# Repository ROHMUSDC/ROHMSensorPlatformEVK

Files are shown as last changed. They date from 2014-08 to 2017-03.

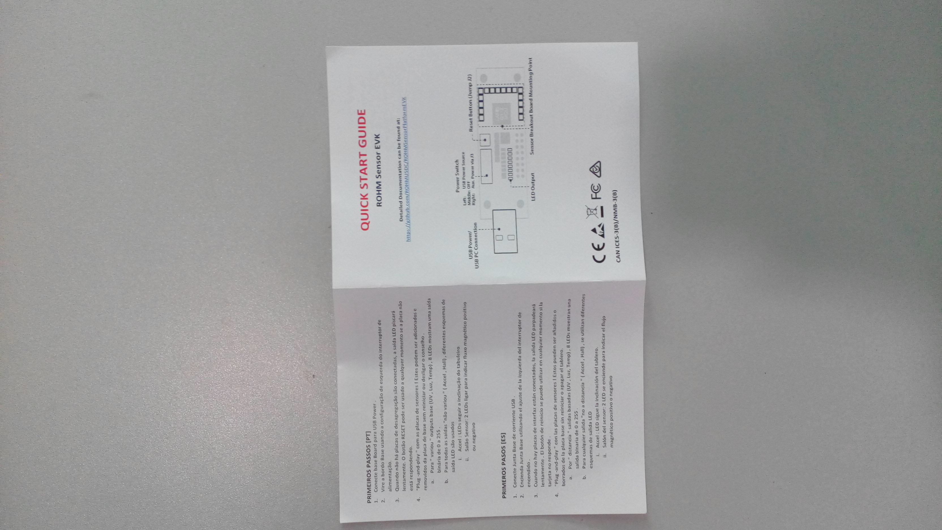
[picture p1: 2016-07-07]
Documentation/CE Declaration of Conformity/technical_documentation/[14]_Photos/IMG_20150430_091640[1].jpg

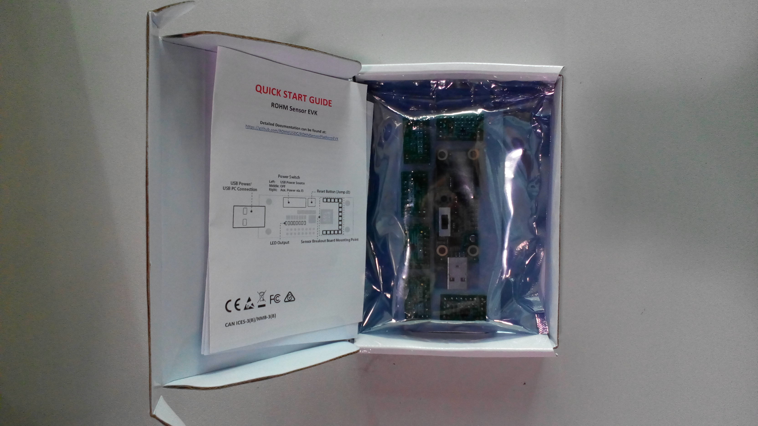
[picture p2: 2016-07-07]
Documentation/CE Declaration of Conformity/technical_documentation/[14]_Photos/IMG_20150430_091804.jpg

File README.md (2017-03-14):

# ROHM Sensor Platform Kit Public Repository
* Part Number: SENSEKIT2-EVK-101
* Description: An Open platform that can be used to quickly evaluate sensor products!
* Developer: USDC Applications Engineering Team, ROHM Semiconductor
* Date Started: November 2014
* ROHM Webpage: http://www.rohm.com/web/global/sensor-platform-kit
* Sensor Kit Promotional Video on EEWEB: http://www.eeweb.com/company-blog/rohm/sensor-platform-kit

----
### Repository Contents
* Documentation Folder: Contains Application Note, MCU Datasheet, and Platform Guide for connecting this board to other device platforms
* Firmware Folder: Contains the Source Code for the ML610Q112 firmware for the Sensor Platform Base Board
* Hardware Design Files: Contains BOM, Schematic, and Layout files for this project
* PC Evaluation Tools: Contains FTDI VCP drivers and a copy of Putty

----
### Updates
* NOTE: The ML8511 and the ML8511A are OBSOLETE parts with no recommended replacement. Even though we still support this part on shield and you can find information for this sensor here; please beware that this sensor is being obsoleted and should not be used for new design.
----
### Where to Purchase
* Digikey: http://www.digikey.com/product-detail/en/SENSEKIT2-EVK-101/SENSEKIT2-EVK-101-ND/5300443
* Mouser: http://www.mouser.com/search/ProductDetail.aspx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
* Farnell, Element 14: http://uk.farnell.com/rohm/sensekit2-evk-101/multi-sense-eval-kit/dp/2475523

----
### FAQ
* Question: 
  * "I would like to try a different initialization setting for one of the sensors.  How would I go about uploading new firmware to the sensor platform's base board?"
* Answer:  
  * It is possible to modify the existing firmware of the base board.
  * Please see the draft document entitled, “ROHM_HowToFlash-TestingGuide_SensorPlatformKit_2015-10-05” for detailed instructions on how to flash the existing base board.
    * Programming Guide Repository Location: …/ROHMSensorPlatformEVK/Documentation/Sensor Platform/ROHM_HowToFlash-TestingGuide_SensorPlatformKit_2015-10-05.pdf
  * Please note that the board’s default firmware source files can also be found in the Sensor Platform Repository:
    * Default Firmware Repository Folder Location: …/ROHMSensorPlatformEVK/Firmware - Base Board ML610Q112 Code
  * Finally, you will need LAPIS Semiconductor’s nanoEase programmer tool to debug and flash the base board.  This additional tool can be purchased on Digikey at the following link:
    * http://www.digikey.com/product-detail/en/NANO-EASE/NANO-EASE-ND/4576425
  * However, if you do not want to purchase the Lapis nanoEase programmer tool, another alternative would be to write some sample code for the platform you may be using.
    * For example, in the sensor kit repository (…/ROHMSensorPlatformEVK/Documentation/Other Platform Guides/ROHM_ConnectingSensorPlatform_Arduino.pdf) you will find a platform guide and Arduino code for using these sensors with the Arduino platform.  By running this, you can easily change your Arduino code and run with the initialization routines you would like to try with this sensor.

* Question:
  * "How to I save logs from this sensor kit?"
* Answer:
  * "Please see the closed Issue #2 in the issues tab of this repository.

----
### Software License
The following are categorized under the GNU General Public License, Version 3:
* Firmware Design. Includes LAPIS ML610Q112 MCU main.c C code

Copyright (C) 2015 USDC Applications Engineering Team, ROHM Semiconductor

This program is free software: you can redistribute it and/or 
modify it under the terms of the GNU General Public License as published 
by the Free Software Foundation, either version 3 of the License, or any 
later version.

This program is distributed in the hope that it will be useful,
but WITHOUT ANY WARRANTY; without even the implied warranty of
MERCHANTABILITY or FITNESS FOR A PARTICULAR PURPOSE.  See the
GNU General Public License for more details.

You should have received a copy of the GNU General Public License
along with this program.  If not, see <http://www.gnu.org/licenses/>.

----
### Hardware License
The following are categorized under the CERN Open Hardware Licence, Version 1.2:
* Hardware Design. Includes Schematic, BOM, Layout

Copyright (C) 2015 USDC Applications Engineering Team, ROHM Semiconductor

This repository contains free hardware design concepts: you can redistribute it and/or 
modify it under the terms of the CERN Open Hardware Licence as published 
by the CERN, either version 1.2 of the License, or any 
later version.

This hardware design is distributed in the hope that it will be useful,
but WITHOUT ANY WARRANTY; without even the implied warranty of
MERCHANTABILITY or FITNESS FOR A PARTICULAR PURPOSE.  See the
CERN Open Hardware Licence for more details.

You should have received a copy of the CERN Open Hardware Licence
along with this program.  If not, see <http://www.ohwr.org/licenses/cern-ohl/v1.2>.

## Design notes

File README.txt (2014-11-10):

ROHM Sensor Platform Kit Public Repository

Description: 
An Open platform that can be used to quickly evaluate sensor products!

Developer: 
USDC Applications Engineering Team, ROHM Semiconductor

Date Opened: 
November 2014

Application Note Information:
Name: ROHM_Sensor_Evaluation_Kit_User_Manual_REV00_2014-10-13.pdf
Location: "Documentation\Sensor Platform"

Schematic/BOM and Layout Files can be found under...
Location: Hardware Design Files Folder
Hardware Design Tools: Orcad Capture and Allegro

----------------------------------------------------------------------
The following are categorized under the GNU General Public License, Version 3
-Hardware Design. Includes Schematic, BOM, Layout
-Firmware Design. Includes LAPIS ML610Q112 MCU C code

Copyright (C) 2014 USDC Applications Engineering Team, ROHM Semiconductor

This program is free software and hardware: you can redistribute it and/or 
modify it under the terms of the GNU General Public License as published 
by the Free Software Foundation, either version 3 of the License, or any 
later version.

This program is distributed in the hope that it will be useful,
but WITHOUT ANY WARRANTY; without even the implied warranty of
MERCHANTABILITY or FITNESS FOR A PARTICULAR PURPOSE.  See the
GNU General Public License for more details.

You should have received a copy of the GNU General Public License
along with this program.  If not, see <http://www.gnu.org/licenses/>.
----------------------------------------------------------------------

                    GNU GENERAL PUBLIC LICENSE
                       Version 3, 29 June 2007

 Copyright (C) 2007 Free Software Foundation, Inc. <http://fsf.org/>
 Everyone is permitted to copy and distribute verbatim copies
 of this license document, but changing it is not allowed.

                            Preamble

  The GNU General Public License is a free, copyleft license for
software and other kinds of works.

  The licenses for most software and other practical works are designed
to take away your freedom to share and change the works.  By contrast,
the GNU General Public License is intended to guarantee your freedom to
share and change all versions of a program--to make sure it remains free
software for all its users.  We, the Free Software Foundation, use the
GNU General Public License for most of our software; it applies also to
any other work released this way by its authors.  You can apply it to
your programs, too.

  When we speak of free software, we are referring to freedom, not
price.  Our General Public Licenses are designed to make sure that you
have the freedom to distribute copies of free software (and charge for
them if you wish), that you receive source code or can get it if you
want it, that you can change the software or use pieces of it in new
free programs, and that you know you can do these things.

  To protect your rights, we need to prevent others from denying you
these rights or asking you to surrender the rights.  Therefore, you have
certain responsibilities if you distribute copies of the software, or if
you modify it: responsibilities to respect the freedom of others.

  For example, if you distribute copies of such a program, whether
gratis or for a fee, you must pass on to the recipients the same
freedoms that you received.  You must make sure that they, too, receive
or can get the source code.  And you must show them these terms so they
know their rights.

  Developers that use the GNU GPL protect your rights with two steps:
(1) assert copyright on the software, and (2) offer you this License
giving you legal permission to copy, distribute and/or modify it.

  For the developers' and authors' protection, the GPL clearly explains
that there is no warranty for this free software.  For both users' and
authors' sake, the GPL requires that modified versions be marked as
changed, so that their problems will not be attributed erroneously to
authors of previous versions.

  Some devices are designed to deny users access to install or run
modified versions of the software inside them, although the manufacturer
can do so.  This is fundamentally incompatible with the aim of
protecting users' freedom to change the software.  The systematic
pattern of such abuse occurs in the area of products for individuals to
use, which is precisely where it is most unacceptable.  Therefore, we
have designed this version of the GPL to prohibit the practice for those
products.  If such problems arise substantially in other domains, we
stand ready to extend this provision to those domains in future versions
of the GPL, as needed to protect the freedom of users.

  Finally, every program is threatened constantly by software patents.
States should not allow patents to restrict development and use of
software on general-purpose computers, but in those that do, we wish to
avoid the special danger that patents applied to a free program could
make it effectively proprietary.  To prevent this, the GPL assures that
patents cannot be used to render the program non-free.

  The precise terms and conditions for copying, distribution and
modification follow.

                       TERMS AND CONDITIONS

  0. Definitions.

  "This License" refers to version 3 of the GNU General Public License.

  "Copyright" also means copyright-like laws that apply to other kinds of
works, such as semiconductor masks.

  "The Program" refers to any copyrightable work licensed under this
License.  Each licensee is addressed as "you".  "Licensees" and
"recipients" may be individuals or organizations.

  To "modify" a work means to copy from or adapt all or part of the work
in a fashion requiring copyright permission, other than the making of an
exact copy.  The resulting work is called a "modified version" of the
earlier work or a work "based on" the earlier work.

  A "covered work" means either the unmodified Program or a work based
on the Program.

  To "propagate" a work means to do anything with it that, without
permission, would make you directly or secondarily liable for
infringement under applicable copyright law, except executing it on a
computer or modifying a private copy.  Propagation includes copying,
distribution (with or without modification), making available to the
public, and in some countries other activities as well.

  To "convey" a work means any kind of propagation that enables other
parties to make or receive copies.  Mere interaction with a user through
a computer network, with no transfer of a copy, is not conveying.

  An interactive user interface displays "Appropriate Legal Notices"
to the extent that it includes a convenient and prominently visible
feature that (1) displays an appropriate copyright notice, and (2)
tells the user that there is no warranty for the work (except to the
extent that warranties are provided), that licensees may convey the
work under this License, and how to view a copy of this License.  If
the interface presents a list of user commands or options, such as a
menu, a prominent item in the list meets this criterion.

  1. Source Code.

  The "source code" for a work means the preferred form of the work
for making modifications to it.  "Object code" means any non-source
form of a work.

  A "Standard Interface" means an interface that either is an official
standard defined by a recognized standards body, or, in the case of
interfaces specified for a particular programming language, one that
is widely used among developers working in that language.

  The "System Libraries" of an executable work include anything, other
than the work as a whole, that (a) is included in the normal form of
packaging a Major Component, but which is not part of that Major
Component, and (b) serves only to enable use of the work with that
Major Component, or to implement a Standard Interface for which an
implementation is available to the public in source code form.  A
"Major Component", in this context, means a major essential component
(kernel, window system, and so on) of the specific operating system
(if any) on which the executable work runs, or a compiler used to
produce the work, or an object code interpreter used to run it.

  The "Corresponding Source" for a work in object code form means all
the source code needed to generate, install, and (for an executable
work) run the object code and to modify the work, including scripts to
control those activities.  However, it does not include the work's
System Libraries, or general-purpose tools or generally available free
programs which are used unmodified in performing those activities but
which are not part of the work.  For example, Corresponding Source
includes interface definition files associated with source files for
the work, and the source code for shared libraries and dynamically
linked subprograms that the work is specifically designed to require,
such as by intimate data communication or control flow between those
subprograms and other parts of the work.

  The Corresponding Source need not include anything that users
can regenerate automatically from other parts of the Corresponding
Source.

  The Corresponding Source for a work in source code form is that
same work.

  2. Basic Permissions.

  All rights granted under this License are granted for the term of
copyright on the Program, and are irrevocable provided the stated
conditions are met.  This License explicitly affirms your unlimited
permission to run the unmodified Program.  The output from running a
covered work is covered by this License only if the output, given its
content, constitutes a covered work.  This License acknowledges your
rights of fair use or other equivalent, as provided by copyright law.

  You may make, run and propagate covered works that you do not
convey, without conditions so long as your license otherwise remains
in force.  You may convey covered works to others for the sole purpose
of having them make modifications exclusively for you, or provide you
with facilities for running those works, provided that you comply with
the terms of this License in conveying all material for which you do
not control copyright.  Those thus making or running the covered works
for you must do so exclusively on your behalf, under your direction
and control, on terms that prohibit them from making any copies of
your copyrighted material outside their relationship with you.

  Conveying under any other circumstances is permitted solely under
the conditions stated below.  Sublicensing is not allowed; section 10
makes it unnecessary.

  3. Protecting Users' Legal Rights From Anti-Circumvention Law.

  No covered work shall be deemed part of an effective technological
measure under any applicable law fulfilling obligations under article
11 of the WIPO copyright treaty adopted on 20 December 1996, or
similar laws prohibiting or restricting circumvention of such
measures.

  When you convey a covered work, you waive any legal power to forbid
circumvention of technological measures to the extent such circumvention
is effected by exercising rights under this License with respect to
the covered work, and you disclaim any intention to limit operation or
modification of the work as a means of enforcing, against the work's
users, your or third parties' legal rights to forbid circumvention of
technological measures.

  4. Conveying Verbatim Copies.

  You may convey verbatim copies of the Program's source code as you
receive it, in any medium, provided that you conspicuously and
appropriately publish on each copy an appropriate copyright notice;
keep intact all notices stating that this License and any
non-permissive terms added in accord with section 7 apply to the code;
keep intact all notices of the absence of any warranty; and give all
recipients a copy of this License along with the Program.

  You may charge any price or no price for each copy that you convey,
and you may offer support or warranty protection for a fee.

  5. Conveying Modified Source Versions.

  You may convey a work based on the Program, or the modifications to
produce it from the Program, in the form of source code under the
terms of section 4, provided that you also meet all of these conditions:

    a) The work must carry prominent notices stating that you modified
    it, and giving a relevant date.

    b) The work must carry prominent notices stating that it is
    released under this License and any conditions added under section
    7.  This requirement modifies the requirement in section 4 to
    "keep intact all notices".

    c) You must license the entire work, as a whole, under this
    License to anyone who comes into possession of a copy.  This
    License will therefore apply, along with any applicable section 7
    additional terms, to the whole of the work, and all its parts,
    regardless of how they are packaged.  This License gives no
    permission to license the work in any other way, but it does not
    invalidate such permission if you have separately received it.

    d) If the work has interactive user interfaces, each must display
    Appropriate Legal Notices; however, if the Program has interactive
    interfaces that do not display Appropriate Legal Notices, your
    work need not make them do so.

  A compilation of a covered work with other separate and independent
works, which are not by their nature extensions of the covered work,
and which are not combined with it such as to form a larger program,
in or on a volume of a storage or distribution medium, is called an
"aggregate" if the compilation and its resulting copyright are not
used to limit the access or legal rights of the compilation's users
beyond what the individual works permit.  Inclusion of a covered work
in an aggregate does not cause this License to apply to the other
parts of the aggregate.

  6. Conveying Non-Source Forms.

  You may convey a covered work in object code form under the terms
of sections 4 and 5, provided that you also convey the
machine-readable Corresponding Source under the terms of this License,
in one of these ways:

    a) Convey the object code in, or embodied in, a physical product
    (including a physical distribution medium), accompanied by the
    Corresponding Source fixed on a durable physical medium
    customarily used for software interchange.

    b) Convey the object code in, or embodied in, a physical product
    (including a physical distribution medium), accompanied by a
    written offer, valid for at least three years and valid for as
    long as you offer spare parts or customer support for that product
    model, to give anyone who possesses the object code either (1) a
    copy of the Corresponding Source for all the software in the
    product that is covered by this License, on a durable physical
    medium customarily used for software interchange, for a price no
    more than your reasonable cost of physically performing this
    conveying of source, or (2) access to copy the
    Corresponding Source from a network server at no charge.

    c) Convey individual copies of the object code with a copy of the
    written offer to provide the Corresponding Source.  This
    alternative is allowed only occasionally and noncommercially, and
    only if you received the object code with such an offer, in accord
    with subsection 6b.

    d) Convey the object code by offering access from a designated
    place (gratis or for a charge), and offer equivalent access to the
    Corresponding Source in the same way through the same place at no
    further charge.  You need not require recipients to copy the
    Corresponding Source along with the object code.  If the place to
    copy the object code is a network server, the Corresponding Source
    may be on a different server (operated by you or a third party)
    that supports equivalent copying facilities, provided you maintain
    clear directions next to the object code saying where to find the
    Corresponding Source.  Regardless of what server hosts the
    Corresponding Source, you remain obligated to ensure that it is
    available for as long as needed to satisfy these requirements.

    e) Convey the object code using peer-to-peer transmission, provided
    you inform other peers where the object code and Corresponding
    Source of the work are being offered to the general public at no
    charge under subsection 6d.

  A separable portion of the object code, whose source code is excluded
from the Corresponding Source as a System Library, need not be
included in conveying the object code work.

  A "User Product" is either (1) a "consumer product", which means any
tangible personal property which is normally used for personal, family,
or household purposes, or (2) anything designed or sold for incorporation
into a dwelling.  In determining whether a product is a consumer product,
doubtful cases shall be resolved in favor of coverage.  For a particular
product received by a particular user, "normally used" refers to a
typical or common use of that class of product, regardless of the status
of the particular user or of the way in which the particular user
actually uses, or expects or is expected to use, the product.  A product
is a consumer product regardless of whether the product has substantial
commercial, industrial or non-consumer uses, unless such uses represent
the only significant mode of use of the product.

  "Installation Information" for a User Product means any methods,
procedures, authorization keys, or other information required to install
and execute modified versions of a covered work in that User Product from
a modified version of its Corresponding Source.  The information must
suffice to ensure that the continued functioning of the modified object
code is in no case prevented or interfered with solely because
modification has been made.

  If you convey an object code work under this section in, or with, or
specifically for use in, a User Product, and the conveying occurs as
part of a transaction in which the right of possession and use of the
User Product is transferred to the recipient in perpetuity or for a
fixed term (regardless of how the transaction is characterized), the
Corresponding Source conveyed under this section must be accompanied
by the Installation Information.  But this requirement does not apply
if neither you nor any third party retains the ability to install
modified object code on the User Product (for example, the work has
been installed in ROM).

  The requirement to provide Installation Information does not include a
requirement to continue to provide support service, warranty, or updates
for a work that has been modified or installed by the recipient, or for
the User Product in which it has been modified or installed.  Access to a
network may be denied when the modification itself materially and
adversely affects the operation of the network or violates the rules and
protocols for communication across the network.

  Corresponding Source conveyed, and Installation Information provided,
in accord with this section must be in a format that is publicly
documented (and with an implementation available to the public in
source code form), and must require no special password or key for
unpacking, reading or copying.

  7. Additional Terms.

  "Additional permissions" are terms that supplement the terms of this
License by making exceptions from one or more of its conditions.
Additional permissions that are applicable to the entire Program shall
be treated as though they were included in this License, to the extent
that they are valid under applicable law.  If additional permissions
apply only to part of the Program, that part may be used separately
under those permissions, but the entire Program remains governed by
this License without regard to the additional permissions.

  When you convey a copy of a covered work, you may at your option
remove any additional permissions from that copy, or from any part of
it.  (Additional permissions may be written to require their own
removal in certain cases when you modify the work.)  You may place
additional permissions on material, added by you to a covered work,
for which you have or can give appropriate copyright permission.

  Notwithstanding any other provision of this License, for material you
add to a covered work, you may (if authorized by the copyright holders of
that material) supplement the terms of this License with terms:

    a) Disclaiming warranty or limiting liability differently from the
    terms of sections 15 and 16 of this License; or

    b) Requiring preservation of specified reasonable legal notices or
    author attributions in that material or in the Appropriate Legal
    Notices displayed by works containing it; or

    c) Prohibiting misrepresentation of the origin of that material, or
    requiring that modified versions of such material be marked in
    reasonable ways as different from the original version; or

    d) Limiting the use for publicity purposes of names of licensors or
    authors of the material; or

    e) Declining to grant rights under trademark law for use of some
    trade names, trademarks, or service marks; or

    f) Requiring indemnification of licensors and authors of that
    material by anyone who conveys the material (or modified versions of
    it) with contractual assumptions of liability to the recipient, for
    any liability that these contractual assumptions directly impose on
    those licensors and authors.

  All other non-permissive additional terms are considered "further
restrictions" within the meaning of section 10.  If the Program as you
received it, or any part of it, contains a notice stating that it is
governed by this License along with a term that is a further
restriction, you may remove that term.  If a license document contains
a further restriction but permits relicensing or conveying under this
License, you may add to a covered work material governed by the terms
of that license document, provided that the further restriction does
not survive such relicensing or conveying.

  If you add terms to a covered work in accord with this section, you
must place, in the relevant source files, a statement of the
additional terms that apply to those files, or a notice indicating
where to find the applicable terms.

  Additional terms, permissive or non-permissive, may be stated in the
form of a separately written license, or stated as exceptions;
the above requirements apply either way.

  8. Termination.

  You may not propagate or modify a covered work except as expressly
provided under this License.  Any attempt otherwise to propagate or
modify it is void, and will automatically terminate your rights under
this License (including any patent licenses granted under the third
paragraph of section 11).

  However, if you cease all violation of this License, then your
license from a particular copyright holder is reinstated (a)
provisionally, unless and until the copyright holder explicitly and
finally terminates your license, and (b) permanently, if the copyright
holder fails to notify you of the violation by some reasonable means
prior to 60 days after the cessation.

  Moreover, your license from a particular copyright holder is
reinstated permanently if the copyright holder notifies you of the
violation by some reasonable means, this is the first time you have
received notice of violation of this License (for any work) from that
copyright holder, and you cure the violation prior to 30 days after
your receipt of the notice.

  Termination of your rights under this section does not terminate the
licenses of parties who have received copies or rights from you under
this License.  If your rights have been terminated and not permanently
reinstated, you do not qualify to receive new licenses for the same
material under section 10.

  9. Acceptance Not Required for Having Copies.

  You are not required to accept this License in order to receive or
run a copy of the Program.  Ancillary propagation of a covered work
occurring solely as a consequence of using peer-to-peer transmission
to receive a copy likewise does not require acceptance.  However,
nothing other than this License grants you permission to propagate or
modify any covered work.  These actions infringe copyright if you do
not accept this License.  Therefore, by modifying or propagating a
covered work, you indicate your acceptance of this License to do so.

  10. Automatic Licensing of Downstream Recipients.

  Each time you convey a covered work, the recipient automatically
receives a license from the original licensors, to run, modify and
propagate that work, subject to this License.  You are not responsible
for enforcing compliance by third parties with this License.

  An "entity transaction" is a transaction transferring control of an
organization, or substantially all assets of one, or subdividing an
organization, or merging organizations.  If propagation of a covered
work results from an entity transaction, each party to that
transaction who receives a copy of the work also receives whatever
licenses to the work the party's predecessor in interest had or could
give under the previous paragraph, plus a right to possession of the
Corresponding Source of the work from the predecessor in interest, if
the predecessor has it or can get it with reasonable efforts.

  You may not impose any further restrictions on the exercise of the
rights granted or affirmed under this License.  For example, you may
not impose a license fee, royalty, or other charge for exercise of
rights granted under this License, and you may not initiate litigation
(including a cross-claim or counterclaim in a lawsuit) alleging that
any patent claim is infringed by making, using, selling, offering for
sale, or importing the Program or any portion of it.

  11. Patents.

  A "contributor" is a copyright holder who authorizes use under this
License of the Program or a work on which the Program is based.  The
work thus licensed is called the contributor's "contributor version".

  A contributor's "essential patent claims" are all patent claims
owned or controlled by the contributor, whether already acquired or
hereafter acquired, that would be infringed by some manner, permitted
by this License, of making, using, or selling its contributor version,
but do not include claims that would be infringed only as a
consequence of further modification of the contributor version.  For
purposes of this definition, "control" includes the right to grant
patent sublicenses in a manner consistent with the requirements of
this License.

  Each contributor grants you a non-exclusive, worldwide, royalty-free
patent license under the contributor's essential patent claims, to
make, use, sell, offer for sale, import and otherwise run, modify and
propagate the contents of its contributor version.

  In the following three paragraphs, a "patent license" is any express
agreement or commitment, however denominated, not to enforce a patent
(such as an express permission to practice a patent or covenant not to
sue for patent infringement).  To "grant" such a patent license to a
party means to make such an agreement or commitment not to enforce a
patent against the party.

  If you convey a covered work, knowingly relying on a patent license,
and the Corresponding Source of the work is not available for anyone
to copy, free of charge and under the terms of this License, through a
publicly available network server or other readily accessible means,
then you must either (1) cause the Corresponding Source to be so
available, or (2) arrange to deprive yourself of the benefit of the
patent license for this particular work, or (3) arrange, in a manner
consistent with the requirements of this License, to extend the patent
license to downstream recipients.  "Knowingly relying" means you have
actual knowledge that, but for the patent license, your conveying the
covered work in a country, or your recipient's use of the covered work
in a country, would infringe one or more identifiable patents in that
country that you have reason to believe are valid.

  If, pursuant to or in connection with a single transaction or
arrangement, you convey, or propagate by procuring conveyance of, a
covered work, and grant a patent license to some of the parties
receiving the covered work authorizing them to use, propagate, modify
or convey a specific copy of the covered work, then the patent license
you grant is automatically extended to all recipients of the covered
work and works based on it.

  A patent license is "discriminatory" if it does not include within
the scope of its coverage, prohibits the exercise of, or is
conditioned on the non-exercise of one or more of the rights that are
specifically granted under this License.  You may not convey a covered
work if you are a party to an arrangement with a third party that is
in the business of distributing software, under which you make payment
to the third party based on the extent of your activity of conveying
the work, and under which the third party grants, to any of the
parties who would receive the covered work from you, a discriminatory
patent license (a) in connection with copies of the covered work
conveyed by you (or copies made from those copies), or (b) primarily
for and in connection with specific products or compilations that
contain the covered work, unless you entered into that arrangement,
or that patent license was granted, prior to 28 March 2007.

  Nothing in this License shall be construed as excluding or limiting
any implied license or other defenses to infringement that may
otherwise be available to you under applicable patent law.

  12. No Surrender of Others' Freedom.

  If conditions are imposed on you (whether by court order, agreement or
otherwise) that contradict the conditions of this License, they do not
excuse you from the conditions of this License.  If you cannot convey a
covered work so as to satisfy simultaneously your obligations under this
License and any other pertinent obligations, then as a consequence you may
not convey it at all.  For example, if you agree to terms that obligate you
to collect a royalty for further conveying from those to whom you convey
the Program, the only way you could satisfy both those terms and this
License would be to refrain entirely from conveying the Program.

  13. Use with the GNU Affero General Public License.

  Notwithstanding any other provision of this License, you have
permission to link or combine any covered work with a work licensed
under version 3 of the GNU Affero General Public License into a single
combined work, and to convey the resulting work.  The terms of this
License will continue to apply to the part which is the covered work,
but the special requirements of the GNU Affero General Public License,
section 13, concerning interaction through a network will apply to the
combination as such.

  14. Revised Versions of this License.

  The Free Software Foundation may publish revised and/or new versions of
the GNU General Public License from time to time.  Such new versions will
be similar in spirit to the present version, but may differ in detail to
address new problems or concerns.

  Each version is given a distinguishing version number.  If the
Program specifies that a certain numbered version of the GNU General
Public License "or any later version" applies to it, you have the
option of following the terms and conditions either of that numbered
version or of any later version published by the Free Software
Foundation.  If the Program does not specify a version number of the
GNU General Public License, you may choose any version ever published
by the Free Software Foundation.

  If the Program specifies that a proxy can decide which future
versions of the GNU General Public License can be used, that proxy's
public statement of acceptance of a version permanently authorizes you
to choose that version for the Program.

  Later license versions may give you additional or different
permissions.  However, no additional obligations are imposed on any
author or copyright holder as a result of your choosing to follow a
later version.

  15. Disclaimer of Warranty.

  THERE IS NO WARRANTY FOR THE PROGRAM, TO THE EXTENT PERMITTED BY
APPLICABLE LAW.  EXCEPT WHEN OTHERWISE STATED IN WRITING THE COPYRIGHT
HOLDERS AND/OR OTHER PARTIES PROVIDE THE PROGRAM "AS IS" WITHOUT WARRANTY
OF ANY KIND, EITHER EXPRESSED OR IMPLIED, INCLUDING, BUT NOT LIMITED TO,
THE IMPLIED WARRANTIES OF MERCHANTABILITY AND FITNESS FOR A PARTICULAR
PURPOSE.  THE ENTIRE RISK AS TO THE QUALITY AND PERFORMANCE OF THE PROGRAM
IS WITH YOU.  SHOULD THE PROGRAM PROVE DEFECTIVE, YOU ASSUME THE COST OF
ALL NECESSARY SERVICING, REPAIR OR CORRECTION.

  16. Limitation of Liability.

  IN NO EVENT UNLESS REQUIRED BY APPLICABLE LAW OR AGREED TO IN WRITING
WILL ANY COPYRIGHT HOLDER, OR ANY OTHER PARTY WHO MODIFIES AND/OR CONVEYS
THE PROGRAM AS PERMITTED ABOVE, BE LIABLE TO YOU FOR DAMAGES, INCLUDING ANY
GENERAL, SPECIAL, INCIDENTAL OR CONSEQUENTIAL DAMAGES ARISING OUT OF THE
USE OR INABILITY TO USE THE PROGRAM (INCLUDING BUT NOT LIMITED TO LOSS OF
DATA OR DATA BEING RENDERED INACCURATE OR LOSSES SUSTAINED BY YOU OR THIRD
PARTIES OR A FAILURE OF THE PROGRAM TO OPERATE WITH ANY OTHER PROGRAMS),
EVEN IF SUCH HOLDER OR OTHER PARTY HAS BEEN ADVISED OF THE POSSIBILITY OF
SUCH DAMAGES.

  17. Interpretation of Sections 15 and 16.

  If the disclaimer of warranty and limitation of liability provided
above cannot be given local legal effect according to their terms,
reviewing courts shall apply local law that most closely approximates
an absolute waiver of all civil liability in connection with the
Program, unless a warranty or assumption of liability accompanies a
copy of the Program in return for a fee.

                     END OF TERMS AND CONDITIONS

            How to Apply These Terms to Your New Programs

  If you develop a new program, and you want it to be of the greatest
possible use to the public, the best way to achieve this is to make it
free software which everyone can redistribute and change under these terms.

  To do so, attach the following notices to the program.  It is safest
to attach them to the start of each source file to most effectively
state the exclusion of warranty; and each file should have at least
the "copyright" line and a pointer to where the full notice is found.

    <one line to give the program's name and a brief idea of what it does.>
    Copyright (C) <year>  <name of author>

    This program is free software: you can redistribute it and/or modify
    it under the terms of the GNU General Public License as published by
    the Free Software Foundation, either version 3 of the License, or
    (at your option) any later version.

    This program is distributed in the hope that it will be useful,
    but WITHOUT ANY WARRANTY; without even the implied warranty of
    MERCHANTABILITY or FITNESS FOR A PARTICULAR PURPOSE.  See the
    GNU General Public License for more details.

    You should have received a copy of the GNU General Public License
    along with this program.  If not, see <http://www.gnu.org/licenses/>.

Also add information on how to contact you by electronic and paper mail.

  If the program does terminal interaction, make it output a short
notice like this when it starts in an interactive mode:

    <program>  Copyright (C) <year>  <name of author>
    This program comes with ABSOLUTELY NO WARRANTY; for details type `show w'.
    This is free software, and you are welcome to redistribute it
    under certain conditions; type `show c' for details.

The hypothetical commands `show w' and `show c' should show the appropriate
parts of the General Public License.  Of course, your program's commands
might be different; for a GUI interface, you would use an "about box".

  You should also get your employer (if you work as a programmer) or school,
if any, to sign a "copyright disclaimer" for the program, if necessary.
For more information on this, and how to apply and follow the GNU GPL, see
<http://www.gnu.org/licenses/>.

  The GNU General Public License does not permit incorporating your program
into proprietary programs.  If your program is a subroutine library, you
may consider it more useful to permit linking proprietary applications with
the library.  If this is what you want to do, use the GNU Lesser General
Public License instead of this License.  But first, please read
<http://www.gnu.org/philosophy/why-not-lgpl.html>.

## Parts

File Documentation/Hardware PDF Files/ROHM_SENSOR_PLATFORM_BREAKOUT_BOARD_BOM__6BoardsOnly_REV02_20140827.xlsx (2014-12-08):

Sensor Platform - Breakout Board Schematics
Revision 01
Bill Of Materials
Item | Quantity | Reference | Part | PCB Footprint | DESCRIPTION | MFG1 | MFG1_PART# | DISTR1 | DISTR1_PART# | DNP
1 | 7 | C6,C7,C20,C22,C23,C35,C50 | 0.1uF | C0402 | CAP CER 0.1UF 10V 10% X5R 0402 | Murata | GRM155R61A104KA01D | DIGIKEY | 490-1318-1-ND
2 | 4 | C9,C24 | 1uF | C0402 | CAP CER 1UF 6.3V 10% X5R 0402 | Murata | GRM155R60J105KE19D | DIGIKEY | 490-1320-1-ND
3 | 1 | C21 | 1nF | C0402 | CAP CER 1000PF 50V 10% X7R 0402 | Murata | GRM155R71H102KA01D | DIGIKEY | 490-1303-1-ND
4 | 1 | C78 | 22uF | C0805 | CAP CER 22UF 6.3V 20% X5R 0805 | Samsung Electro-Mechanics America, Inc | CL21A226MQQNNNE | DIGIKEY | 1276-1100-1-ND
5 | 2 | J6,J7 | 3-PIN Jumper | HDR_THVT_1X3_100 | BERGSTIK II .100" SR STRAIGHT | FCI | 68000-103HLF | DIGIKEY | 609-3461-ND
6 | 3 | R22 | 1K | R0402 | RES 1K OHM 1/16W 1% 0402 SMD | Rohm | MCR01MRTF1001 | DIGIKEY | RHM1.00KCDCT-ND
7 | 11 | R130,R162,R167,R169,R188,R198,R200,R213,R234,R235,R237 | 0 | R0603 | RES 0.0 OHM 1/10W JUMP 0603 SMD | Rohm | MCR03ERTJ000 | DIGIKEY | RHM0.0CGTR-ND
8 | 3 | R32 | 10K | R0402 | RES 10K OHM 1/16W 1% 0402 SMD | Rohm | MCR01MRTF1002 | DIGIKEY | RHM10.0KCDCT-ND
9 | 1 | R129 | 4.7K | R0603 | RES 4.7K OHM 1/10W 1% 0603 SMD | Rohm | MCR03ERTF4701 | DIGIKEY | RHM4.70KCFCT-ND
10 | 1 | R132 | 5.6K | R0402 | RES 5.6K OHM 1/16W 1% 0402 SMD | Rohm | TRR01MZPF5601 | DIGIKEY | RHM5.6KBHCT-ND
11 | 12 | U9,U12,U50,U58,U65,U111,U11,U14,U46,U60,U67,U113 | SensorInterfaceHeader_1 | HDR_THVT_1X5_100 | CONN HEADER VERT SGL 5POS GOLD | 3M | 961105-6404-AR | DIGIKEY | 3M9450-ND
13 | 6 | U16,U17,U32,U52,U61,U112 | SensorInterfaceHeader_3 | HDR_THVT_1X6_100 | CONN HEADER VERT SGL 6POS GOLD | 3M | 961106-6404-AR | DIGIKEY | 3M9451-ND
14 | 1 | U13 | BH1721FVC | WSOF5 | IC AMBIENT LIGHT SENSOR WSOF5 | Rohm | BH1721FVC-TR | DIGIKEY | BH1721FVCCT-ND
15 | 1 | U10 | BH1620FVC | WSOF5 | IC AMBIENT LIGHT SENSOR WSOF5 | Rohm | BH1620FVC-TR | DIGIKEY | BH1620FVCCT-ND
20 | 1 | U51 | BDE0600G | SSOP5 | IC TEMP SENSOR THERM 60°C SSOP5 | Rohm | BDE0600G-TR | DIGIKEY | BDE0600GCT-ND
22 | 1 | U59 | ML8511 | TQFN12 | UV SENSOR W/AMP TQFN12 | Rohm | ML8511-00FCZ05B | DIGIKEY | ML8511-00FCZ05BCT-ND
24 | 1 | U66 | KMX61 | LGA_3x3x0P9 | MAGNETOMETER AND ACCELEROMETER TRI-AXIS LGA16 | Kionix/Rohm | KMX61 | TBD | TBD
26 | 1 | U110 | BU52011HFV | HVSOF5 | IC HALL EFFECT SW BIPO HVSOF5 | Rohm | BU52011HFV-TR | DIGIKEY | BU52011HFVCT-ND
28 | 2 |  |  |  | Shunt jumper for header J6, J7 (item #5), CONN SHUNT 2POS GOLD W/HANDLE | TE Connectivity | 881545-1 | DIGIKEY | 881545-1-ND
29 | 27 | R128,R161,R163,R164,R165,R166,R168,R170,R171,R172,R185,R186,R187,R189,R190,R197,R199,R201,R202,R209,R210,R211,R212,R214,R233,R236,R238 | 0 | R0603 | RES 0.0 OHM 1/10W JUMP 0603 SMD | Rohm | MCR03ERTJ000 | DIGIKEY | RHM0.0CGTR-ND | Do Not Place
30 | 1 | R131 | 4.7K | R0603 | RES 4.7K OHM 1/10W 1% 0603 SMD | Rohm | MCR03ERTF4701 | DIGIKEY | RHM4.70KCFCT-ND | Do Not Place

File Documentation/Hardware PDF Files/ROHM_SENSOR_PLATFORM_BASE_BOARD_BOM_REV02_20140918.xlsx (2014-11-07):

Sensor Platform - Base Board BOM
Revision: 02.0
Bill Of Materials
Item | Quantity | Reference | Part | PCB Footprint | DESCRIPTION | MFG1 | MFG1_PART# | DISTR1 | DISTR1_PART# | DNP | Provided by ROHM | ROHM Comment
1 | 2 | C1,C3 | 0.47uF | C0402 | CAP CER 0.47UF 6.3V 10% X5R 0402 | Samsung Electro-Mechanics America, Inc | CL05A474KQ5NNNC | DIGIKEY | 1276-1479-1-ND |  | No
2 | 3 | C4,C30,C33 | 0.01uF | C0402 | CAP CER 10000PF 25V 10% X7R 0402 | Taiyo Yuden | TMK105B7103KV-F | DIGIKEY | 587-1223-1-ND |  | No
3 | 1 | C5 | 4.7uF | C0402 | CAP CER 4.7UF 6.3V 20% X5R 0402 | Murata | GRM155R60J475ME47D | DIGIKEY | 490-5915-1-ND |  | No
4 | 1 | C27 | 4.7uF | SM_4P3x4P3 | CAP ALUM 4.7UF 25V 20% SMD | Nichicon | UUT1E4R7MCL1GS | DIGIKEY | 493-6252-1-ND |  | No
5 | 3 | C28,C29,C34 | 0.1uF | C0402 | CAP CER 0.1UF 10V 10% X5R 0402 | Murata | GRM155R61A104KA01D | DIGIKEY | 490-1318-1-ND |  | No
6 | 2 | C31,C32 | 47pF | C0402 | CAP CER 47PF 50V 1% NP0 0402 | Murata | GRM1555C1H470FA01D | DIGIKEY | 490-6241-1-ND |  | No
7 | 1 | D1 | 20V 3A | SOD-123F | DIODE SCHOTTKY 20V 3A PMDU | Rohm | RB051M-2YTR | DIGIKEY | RB051M-2YCT-ND |  | Yes
8 | 8 | D8,D9,D10,D11,D12,D13,D14,D15 | SML-P11VTT86 | LED0402 | LED 0402 RED 50MW 20MA SMD | Rohm | SML-P11VTT86 | DIGIKEY | 511-1654-1-ND |  | Yes
9 | 1 | D16 | Dual LED | LED0404-DUAL | LED PICOLED DUAL YWGN/RED 1010 | Rohm | SML-P24MUWT86 | Digi-Key | 846-1040-1-ND |  | Yes
10 | 1 | FB1 | 600R/1A | FB0603 | FERRITE CHIP POWER 600 OHM SMD | Laird-Signal Integrity Products | MI0603J601R-10 | DIGIKEY | 240-2371-1-ND |  | No
11 | 1 | J1 | 3 Position Switch | SW_16X6P8_MM | SWITCH MINIATURE SLIDE 30V | Apem | MHS123 | DIGIKEY | 679-1840-ND |  | No
12 | 1 | J2 | 3-PIN Jumper | HDR_THVT_1X3_100 | BERGSTIK II .100" SR STRAIGHT | FCI | 68000-103HLF | DIGIKEY | 609-3461-ND |  | No
13 | 1 | J3 | 2 Position Male Header: External Power | HDR_THVT_1X2_100 | BERGSTIK II .100" SR STRAIGHT | FCI | 68000-102HLF | DIGIKEY | 609-3500-ND |  | No
14 | 1 | J4 | DEBUG | HDR_THVT_2X2_100 | CONN HEADER 4POS .100 STR 30AU | FCI | 67996-104HLF | DIGIKEY | 609-3201-ND |  | No
15 | 1 | J8 | USB Type A Plug | CONN_USB_A_SMD_RA | CONN PLUG USB A 4POS SMD R/A | Molex | 480372200 | DIGIKEY | WM3983TR-ND |  | No
16 | 1 | LED1 | SML-210MTT86 | LED0805 | LED 570NM GREEN WTR CLR 0805 SMD | Rohm | SML-210MTT86 | DIGIKEY | 511-1287-2-ND |  | Yes
17 | 1 | LED2 | SML-210YTT86 | LED0805 | LED 585NM YLW WTR CLR 0805 SMD | Rohm | SML-210YTT86 | DIGIKEY | 511-1290-2-ND |  | Yes
18 | 11 | R1,R3,R6,R7,R36,R149,R150,R151,R152,R153,R154 | 10K | R0402 | RES 10K OHM 1/16W 1% 0402 SMD | Rohm | MCR01MRTF1002 | DIGIKEY | RHM10.0KCDCT-ND |  | Yes
19 | 2 | R2,R5 | 0 | R0603 | RES 0.0 OHM 1/10W JUMP 0603 SMD | Rohm | MCR03ERTJ000 | DIGIKEY | RHM0.0CGTR-ND |  | Yes
20 | 1 | R4 | 20K | R0402 | RES 20K OHM 1/16W 1% 0402 SMD | Rohm | MCR01MRTF2002 | DIGIKEY | RHM20.0KCDCT-ND |  | Yes
21 | 8 | R14,R15,R16,R17,R18,R19,R20,R21 | 1.5K | R0402 | RES 1.5K OHM 1/16W 1% 0402 SMD | Rohm | MCR01MRTF1501 | DIGIKEY | RHM1.50KCDCT-ND |  | Yes
22 | 2 | R37,R38 | 270R | R0402 | RES 270 OHM 1/16W 5% 0402 SMD | Rohm | MCR01MRTJ271 | DIGIKEY | RHM270CECT-ND |  | Yes
23 | 2 | R39,R40 | 27R | R0402 | RES 27 OHM 1/16W 5% 0402 SMD | Rohm | MCR01MRTJ270 | DIGIKEY | RHM27CECT-ND |  | Yes
24 | 1 | R41 | 15K | R0402 | RES 15K OHM 1/16W 1% 0402 SMD | Rohm | MCR01MRTF1502 | DIGIKEY | RHM15.0KCDCT-ND |  | Yes
25 | 2 | R155,R156 | 240 | R0402 | RES 240 OHM 1/16W 1% 0402 SMD | Rohm | TRR01MZPF2400 | Digi-Key | RHM24BHCT-ND |  | Yes
26 | 1 | S1 | Momentary Push-Button (N/O) | SW_6X6_MM | SWITCH TACTILE SPST-NO 0.05A 12V | TE Connectivity | 1825910-6 | DIGIKEY | 450-1650-ND |  | No
27 | 1 | U1 | BU33TD3WG-TR | SSOP5 | IC REG LDO 3.3V 0.2A SSOP5 | Rohm | BU33TD3WG-TR | DIGIKEY | BU33TD3WGCT-ND |  | Yes
28 | 1 | U2 | SensorInterfaceHeader_2 | CONN_THVT_1X5_100 | CONN SOCKET SGL VERT 5POS GOLD | 3M | 960105-6202-AR | DIGIKEY | 3M9516-ND |  | No
29 | 1 | U3 | SensorInterfaceHeader_1 | CONN_THVT_1X5_100 | CONN SOCKET SGL VERT 5POS GOLD | 3M | 960105-6202-AR | DIGIKEY | 3M9516-ND |  | No
30 | 1 | U4 | ML610Q112 | LQFP32 | IC MCU 8BIT 24KB FLASH 32LQFP | Rohm | ML610Q112-NNNTCZ07FL | DIGIKEY | ML610Q112-NNNTCZ0-ND |  | Yes
31 | 1 | U5 | SensorInterfaceHeader_3 | CONN_THVT_1X6_100 | CONN SOCKET SGL VERT 6POS GOLD | 3M | 960106-6202-AR | DIGIKEY | 3M9517-ND |  | No
32 | 1 | U70 | FT230XS-R | SSOP16 | IC USB SERIAL BASIC UART 16SSOP | FTDI | FT230XS-R | DIGIKEY | 768-1135-1-ND |  | No
33 | 1 |  |  |  | Shunt jumper for header J2 (item #12), CONN SHUNT 2POS GOLD W/HANDLE | TE Connectivity | 881545-1 | DIGIKEY | 881545-1-ND |  | No
34 | 1 | J5 | 16 I/O Pins Q112 | HDR_THVT_2X8_100 | CONN PCB 8x2_.100" |  |  |  |  | Do Not Place

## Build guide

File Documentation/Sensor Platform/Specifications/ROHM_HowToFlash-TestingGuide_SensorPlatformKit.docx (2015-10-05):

# Firmware Flashing and Initial Hardware Check Guide for

# ROHM’s Sensor Platform Kit

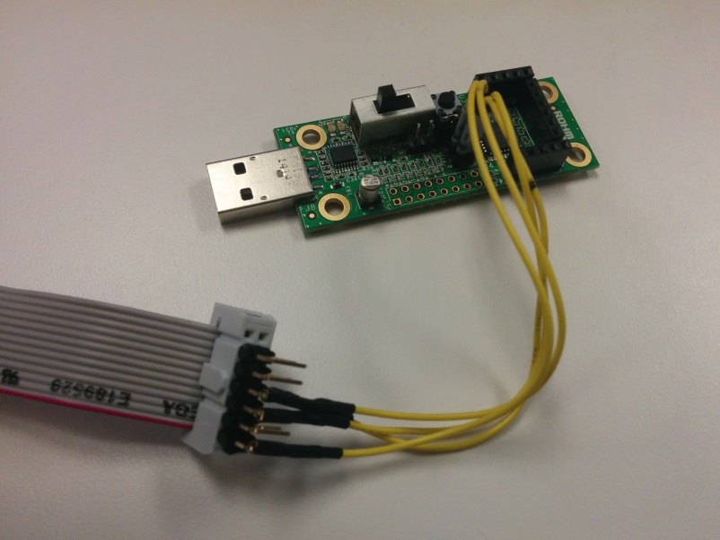
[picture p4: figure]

Above: ROHM Sensor Platform base board connected ROHM nanoEase Cable for Firmware Flash

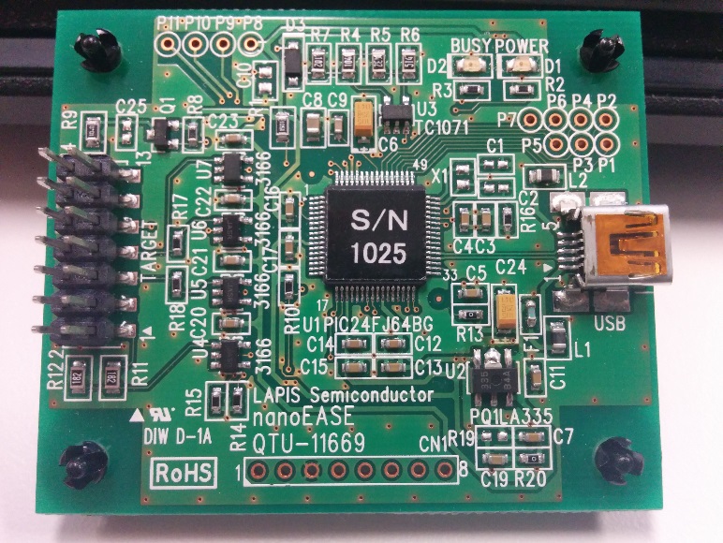
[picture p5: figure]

Above: nanoEase Programmer Board required for flashing the LAPIS Microcontroller Boards

05 October 2015, Revision A

# Revision History

Date | Description | Revision ID
27 January 2015 | First Draft | A

# Introduction

The following document was written to provide an explanation to how to flash the firmware for these sensor platform boards with the most recent firmware. Also, this guide will go into the details of how to check the hardware assemblies of these boards.

For other guides, such as operation manuals and other platform connection tutorials, please visit our public repository at the following link…

ROHM’s Sensor Platform Kit: https://github.com/ROHMUSDC/ROHMSensorPlatformEVK

- ROHM BH1721 – Digital Ambient Light Sensor
- ROHM BH1620 – Analog Ambient Light Sensor
- ROHM BU52011HFV – Hall Switch Sensor
- ROHM BDE0600G – Analog Temperature Sensor
- LAPIS ML8511 – Analog UV Sensor
- Kionix KMX061 – Digital Accelerometer and Magnetometer

# Tools Required for Getting Started

The Base board for the Sensor Platform Kit uses a LAPIS ML610Q112 Microcontroller as the main application processor for this kit. Please note, that this board does not come with any on-board programming chip; therefore, in order to successfully flash this MCU, you will need a “uEase” or “nanoEase” programmer/debugger board. These can be found at the following link:

uEase MCU programmer and Debugger Hardware:

http://www.digikey.com/product-search/en?x=0&y=0&lang=en&site=us&keywords=uEase

Please note that you will also need to register and login to the Lapis Support Site in order to download the software tools required for flashing this device.

LAPIS Support Site Login/Registration Page:

https://www.lapis-semi.com/cgi-bin/MyLAPIS/regi/login.cgi

Once you’ve logged into the support suite, click the “Development Support System” link on the left side of the screen.

After this page has loaded, please download the latest version of the “U8 Development Tools”. This Software package includes the application named “FWuEASE Flash Writer” and “IDEU8 GUI Environment”. Either application can be used to flash the sensor platform base boards. IDEU8 would be used to develop code and program/debug. The FWuEASE flash writer can be used to program HEX files direct to the MCU Base board. See the picture below for the software package that should be downloaded after registering for the LAPIS Development Support Site:

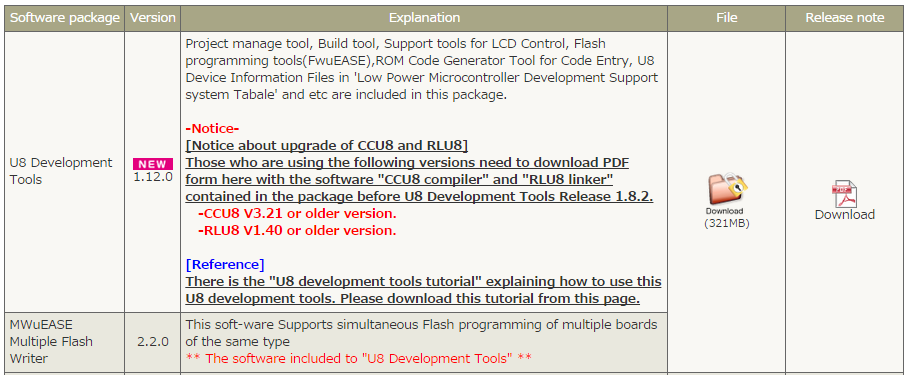
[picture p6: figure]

# Loading the HEX firmware files to Sensor Platform Base Kit

This section should be referred to if the user only wants to load an already generated HEX file into the existing base board. If the user wants to adjust source code and test/debug their code, please skip forward to the section entitled, “Programming and Debugging the Sensor Platform Base Kit”.

1. Acquire a “uEase” or “nanoEase” programmer/debugger board and install the FWuEASE Flash Writer as explained in the previous section.
2. Connect the “uEase” or “nanoEase” programmer/debugger board to the sensor platform base board
  a. On the Sensor Platform Base board, we will want to connect to pin header J4 (2x2 header pin row)

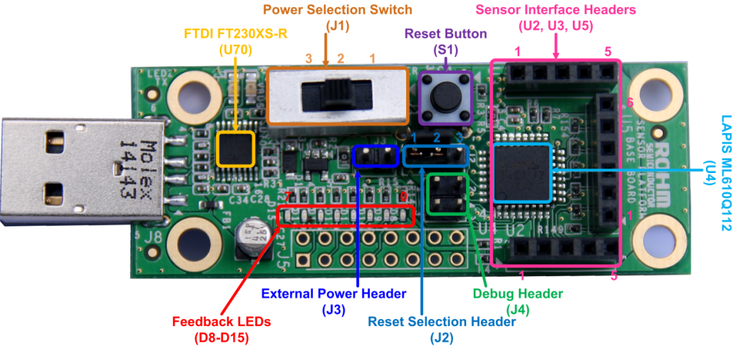
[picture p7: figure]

  b. On the uEase of nanoEase programmer boards, we will want to isolate 4 pins (VDD, GND, TST, and RST). Then, we recommend building a jumper cable to make the connection easier to re-connect. See below for schematics for this debug port and an example debug port connector we used to flash these boards

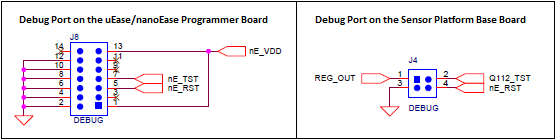
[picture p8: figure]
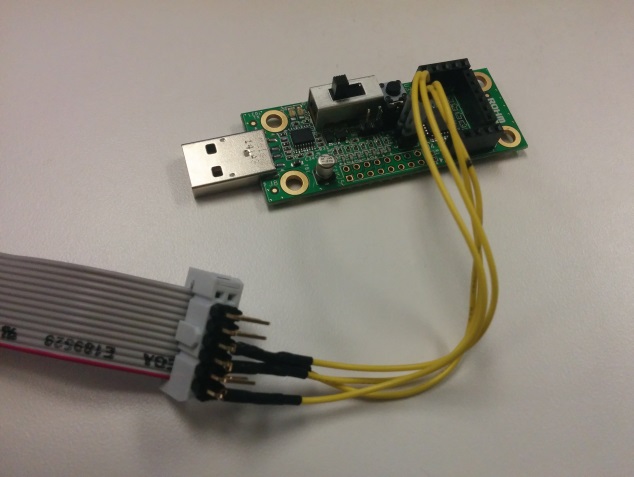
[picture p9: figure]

3. Move the Jumper on the J2 connector to connect the top two pins (looking at the base board with the sensor interface connector on top).
  a. This will change the connection of the reset pin on the board from the PB (S1) to the programmer.
4. Connect the uEase/nanoEase board to the PC using a mini USB cable.
5. Download the latest HEX programming file for the latest revision firmware
  a. This can be found at the GitHub repository page at the following link
    i. https://github.com/ROHMUSDC/ROHMSensorPlatformEVK
  b. Please note that this can be found in the following folder hierarchy
    i. …ROHMSensorPlatformEVK/Firmware - Base Board ML610Q112 Code/_output/_hex
  c. Name of the file should be as follows
    i. “Q112-SENSORPLATFORMEVK.HEX”
  d. Be sure to save this file somewhere where you can find it later as it will be the main file used to program these boards.
6. Next, open the newly installed “FWuEASE” software. When opening this application for the first time, an error message may occur that asks you to choose a target device. Choose “ML610112” then click OK

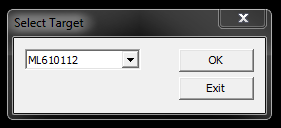
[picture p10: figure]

7. After clicking OK above, the main application window will open. It should look like the following…

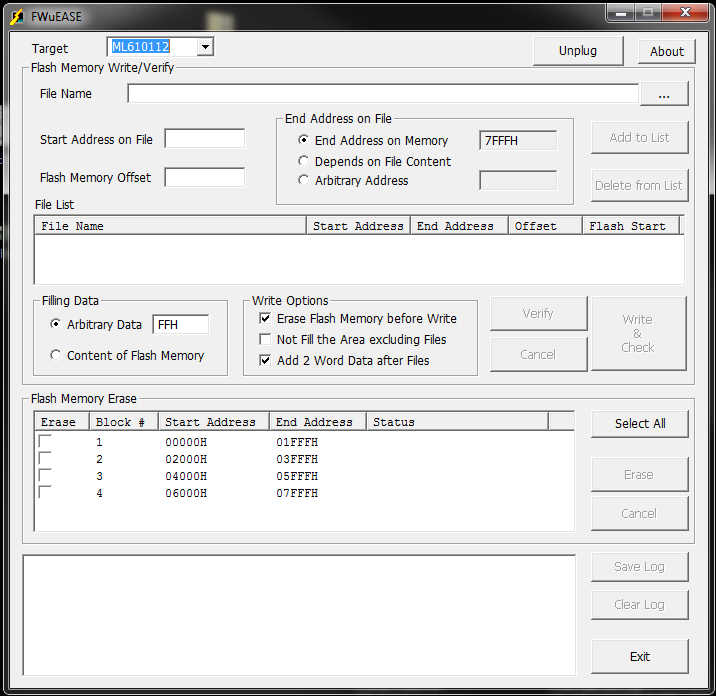
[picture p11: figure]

8. Next, click the “…” button to the right of the “File Name” field. Browse and load the HEX file saved from step 5. Click OK and the window should look like the following

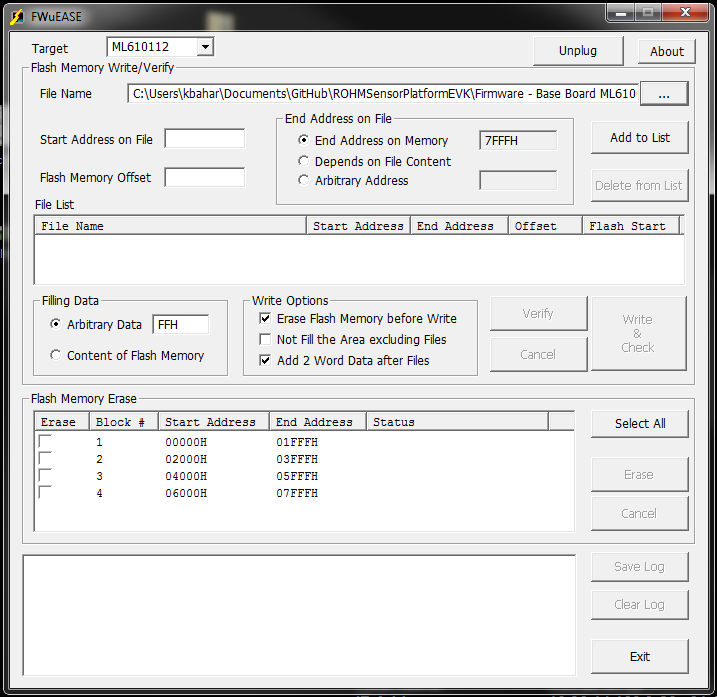
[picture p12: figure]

9. Next, click the “Add to List” button. Also, confirm that the other setting options match the window below.

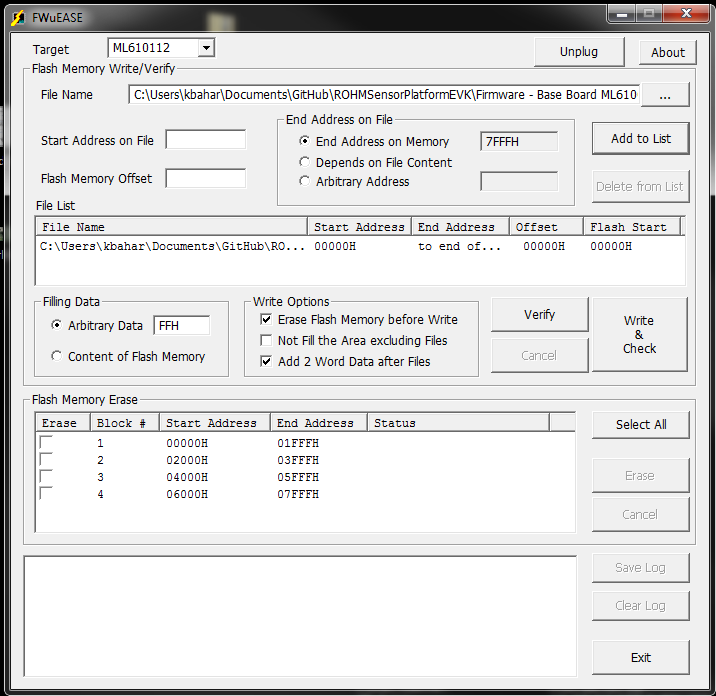
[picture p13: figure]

10. Finally, when ready to program the device, click the “Write & Check Button. Writing will take a couple seconds to complete. Upon completion, the status output will look like the following…

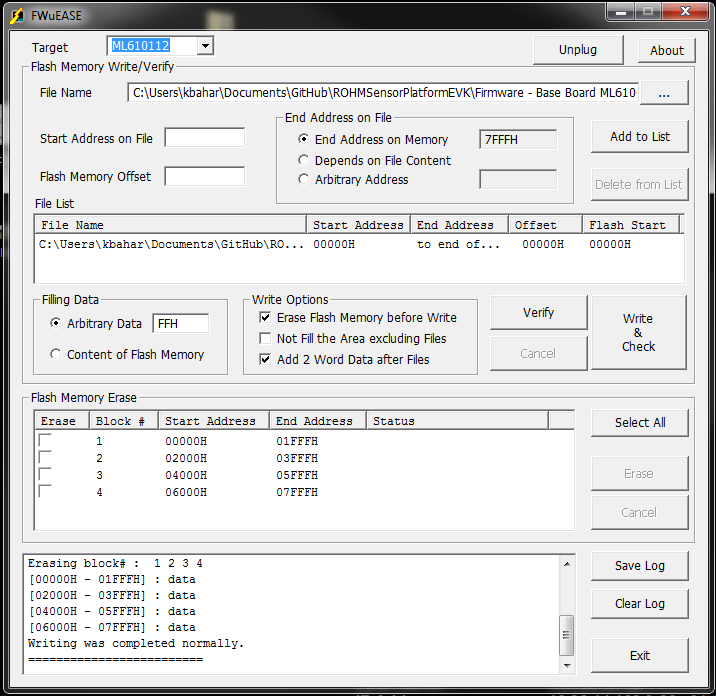
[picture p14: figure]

11. If you see the above message, then you have successfully flashed the hardware of this device!

# Programming and Debugging the Sensor Platform Base Kit

1. Acquire a “uEase” or “nanoEase” programmer/debugger board and install the IDEU8 GUI Development Environment as explained in the “Tools Required for Getting Started” section above.
2. Connect the “uEase” or “nanoEase” programmer/debugger board to the sensor platform base board
  a. On the Sensor Platform Base board, we will want to connect to pin header J4 (2x2 header pin row)
  b. On the uEase of nanoEase programmer boards, we will want to isolate 4 pins (VDD, GND, TST, and RST). Then, we recommend building a jumper cable to make the connection easier to re-connect. See below for schematics for this debug port and an example debug port connector we used to flash these boards
3. Move the Jumper on the J2 connector to connect the top two pins (looking at the base board with the sensor interface connector on top).
  a. This will change the connection of the reset pin on the board from the PB (S1) to the programmer.
4. Connect the uEase/nanoEase board to the PC using a mini USB cable.
5. Next, open the newly installed IDEU8 GUI Development Environment and open up your target MCU’s source code
  a. If you’re just getting started you can view and download the base revision of the code by downloading the firmware example from the following repository page:
    i. https://github.com/ROHMUSDC/ROHMSensorPlatformEVK
    ii. …/ROHMSensorPlatformEVK/Firmware - Base Board ML610Q112 Code
6. Next, adjust the code as required for your application and then confirm that the application complies properly by using the “Rebuild” button

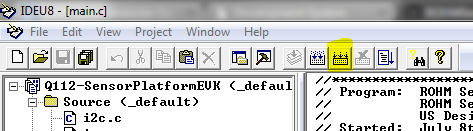
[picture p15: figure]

  b. OR… Project -> Rebuild
7. Finally, you can program the base board by pressing the “debug” button

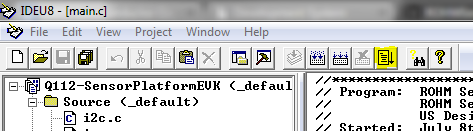
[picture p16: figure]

  b. OR… Project -> Debug
  c. OR… CTRL+F5
8. After the IDEU8 completes building sucessfully, you will see the following message in the console and a new target settings window will appear. Adjust these to the following:
  a. Successful Build Message:
  b. Target Settings to use for the base board:

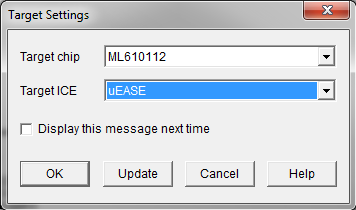
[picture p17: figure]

    ii. Note: uEASE can be chosen if a uEASE programmer is being used. However, nanoEase should be chosen if a nanoEASE programmer is being used.
9. After setting the target settings, the DTU8 debugger will be open with the code used to program the base board with.
  a. Run the code using the “F5” key
  b. Additional run commands can be found in the “Run” menu (Pause, stop, step in, step out, etc…)
  c. Breakpoints can also be added to code by checking the “BP” box in the actual code itself

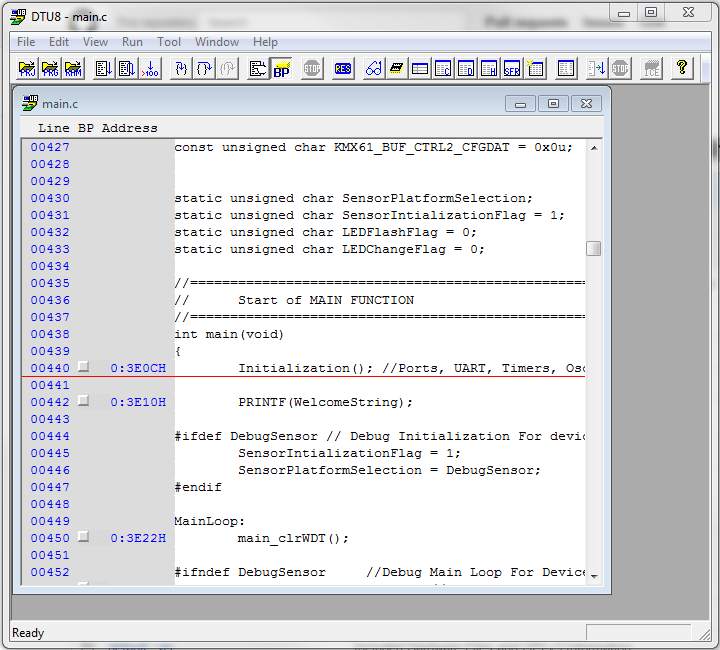
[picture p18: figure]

10. When you unplug from the debugger board, the last code that was debugged will run on the base board platform. So, feel free to disconnect and connect again to test and build the application up to your liking!

# Performing a Functional Check for After Assembly

When performing a functional check of the sensor platform kit boards, we will want to check each of the following aspects of the board

- Base Board Power Connection via USB
- Base Board Standalone LED Output
- Reset Button
- Base Board Data Communication over USB
- Each individual Sensor Output

## Checking the Base Board Power Connection via USB and the Standalone LED Output

1. This can be completed by simply powering the base board though any standard USB connector
  a. The included ROHM battery will work for this, but we recommend connecting this to a PC’s USB port in order to save some time since we will want to check data communication to the board as well
2. Pass Condition
  a. When no sensor breakout boards are connected to this board, the board will flash the onboard LEDs repeatedly.

## Checking the Checking the Reset Button

1. Move the Jumper on the J2 connector to connect the bottom two pins (looking at the base board with the sensor interface connector on top). Please note, that connector J2 is a three pin connector (not to be confused with the additional 2 pin connector, J3, below connector J2).
2. Pass Condition (perform either step a or b below)
  a. If looking at the output LEDs, if the PB (S1) is pressed, the LEDs will stop flashing for the duration of the press. When this switch is let go, the LEDs should begin to flash again
  b. If looking at the debug console, if the PB (S1) is pressed, all previous information provided will be cleared and the firmware information should be displayed like the picture below

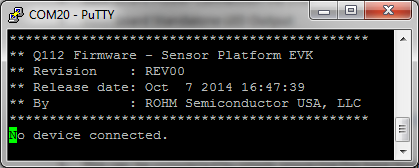
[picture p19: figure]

## Checking Base Board Communication over USB

1. NOTE: if the reset button was checked using the PC debug console, then this section is not necessary
2. Connect the Sensor Platform Base board to the PC
3. Check the PC’s device manager to figure out which COM port this device is connected to

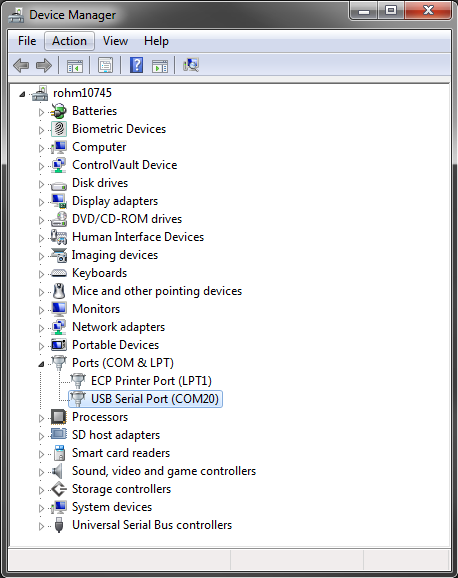
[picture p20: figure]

4. Open Putty (or your preferred COM terminal application). If you choose to use putty, simply check the “Serial” radio button and adjust the “serial line” to COM20 (or whatever COM port the device manager says this device is connected to) and adjust the “speed” field to 9600

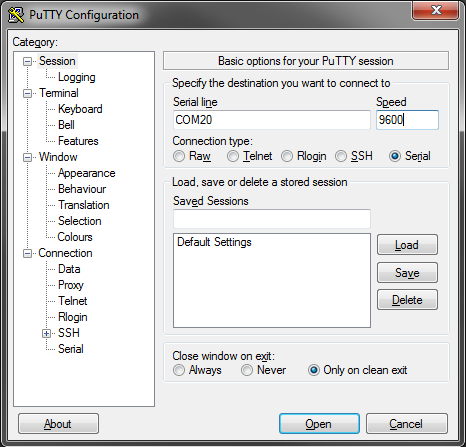
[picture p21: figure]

5. Upon clicking the “Open” Button, the putty configuration screen will disappear and the terminal output will be shown. Click the Reset button to show the firmware details.
6. Pass condition
  a. This stage passes our checks if we successfully see the firmware details when pressing the reset button

## Checking Each Individual Sensor Output

Since this kit includes 6 sensor breakout boards, we will want to test each of the 6 included sensors. For this, we will also want to test both the standalone output (via output LEDs) and the PC output (via COM terminal). Please note, the below will assume the board is connected to a base board.

- Recommended Tools for Testing
  - Flashlight
  - Magnet
  - “Quik-Freeze” canned air
  - UV Flashlight
- ROHM BH1721 – Digital Ambient Light Sensor
  - Passing conditions
    1. Low Light condition – Cover the Sensor
      - Standalone LED’s binary output should be close to 0-1. Essentially, will be lower than ambient and high lighting conditions
    2. Ambient Light condition – use the current level of lighting
      - Standalone LED’s binary output should be higher than the Low light condition, but lower than the high light condition
    3. High Light condition – Shine a Flashlight onto the sensor
      - Standalone LED’s binary output should be higher than ambient light and low light conditions
  - If checking on the PC, the output should follow in the same fashion as the standalone LED’s binary output.
- ROHM BH1620 – Analog Ambient Light Sensor
  - Follow the same check as the BH1721 digital ALS above
- ROHM BU52011HFV – Hall Switch Sensor
  - Passing Conditions
    4. No Mag Field Condition
      - Standalone LED’s binary output should be off (no LEDs ON)
      - The PC Terminal output should also state “Hall – No Mag Fields Detected”
    5. N and S polarity Mag Field condition
      - Standalone LED’s binary output should show binary “1”. (AKA, right most LED will be on)
      - The PC Terminal Output should also state “Hall – Mag Field Detected”
        - Note: This is an Omnipolar Hall Switch IC, thus it will trigger one output when a magnetic field is present. However, this is not a dual output hall sensor, thus it cannot determine the polarity of the magnetic field with this sensor device.
- ROHM BDE0600G – Analog Temperature Sensor
  - Passing Conditions
    6. Room Temperature Condition
      - Standalone LED’s binary output should show a constant value. Also, this value should be higher than the low temp condition and lower than the high temp condition
      - The PC terminal will output the temperature. This should be around the temperature of the room (~25C)
    7. Warm Temperature Condition
      - A warm temperature condition can be seen by placing a finger on the sensor; however this should only increase the sensor output by 1-2 degrees
      - The Standalone LED’s binary output and PC output should show a value higher than the room temperature value. However, since the change is not drastic, this may not be seen; thus, it is best to confirm this on the PC terminal.
    8. Cold Temperature Condition
      - A cold temperature condition can be seen by spraying the sensor with canned air. In our test, we used “Quik-Freeze”, which dramatically changed the sensor output.
      - The Standalone LED’s binary output and PC output should show a value lower than the room temperature value.
- LAPIS ML8511 – Analog UV Sensor
  - Passing Conditions
    9. Nominal Lighting Condition
      - The nominal lighting condition can be used in the normal environment without any changes to lighting
      - This should show a constant value and passes if alternative lighting sources do not change this value
    10. UV lighting condition
      - The UV lighting condition can be induced using a UV LED or UV flashlight
      - The Standalone LED’s binary output and the PC output should show values higher than the nominal condition when the UV light is shined upon the sensor
- Kionix KMX061 – Digital Accelerometer and Magnetometer
  - Passing Conditions - Accel
    11. Using the Standalone LEDs, we can quickly check the operation of the accelerometer portion of the IC. This can be done by tilting the board in the either longward side. The LED output should follow the direction of the tilt.
    12. Also, this can be checked using the PC terminal. When the board is flat, the “AccelZ_scaled” value should be close to 1 while the X and Y components are close to 0.
  - Passing Conditions – Mag
    13. The Mag portion cannot be tested using the standalone LEDs
    14. When looking at the PC terminal output, we can quickly test by placing the magnet over the top of the sensor. This will affect the Z output and should dramatically increase the magnitude of this value. Flipping the magnet will flip the sign.

Firmware Flashing and Initial Hardware Check Guide ROHM-SENSEKIT1-EVK-101-ND 05 October, 2015 – Revision A

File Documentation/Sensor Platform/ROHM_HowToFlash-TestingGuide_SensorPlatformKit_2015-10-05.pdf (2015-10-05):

## Firmware Flashing and Initial Hardware Check Guide for ROHM’s Sensor Platform Kit

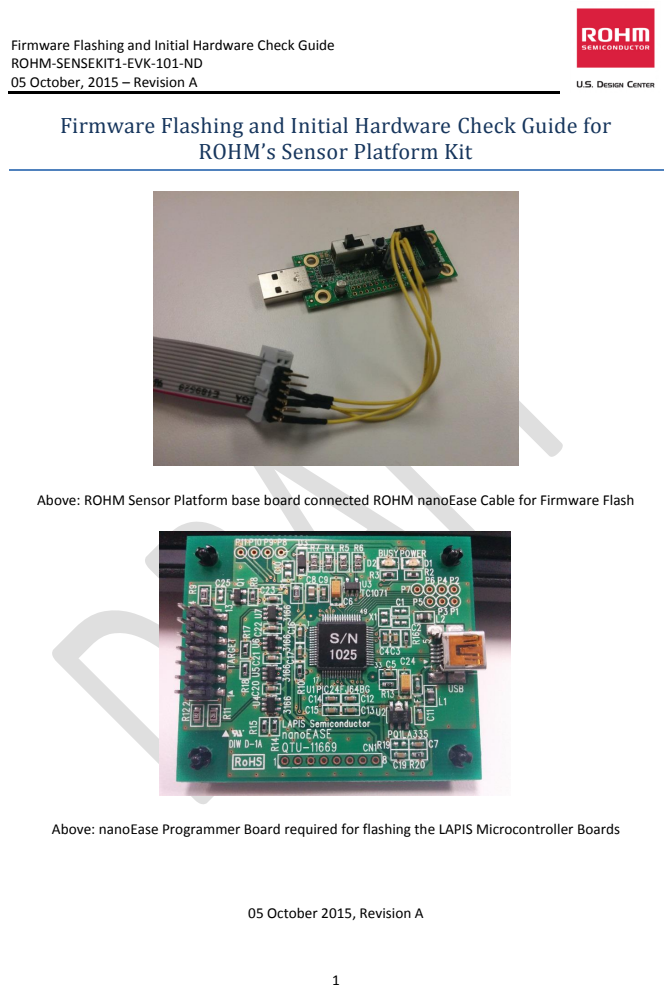
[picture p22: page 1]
05 October 2015, Revision A

Firmware Flashing and Initial Hardware Check Guide
ROHM-SENSEKIT1-EVK-101-ND
05 October, 2015 – Revision A

Above: ROHM Sensor Platform base board connected ROHM nanoEase Cable for Firmware Flash

Above: nanoEase Programmer Board required for flashing the LAPIS Microcontroller Boards

### Table of Contents

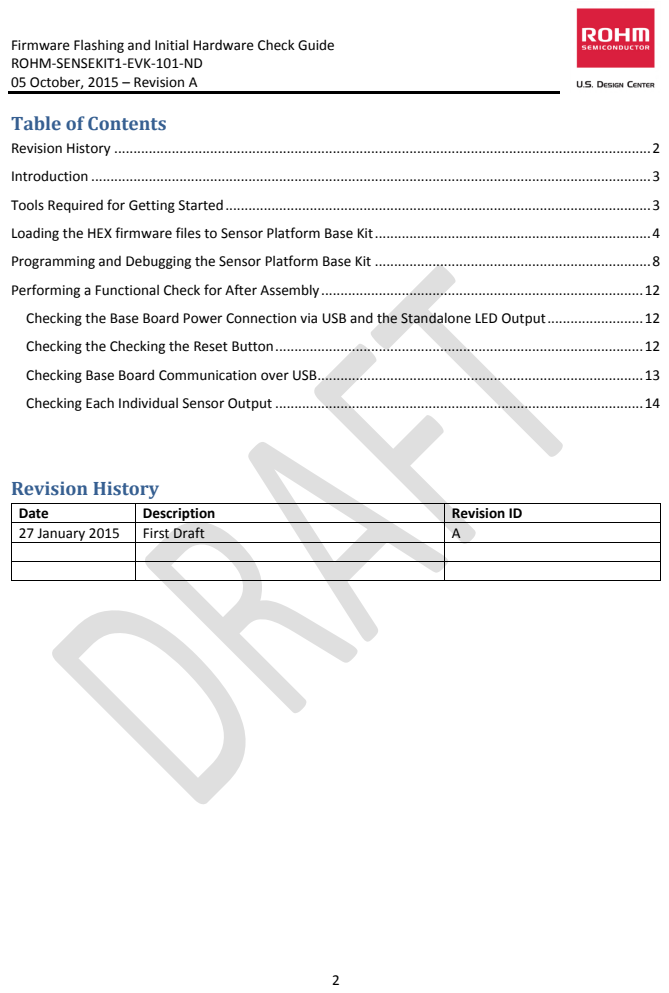
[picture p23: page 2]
Revision History

ROHM-SENSEKIT1-EVK-101-ND
05 October, 2015 – Revision A

Date | Description | Revision ID
27 January 2015 | First Draft | A

ROHM-SENSEKIT1-EVK-101-ND
05 October, 2015 – Revision A

### Introduction

The following document was written to provide an explanation to how to flash the firmware for these sensor platform boards with the most recent firmware. Also, this guide will go into the details of how to check the hardware assemblies of these boards.

For other guides, such as operation manuals and other platform connection tutorials, please visit our public repository at the following link…

ROHM’s Sensor Platform Kit: https://github.com/ROHMUSDC/ROHMSensorPlatformEVK

- ROHM BH1721 – Digital Ambient Light Sensor
- ROHM BH1620 – Analog Ambient Light Sensor
- ROHM BU52011HFV – Hall Switch Sensor
- ROHM BDE0600G – Analog Temperature Sensor
- LAPIS ML8511 – Analog UV Sensor
- Kionix KMX061 – Digital Accelerometer and Magnetometer

### Tools Required for Getting Started

The Base board for the Sensor Platform Kit uses a LAPIS ML610Q112 Microcontroller as the main application processor for this kit. Please note, that this board does not come with any on-board programming chip; therefore, in order to successfully flash this MCU, you will need a “uEase” or “nanoEase” programmer/debugger board. These can be found at the following link:

uEase MCU programmer and Debugger Hardware:

http://www.digikey.com/product-search/en?x=0&y=0&lang=en&site=us&keywords=uEase

Please note that you will also need to register and login to the Lapis Support Site in order to download the software tools required for flashing this device.

LAPIS Support Site Login/Registration Page:

https://www.lapis-semi.com/cgi-bin/MyLAPIS/regi/login.cgi

Once you’ve logged into the support suite, click the “Development Support System” link on the left side of the screen.

After this page has loaded, please download the latest version of the “U8 Development Tools”. This Software package includes the application named “FWuEASE Flash Writer” and “IDEU8 GUI Environment”. Either application can be used to flash the sensor platform base boards. IDEU8 would be used to develop code and program/debug. The FWuEASE flash writer can be used to program HEX files

ROHM-SENSEKIT1-EVK-101-ND
05 October, 2015 – Revision A

direct to the MCU Base board. See the picture below for the software package that should be downloaded after registering for the LAPIS Development Support Site:

### Loading the HEX firmware files to Sensor Platform Base Kit

This section should be referred to if the user only wants to load an already generated HEX file into the existing base board. If the user wants to adjust source code and test/debug their code, please skip forward to the section entitled, “Programming and Debugging the Sensor Platform Base Kit”.

1. Acquire a “uEase” or “nanoEase” programmer/debugger board and install the FWuEASE Flash Writer as explained in the previous section.
2. Connect the “uEase” or “nanoEase” programmer/debugger board to the sensor platform base board
a. On the Sensor Platform Base board, we will want to connect to pin header J4 (2x2 header pin row)

i.

ROHM-SENSEKIT1-EVK-101-ND
05 October, 2015 – Revision A
b. On the uEase of nanoEase programmer boards, we will want to isolate 4 pins (VDD, GND, TST, and RST). Then, we recommend building a jumper cable to make the connection easier to re-connect. See below for schematics for this debug port and an example debug port connector we used to flash these boards

i.

ii.
3. Move the Jumper on the J2 connector to connect the top two pins (looking at the base board with the sensor interface connector on top).
a. This will change the connection of the reset pin on the board from the PB (S1) to the programmer.
4. Connect the uEase/nanoEase board to the PC using a mini USB cable.
5. Download the latest HEX programming file for the latest revision firmware
a. This can be found at the GitHub repository page at the following link
i. https://github.com/ROHMUSDC/ROHMSensorPlatformEVK
b. Please note that this can be found in the following folder hierarchy
i. …ROHMSensorPlatformEVK/Firmware - Base Board ML610Q112 Code/_output/_hex
c. Name of the file should be as follows
i. “Q112-SENSORPLATFORMEVK.HEX”
d. Be sure to save this file somewhere where you can find it later as it will be the main file used to program these boards.
6. Next, open the newly installed “FWuEASE” software. When opening this application for the first time, an error message may occur that asks you to choose a target device. Choose “ML610112” then click OK

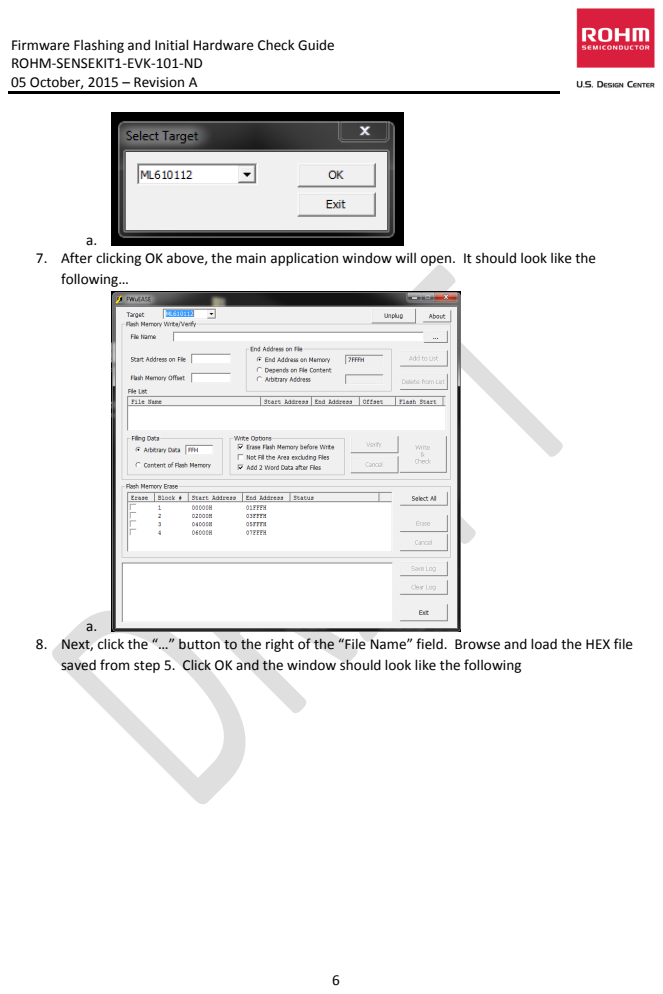
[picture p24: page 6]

ROHM-SENSEKIT1-EVK-101-ND
05 October, 2015 – Revision A

7. After clicking OK above, the main application window will open. It should look like the
following…

8. Next, click the “…” button to the right of the “File Name” field. Browse and load the HEX file
saved from step 5. Click OK and the window should look like the following

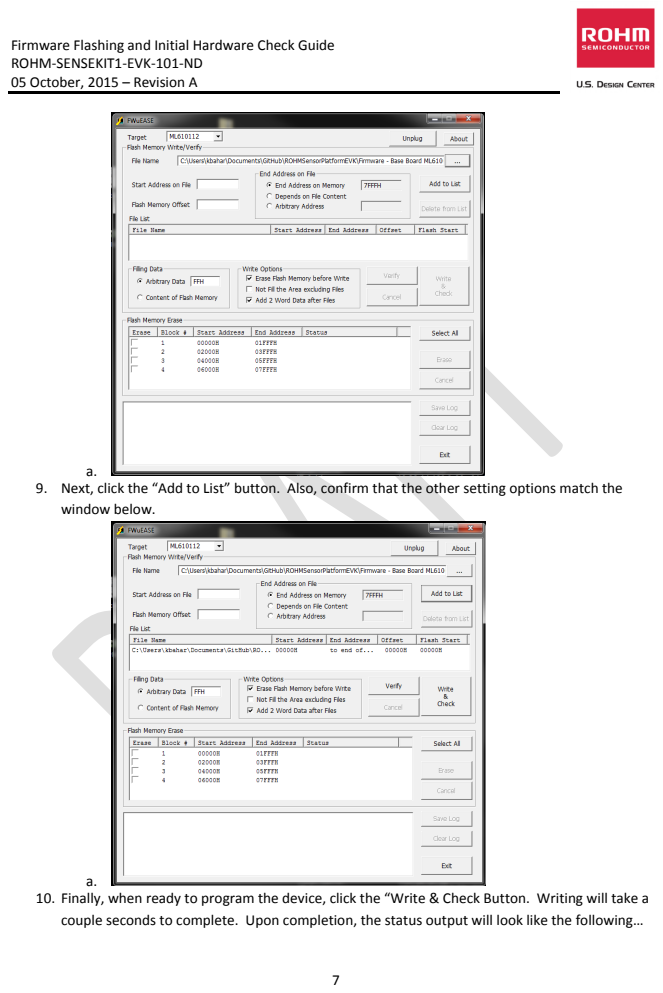
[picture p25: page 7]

ROHM-SENSEKIT1-EVK-101-ND
05 October, 2015 – Revision A

9. Next, click the “Add to List” button. Also, confirm that the other setting options match the
window below.

10. Finally, when ready to program the device, click the “Write & Check Button. Writing will take a
couple seconds to complete. Upon completion, the status output will look like the following…

ROHM-SENSEKIT1-EVK-101-ND
05 October, 2015 – Revision A

a.
11. If you see the above message, then you have successfully flashed the hardware of this device!

### Programming and Debugging the Sensor Platform Base Kit

1. Acquire a “uEase” or “nanoEase” programmer/debugger board and install the IDEU8 GUI Development Environment as explained in the “Tools Required for Getting Started” section above.
2. Connect the “uEase” or “nanoEase” programmer/debugger board to the sensor platform base board
a. On the Sensor Platform Base board, we will want to connect to pin header J4 (2x2 header pin row)

i.

ROHM-SENSEKIT1-EVK-101-ND
05 October, 2015 – Revision A
b. On the uEase of nanoEase programmer boards, we will want to isolate 4 pins (VDD, GND, TST, and RST). Then, we recommend building a jumper cable to make the connection easier to re-connect. See below for schematics for this debug port and an example debug port connector we used to flash these boards

i.

ii.
3. Move the Jumper on the J2 connector to connect the top two pins (looking at the base board with the sensor interface connector on top).
a. This will change the connection of the reset pin on the board from the PB (S1) to the programmer.
4. Connect the uEase/nanoEase board to the PC using a mini USB cable.
5. Next, open the newly installed IDEU8 GUI Development Environment and open up your target MCU’s source code
a. If you’re just getting started you can view and download the base revision of the code by downloading the firmware example from the following repository page:
i. https://github.com/ROHMUSDC/ROHMSensorPlatformEVK
ii. …/ROHMSensorPlatformEVK/Firmware - Base Board ML610Q112 Code
6. Next, adjust the code as required for your application and then confirm that the application complies properly by using the “Rebuild” button

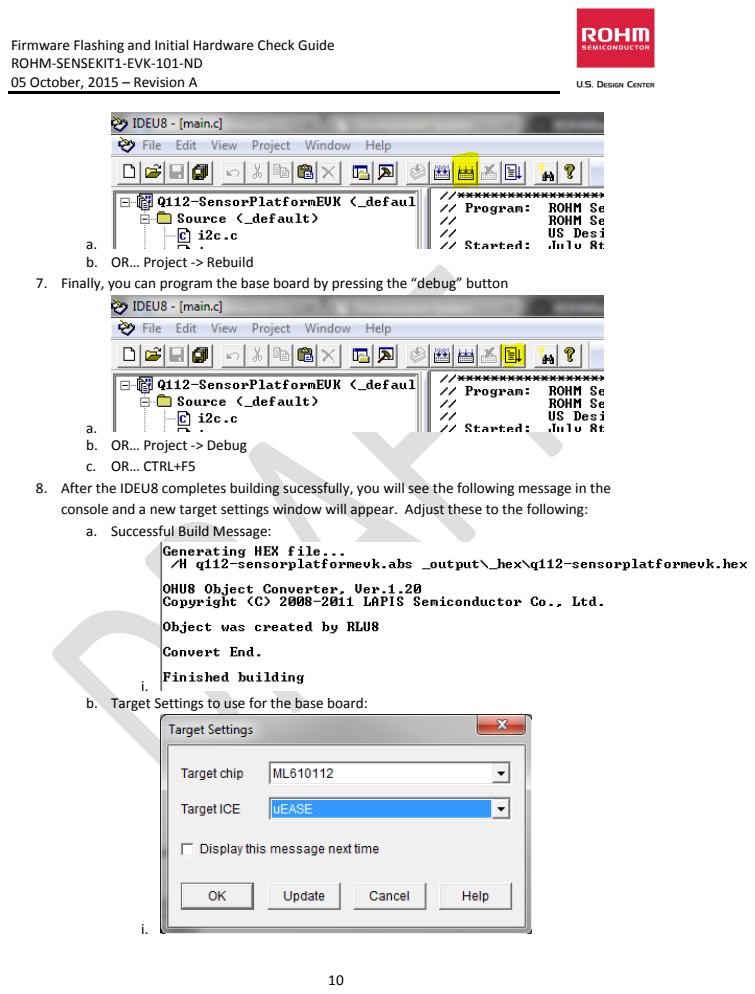
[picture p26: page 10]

ROHM-SENSEKIT1-EVK-101-ND
05 October, 2015 – Revision A

b. OR… Project -> Rebuild

7. Finally, you can program the base board by pressing the “debug” button

b. OR… Project -> Debug
c. OR… CTRL+F5

8. After the IDEU8 completes building sucessfully, you will see the following message in the
console and a new target settings window will appear. Adjust these to the following:
a. Successful Build Message:

b. Target Settings to use for the base board:

ROHM-SENSEKIT1-EVK-101-ND
05 October, 2015 – Revision A

ii. Note: uEASE can be chosen if a uEASE programmer is being used. However, nanoEase should be chosen if a nanoEASE programmer is being used.
9. After setting the target settings, the DTU8 debugger will be open with the code used to program the base board with.
a. Run the code using the “F5” key
b. Additional run commands can be found in the “Run” menu (Pause, stop, step in, step

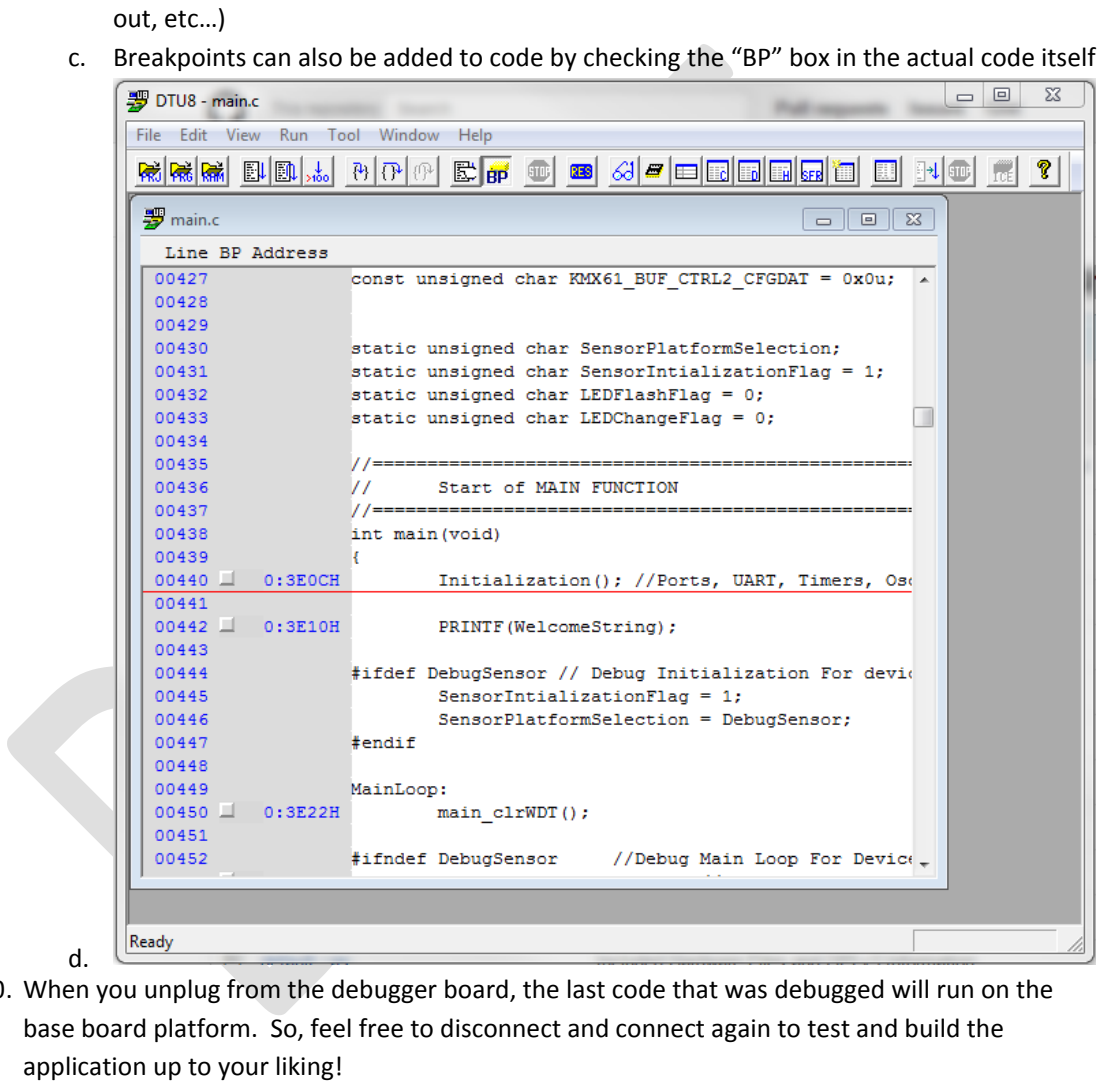
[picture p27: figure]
out, etc…); application up to your liking!

c. Breakpoints can also be added to code by checking the “BP” box in the actual code itself
10. When you unplug from the debugger board, the last code that was debugged will run on the base board platform. So, feel free to disconnect and connect again to test and build the

ROHM-SENSEKIT1-EVK-101-ND
05 October, 2015 – Revision A

### Performing a Functional Check for After Assembly

When performing a functional check of the sensor platform kit boards, we will want to check each of the following aspects of the board

- Base Board Power Connection via USB
- Base Board Standalone LED Output
- Reset Button
- Base Board Data Communication over USB
- Each individual Sensor Output

### Checking the Base Board Power Connection via USB and the Standalone LED Output

1. This can be completed by simply powering the base board though any standard USB connector
a. The included ROHM battery will work for this, but we recommend connecting this to a PC’s USB port in order to save some time since we will want to check data communication to the board as well
2. Pass Condition
a. When no sensor breakout boards are connected to this board, the board will flash the onboard LEDs repeatedly.

### Checking the Checking the Reset Button

1. Move the Jumper on the J2 connector to connect the bottom two pins (looking at the base board with the sensor interface connector on top). Please note, that connector J2 is a three pin connector (not to be confused with the additional 2 pin connector, J3, below connector J2).
2. Pass Condition (perform either step a or b below)
a. If looking at the output LEDs, if the PB (S1) is pressed, the LEDs will stop flashing for the duration of the press. When this switch is let go, the LEDs should begin to flash again
b. If looking at the debug console, if the PB (S1) is pressed, all previous information provided will be cleared and the firmware information should be displayed like the picture below

i.

ROHM-SENSEKIT1-EVK-101-ND
05 October, 2015 – Revision A

### Checking Base Board Communication over USB

1. NOTE: if the reset button was checked using the PC debug console, then this section is not necessary
2. Connect the Sensor Platform Base board to the PC
3. Check the PC’s device manager to figure out which COM port this device is connected to

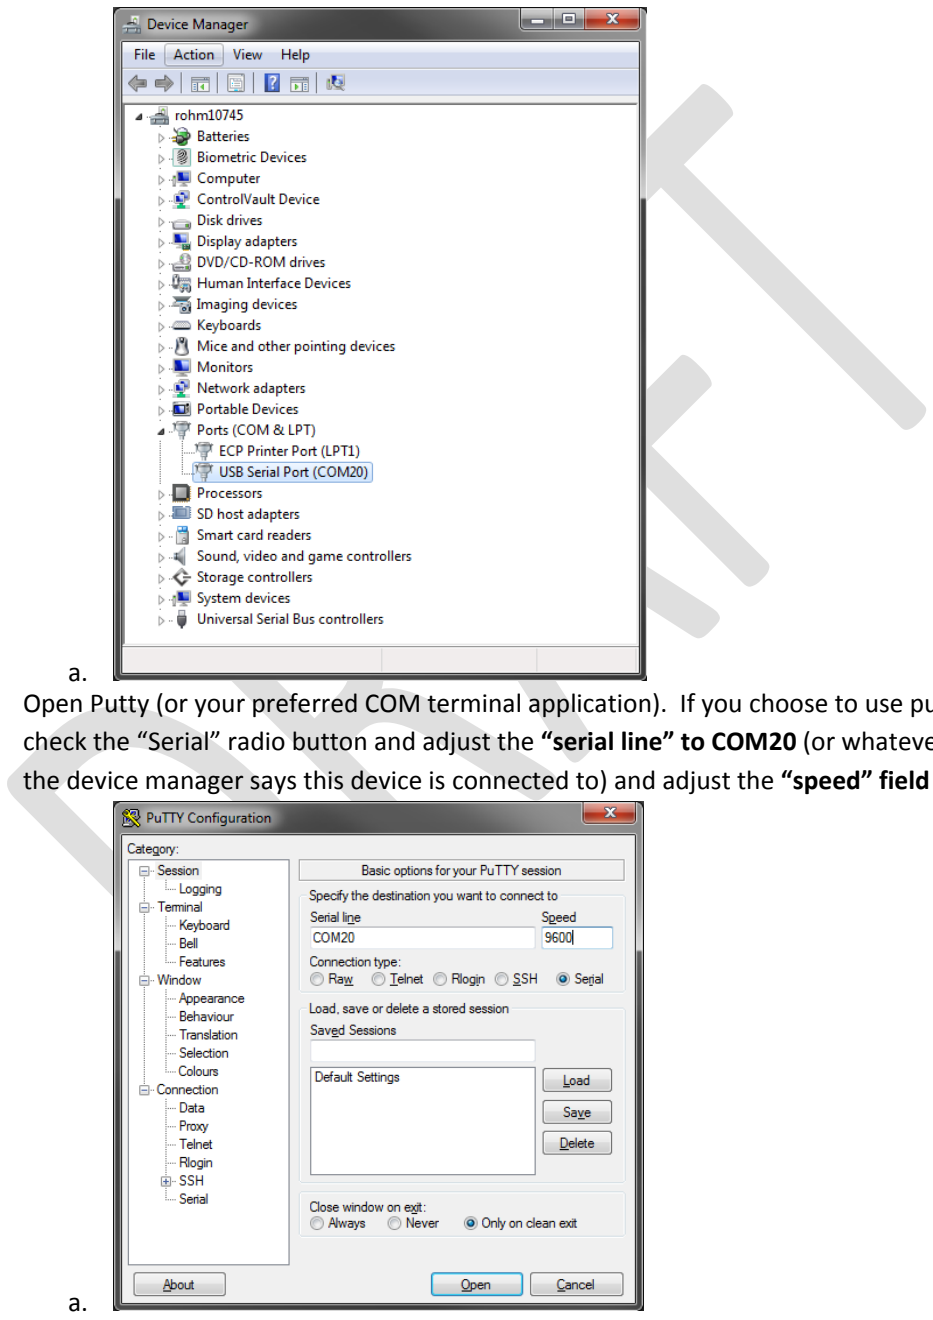
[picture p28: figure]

4. Open Putty (or your preferred COM terminal application). If you choose to use putty, simply check the “Serial” radio button and adjust the “serial line” to COM20 (or whatever COM port the device manager says this device is connected to) and adjust the “speed” field to 9600

ROHM-SENSEKIT1-EVK-101-ND
05 October, 2015 – Revision A
5. Upon clicking the “Open” Button, the putty configuration screen will disappear and the terminal output will be shown. Click the Reset button to show the firmware details.
6. Pass condition
a. This stage passes our checks if we successfully see the firmware details when pressing the reset button

i.

### Checking Each Individual Sensor Output

Since this kit includes 6 sensor breakout boards, we will want to test each of the 6 included sensors. For this, we will also want to test both the standalone output (via output LEDs) and the PC output (via COM terminal). Please note, the below will assume the board is connected to a base board.

- Recommended Tools for Testing
- Flashlight
- Magnet
- “Quik-Freeze” canned air
- UV Flashlight
- ROHM BH1721 – Digital Ambient Light Sensor
- Passing conditions
1. Low Light condition – Cover the Sensor
- Standalone LED’s binary output should be close to 0-1. Essentially, will be lower than ambient and high lighting conditions
2. Ambient Light condition – use the current level of lighting
- Standalone LED’s binary output should be higher than the Low light condition, but lower than the high light condition
3. High Light condition – Shine a Flashlight onto the sensor
- Standalone LED’s binary output should be higher than ambient light and low light conditions
- If checking on the PC, the output should follow in the same fashion as the standalone LED’s binary output.
- ROHM BH1620 – Analog Ambient Light Sensor
- Follow the same check as the BH1721 digital ALS above

ROHM-SENSEKIT1-EVK-101-ND
05 October, 2015 – Revision A
- ROHM BU52011HFV – Hall Switch Sensor
- Passing Conditions
1. No Mag Field Condition
- Standalone LED’s binary output should be off (no LEDs ON)
- The PC Terminal output should also state “Hall – No Mag Fields Detected”
2. N and S polarity Mag Field condition
- Standalone LED’s binary output should show binary “1”. (AKA, right most LED will be on)
- The PC Terminal Output should also state “Hall – Mag Field Detected”
- Note: This is an Omnipolar Hall Switch IC, thus it will trigger one output when a magnetic field is present. However, this is not a dual output hall sensor, thus it cannot determine the polarity of the magnetic field with this sensor device.
- ROHM BDE0600G – Analog Temperature Sensor
- Passing Conditions
1. Room Temperature Condition
- Standalone LED’s binary output should show a constant value. Also, this value should be higher than the low temp condition and lower than the high temp condition
- The PC terminal will output the temperature. This should be around the temperature of the room (~25C)
2. Warm Temperature Condition
- A warm temperature condition can be seen by placing a finger on the sensor; however this should only increase the sensor output by 1-2 degrees
- The Standalone LED’s binary output and PC output should show a value higher than the room temperature value. However, since the change is not drastic, this may not be seen; thus, it is best to confirm this on the PC terminal.
3. Cold Temperature Condition
- A cold temperature condition can be seen by spraying the sensor with canned air. In our test, we used “Quik-Freeze”, which dramatically changed the sensor output.
- The Standalone LED’s binary output and PC output should show a value lower than the room temperature value.
- LAPIS ML8511 – Analog UV Sensor
- Passing Conditions
1. Nominal Lighting Condition

ROHM-SENSEKIT1-EVK-101-ND
05 October, 2015 – Revision A
- The nominal lighting condition can be used in the normal environment without any changes to lighting
- This should show a constant value and passes if alternative lighting sources do not change this value
2. UV lighting condition
- The UV lighting condition can be induced using a UV LED or UV flashlight
- The Standalone LED’s binary output and the PC output should show values higher than the nominal condition when the UV light is shined upon the sensor
- Kionix KMX061 – Digital Accelerometer and Magnetometer
- Passing Conditions - Accel
1. Using the Standalone LEDs, we can quickly check the operation of the accelerometer portion of the IC. This can be done by tilting the board in the either longward side. The LED output should follow the direction of the tilt.
2. Also, this can be checked using the PC terminal. When the board is flat, the “AccelZ_scaled” value should be close to 1 while the X and Y components are close to 0.
- Passing Conditions – Mag
1. The Mag portion cannot be tested using the standalone LEDs
2. When looking at the PC terminal output, we can quickly test by placing the magnet over the top of the sensor. This will affect the Z output and should dramatically increase the magnitude of this value. Flipping the magnet will flip the sign.

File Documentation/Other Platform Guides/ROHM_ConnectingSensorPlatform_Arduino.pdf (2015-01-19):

Connecting ROHM’s Sensor Platform Kit to the Arduino Uno ROHM-SENSEKIT1-EVK-101-ND
15 January, 2015 – Revision A

## Connecting the Sensor Platform Kit to the Arduino UNO Platform

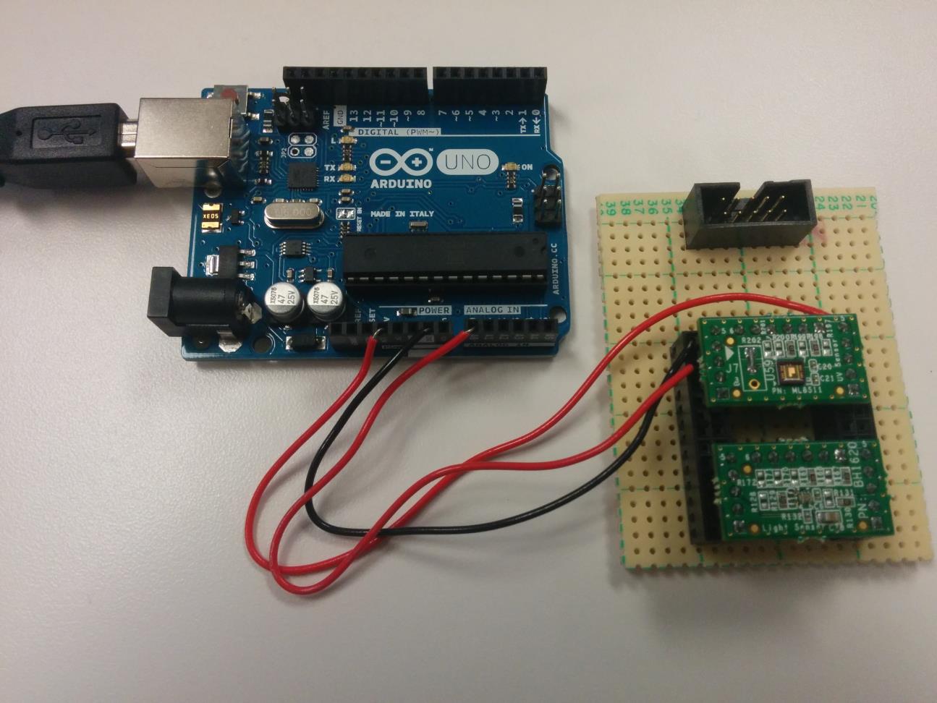
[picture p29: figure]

Above: ROHM Sensor Platform breakout boards connected to the Arduino Uno

15 January 2015, Revision A

ROHM-SENSEKIT1-EVK-101-ND
15 January, 2015 – Revision A

### Table of Contents

ROHM-SENSEKIT1-EVK-101-ND
15 January, 2015 – Revision A

### Copyright and License

The following except is copied directly from the Arduino FAQ (http://arduino.cc/en/Main/FAQ)

“What do you mean by open-source hardware?” - Open-source hardware shares much of the principles and approach of free and open-source software. In particular, we believe that people should be able to study our hardware to understand how it works, make changes to it, and share those changes. To facilitate this, we release all of the original design files (Eagle CAD) for the Arduino hardware. These files are licensed under a Creative Commons Attribution Share-Alike license, which allows for both personal and commercial derivative works, as long as they credit Arduino and release their designs under the same license.

The Arduino software is also open-source. The source code for the Java environment is released under the GPL and the C/C++ microcontroller libraries are under the LGPL.

Please note that all references to ROHM’s Sensor Platform Kit are also shared under open source guidelines under the GNU General Public License, Version 3. Details can be found at the following link: https://github.com/ROHMUSDC/ROHMSensorPlatformEVK.

### Revision History

Date | Description | Revision ID
12 January 2015 | First Draft | A

ROHM-SENSEKIT1-EVK-101-ND
15 January, 2015 – Revision A

### Introduction

The following document was written to provide a brief connection guide and starting point for using ROHM’s Sensor Platform Kit with the Arduino Uno. This guide assumes that the user has basic functional knowledge of both the Sensor Platform Kit and the Arduino itself. If this is not correct, please see the following links for other guides and information on these products.

ROHM’s Sensor Platform Kit: https://github.com/ROHMUSDC/ROHMSensorPlatformEVK

Arduino: http://arduino.cc/

Please note that the Arduino platform is a microcontroller platform; thus, this document will explain and show examples of how to connect to and convert values for the ROHM Sensor Kit Sensors. This includes the following:

- ROHM BH1721 – Digital Ambient Light Sensor
- ROHM BH1620 – Analog Ambient Light Sensor
- ROHM BU52011HFV – Hall Switch Sensor
- ROHM BDE0600G – Analog Temperature Sensor
- LAPIS ML8511 – Analog UV Sensor
- Kionix KMX061 – Digital Accelerometer and Magnetometer

### Getting Started

1. Initial Setup
a. ROHM Sensor Platform Kit
i. For this guide, we will be referring to the breakout boards included with the ROHM Sensor Platform Kit. Thus, the base board will not be used in this setup
b. The following are recommended for using the Arduino Uno for this guide
i. PC with Arduino IDE
ii. USB Cable to power and monitor serial communication
iii. Download the example file “ROHM_SensorKitBreakoutBoardConnect_1-13-2015.ino” from https://github.com/ROHMUSDC/ROHMSensorPlatformEVK. This document will refer to this code to help explain how to connect and properly calculate sensor data.

ROHM-SENSEKIT1-EVK-101-ND
15 January, 2015 – Revision A

### Connecting ROHM Breakout Boards to the Arduino UNO

### General Information

- ROHM’s Sensor Platform Breakout Boards have the same pinout across all the different sensors. If you are looking at the board from the top, the breakout board pinout will be as follows:

o

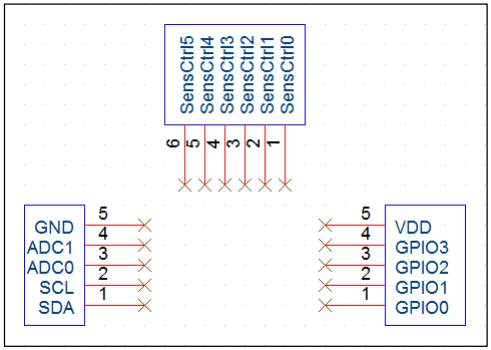
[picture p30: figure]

- The top row of pins is in place to “key” the sensor onto the base boards; however, they do not have any use when connecting to different platforms. We recommend mounting the breakout board on standoffs to avoid connections to these pins

o

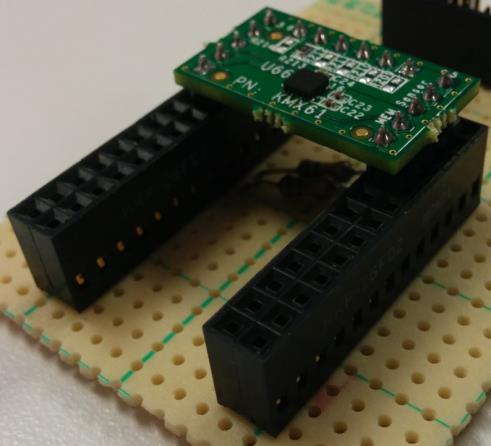
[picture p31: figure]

- Please note that breakout board schematics can also be found at the following site:
- https://github.com/ROHMUSDC/ROHMSensorPlatformEVK

ROHM-SENSEKIT1-EVK-101-ND
15 January, 2015 – Revision A

### Hardware Connection for ROHM BH1721 Digital ALS to the Arduino Uno

- ROHM BH1721 – Digital Ambient Light Sensor Breakout Board Schematic

o

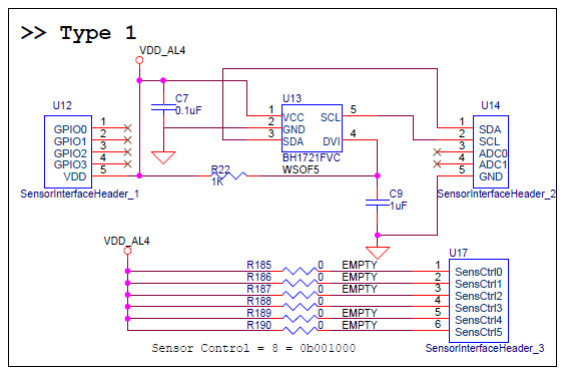
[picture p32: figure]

- As seen in the schematic above, this device connects 4 pins.
- VDD – Connect directly to Arduino 3.3V output pin on power connector
- GND – Connect directly to Arduino GND pin on the power connector
- I2C Connection
- Note: User can specify the I2C pins, but in the example application, I2C is connected as follows…
- SDA – Pin A4
- SCL – Pin A5
- Note: There are no pull-up resistors on the breakout board or the Arduino Uno. Thus, please be sure to add pull-up resistance to both SDA and SCL pins. 10kohm resistors were used when writing this example code

### Software Explanation for ROHM BH1721 Digital ALS to the Arduino Uno

- Code Segments pertaining to this sensor can be found by defining and seeing code within the “DigitalALS” #ifDef statements
- Pseudo-Code Explanation
1. Define Relevant Variables
2. Begin setup()
1. Initialize the I2C output
- Note: this sensor uses the “wire” library built into Arduino to read and write send the I2C commands (http://arduino.cc/en/reference/wire)
2. Configure the Digital ALS once
- Send the Power ON Byte (0x01) to ALS device address (0x23)

ROHM-SENSEKIT1-EVK-101-ND
15 January, 2015 – Revision A
- Send Continuous Auto-Resolution Mode Setting (0x10) to ALS device address (0x23)
3. Begin loop()
1. Read 2 Bytes from Sensor, [0][1]
2. Format the two bytes into an INT
- Sensor Out = [0]<<8 | [1]
3. Convert to Lux = Sensor Out / 1.2
4. Format Serial Output and Return information

### Hardware Connection for ROHM BH1620 Analog ALS to the Arduino Uno

- ROHM BH1620 – Analog Ambient Light Sensor Breakout Board Schematic

o

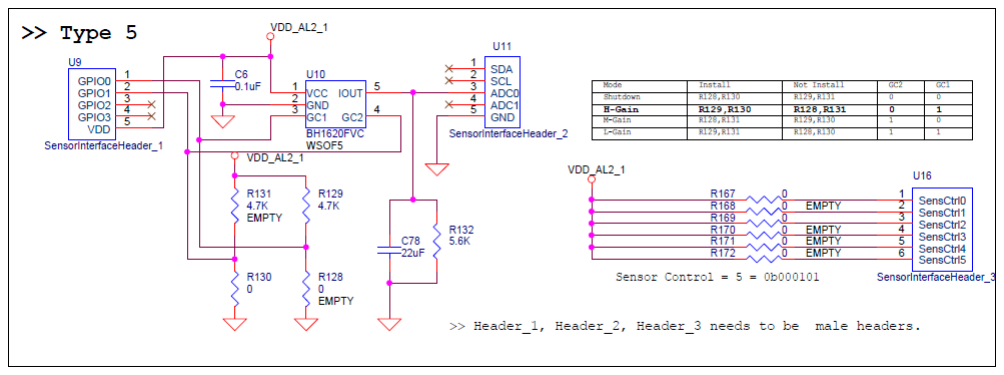
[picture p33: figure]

- As seen in the schematic above, this device connects 5 pins.
- VDD – Connect directly to Arduino 3.3V output pin on power connector
- GND – Connect directly to Arduino GND pin on the power connector
- ADC0 – ADC Output for Temperature Readings
- Note: User can specify which ADC pin, but in the example application, this part is connected as follows…
- ADC0 – Pin A0
- GPIO0, GPIO1
- These pins are used to program the different mode gain options. These pins are not used in the example application.

### Software Explanation for ROHM BH1620 Analog ALS to the Arduino Uno

- Code Segments pertaining to this sensor can be found by defining and seeing code within the “AnalogALS” #ifDef statements
- Pseudo-Code Explanation
1. Define Relevant Variables
2. Begin loop()
1. Read back the Analog Sensor Output from Pin A0

ROHM-SENSEKIT1-EVK-101-ND
15 January, 2015 – Revision A
- Note: Default Arduino Reference voltage is 5V; however we are supplying 3.3V to the sensor. Take these values into account when performing your conversions!
2. Convert Analog Sensor Output to V, then to Lx
- Convert to V
- ADC_Voltage = (sensorValue / 670) * 3.3V
- ADC_Voltage = sensorValue * (3.3V/670)
- ADC_Voltage = sensorValue * 0.004925
- Convert to Ev
- Ev = ADC_Voltage/((0.57x10^-6)*R1), R1 = 5600
- Ev = ADC_Voltage*(1/(0.57x10^-6*5600))
- Ev = ADC_Voltage * 313.28
- Ev = sensorValue * 0.004925 * 313.28
- Ev = sensorValue * 1.543
3. Format Serial Output and Return information

### Hardware Connection for ROHM BU52011 Hall Sensor to the Arduino Uno

- ROHM BU52011HFV – Hall Switch Sensor

o

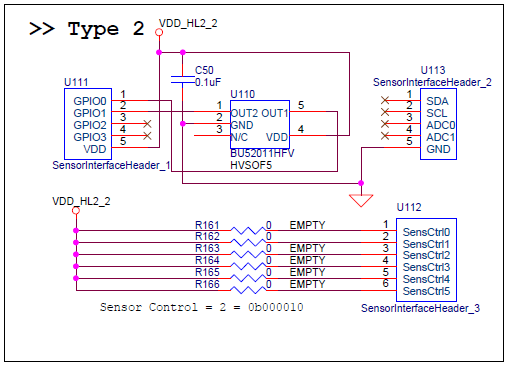
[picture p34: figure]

- As seen in the schematic above, this device connects 4 pins.
- VDD – Connect directly to Arduino 3.3V output pin on power connector
- GND – Connect directly to Arduino GND pin on the power connector

ROHM-SENSEKIT1-EVK-101-ND
15 January, 2015 – Revision A
- GPIO0, GPIO1 – Indicate Hall Switch Output
- Note: User can specify which digital input pins are used, but in the example application, this part is connected as follows…
- GPIO0 – pin 7 (on the Arduino digital header)
- GPIO1 – pin 8 (on the Arduino digital header)

### Software Explanation for ROHM BU52011 Hall Sensor to the Arduino Uno

- Code Segments pertaining to this sensor can be found by defining and seeing code within the “HallSen” #ifDef statements
- Pseudo-Code Explanation
1. Define Relevant Variables
2. Begin setup()
1. Setup Arduino Pins 7 and 8 and Input pins
3. Begin loop()
1. Perform digital reads on pins 7 and 8
- Output will be either 1 or 0 and will indicate presence of north or south magnetic fields
2. Format Serial Output and Return Information

### Hardware Connection for ROHM BDE0600G Temp Sensor to the Arduino Uno

- ROHM BDE0600G – Analog Temperature Sensor

o

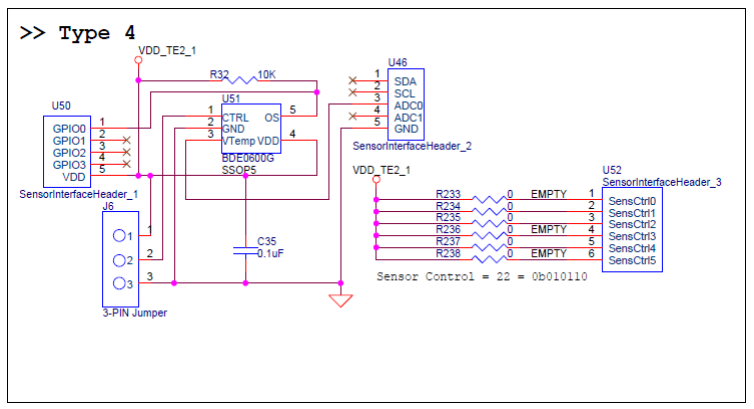
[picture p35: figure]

- As seen in the schematic above, this device connects 4 pins.
- VDD – Connect directly to Arduino 3.3V output pin on power connector
- GND – Connect directly to Arduino GND pin on the power connector
- ADC0 – ADC Output for Temperature Readings

ROHM-SENSEKIT1-EVK-101-ND
15 January, 2015 – Revision A
- Note: User can specify which ADC pin, but in the example application, this part is connected as follows…
- ADC0 – Pin A1
- GPIO0
- This pin is used to trigger the thermostat output function. This pin is not used in the example application.

### Software Explanation for ROHM BDE0600G Temp Sensor to the Arduino Uno

- Code Segments pertaining to this sensor can be found by defining and seeing code within the “AnalogTemp” #ifDef statements
- Pseudo-Code Explanation
1. Define Relevant Variables
2. Begin Loop()
1. Read back the Analog Sensor Output from Pin A1
- Note: Default Arduino Reference voltage is 5V; however we are supplying 3.3V to the sensor. Take these values into account when performing your conversions!
2. Convert value to V, then to Temperature reading
- Known Values
- Temperature Sensitivity = -10.68mV/degC
- Temperature Sensitivity = -0.01068V/degC
- Temp Known Point = 1.753V @ 30 degC
- Calculation
- ADC_Voltage = (sensorValue / 670) * 3.3V
- ADC_Voltage = sensorValue * (3.3V/670)
- ADC_Voltage = sensorValue * 0.004925
- Temperature (in deg C) = (ADC_Voltage - 1.753)/(-0.01068) + 30
3. Format Serial Output and Return Information

ROHM-SENSEKIT1-EVK-101-ND
15 January, 2015 – Revision A

### Hardware Connection for LAPIS ML8511 UV Sensor to the Arduino Uno

- LAPIS ML8511 – Analog UV Sensor

o

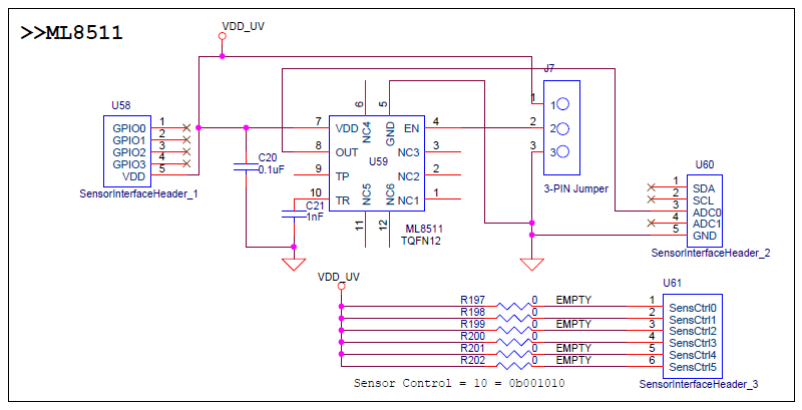
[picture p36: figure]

- As seen in the schematic above, this device connects 3 pins.
- VDD – Connect directly to Arduino 3.3V output pin on power connector
- GND – Connect directly to Arduino GND pin on the power connector
- ADC0 – ADC Output for UV Sensor Output
- Note: User can specify which ADC pin, but in the example application, this part is connected as follows…
- ADC0 – Pin A2
- GPIO0
- This pin is used to trigger standby mode for the UV sensor. This pin is not used in the example application.

### Software Explanation for LAPIS ML8511 UV Sensor to the Arduino Uno

- Code Segments pertaining to this sensor can be found by defining and seeing code within the “AnalogUV” #ifDef statements
- Pseudo-Code Explanation
1. Define Relevant Variables
2. Begin Loop()
1. Read back the Analog Sensor Output from Pin A2
- Note: Default Arduino Reference voltage is 5V; however we are supplying 3.3V to the sensor. Take these values into account when performing your conversions!
2. Convert value to V, then to UV Intensity
- Known Values

ROHM-SENSEKIT1-EVK-101-ND
15 January, 2015 – Revision A
- UV Sensitivity = 0.129 V/(mW/cm²
)
- Temp Known Point = 2.2V @ 10mW/cm²
- Calculation
- ADC_Voltage = (sensorValue / 670) * 3.3V
- ADC_Voltage = sensorValue * (3.3V/670)
- ADC_Voltage = sensorValue * 0.004925
- UV Intensity (in mW/cm²
)= (ADC_Voltage - 2.2)/(0.129) + 10
3. Format Serial Output and Return Information

### Hardware Connection for Kionix KMX061 Accel+Mag Sensor to the Arduino Uno

- Kionix KMX061 – Digital Accelerometer and Magnetometer

o

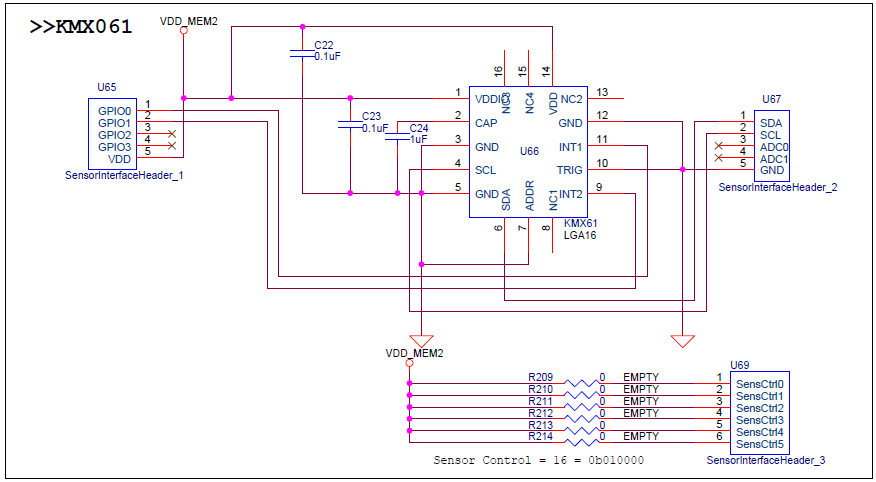
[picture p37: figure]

- As seen in the schematic above, this device connects 6 pins.
- VDD – Connect directly to Arduino 3.3V output pin on power connector
- GND – Connect directly to Arduino GND pin on the power connector
- I2C Connection
- Note: User can specify the I2C pins, but in the example application, I2C is connected as follows…
- SDA – Pin 4 (on Arduino Digital Header)
- SCL – Pin 5 (on Arduino Digital Header)
- Note: There are no pull-up resistors on the breakout board or the Arduino Uno. Thus, please be sure to add pull-up resistance to both SDA and SCL pins. 10kohm resistors were used when writing this example code
- GPIO0/GPIO1

ROHM-SENSEKIT1-EVK-101-ND
15 January, 2015 – Revision A
- This pin is used monitor the interrupt pins on the KMX61. These pins are not used in the example application.

### Software Explanation for Kionix KMX061 Accel+Mag Sensor to the Arduino Uno

- Code Segments pertaining to this sensor can be found by defining and seeing code within the “DigitalMEMs” #ifDef statements
- Pseudo-Code Explanation
1. Define Relevant Variables
2. Begin setup()
1. Initialize the I2C output
- Note: this sensor uses the “SoftI2CMaster” library to read and write send the I2C commands (http://arduino.cc/en/reference/wire). This was required because the “wire” library does not support the “repeated start” condition which is required for I2C reads from the KMX061
- This Library is not built into the Arduino IDE. Resources for this can be found at the following address:
- http://playground.arduino.cc/Main/SoftwareI2CLibrary
- https://github.com/felias-fogg/SoftI2CMaster
2. Configure the Accel/Mag Sensor once by performing the following reads
- 1. Standby Register (0x29), write 0x03 (Turn Off)
- 2. Self Test Register (0x60), write 0x00
- 3. Control Register 1 (0x2A), write 0x13
- 4. Control Register 2 (0x2B), write 0x00
- 5. ODCNTL Register (0x2C), write 0x00
- 6. Temp EN Register (0x4C), write 0x01
- 7. Buffer CTRL Register 1 (0x78), write 0x00
- 8. Buffer CTRL Register 2 (0x79), write 0x00
- 9. Standby Register (0x29), write 0x0u
- Note: Please see the KMX061 Datasheet for additional information on these registers
3. Begin loop()
1. Read back the Accelerometer output by reading 6 Bytes starting from address 0x0A. [0][1]...[5]
2. Format Each of the X, Y, and Z axis acceleration
- Xout = ([1]<<6) | ([0]>>2)
- Yout = ([3]<<6) | ([2]>>2)
- Zout = ([5]<<6) | ([4]>>2)

ROHM-SENSEKIT1-EVK-101-ND
15 January, 2015 – Revision A
- Note: to save some time with conversions, please note that these outputs are meant to be unsigned 14bit values. Thus, to make it easier to convert we recommend the following…
- Xout = (float)(([1]<<8) | ([0]))/4
- Yout = (float)(([3]<<8) | ([2]))/4
- Zout = (float)(([5]<<8) | ([4]]))/4
3. Convert Returned Value to G
- Axis_ValueInG = MEMS_Accel_axis / 1024
4. Read back the Mag Sensor output by reading 6 Bytes starting from address 0x12. [0][1]...[5]
5. Format Each of the X, Y, and Z axis mag data
- Xout = ([1]<<6) | ([0]>>2)
- Yout = ([3]<<6) | ([2]>>2)
- Zout = ([5]<<6) | ([4]>>2)
- Note: to save some time with conversions, please note that these outputs are meant to be unsigned 14bit values. Thus, to make it easier to convert we recommend the following…
- Xout = (float)(([1]<<8) | ([0]))/4
- Yout = (float)(([3]<<8) | ([2]))/4
- Zout = (float)(([5]<<8) | ([4]]))/4
6. Convert Returned Value to uT
- Axis_ValueInuT = MEMS_Mag_axis / 0.146
7. Format Serial Output and Return Information

### //Appendix A: Arduino Code

/*---------------------------------------------------------------

### ROHM Sensor Platform Breakout Board Sensor Return Application

### This program reads the value of the connected ROHM Sensors and returns the sensor output using the serial port

### Created 13 January 2015 by ROHM USDC Applications Engineering Team

### // ----- Debugging Definitions -----#define AnalogALS #define AnalogTemp #define AnalogUV #define HallSen #define DigitalALS #define DigitalMEMs

### // ----- Included Files -----

#include <Wire.h> | //Default I2C Library

#define | SCL_PIN | 4 //Note that if you are using the Accel/Ma

#define | SCL_PORT | PORTD //install the "SoftI2CMaster" as "Wire" d

#define | SDA_PIN | 5 //References:

#define | SDA_PORT | PORTD //http://playground.arduino.cc/Main/So

### include <SoftI2CMaster.h> // https://github.com/felias-fogg/Sof #define I2C_TIMEOUT 1000 // Sets Clock Stretching up to 1sec

#define | I2C_FASTMODE | 1 //Sets 400kHz operating speed

### // ----- Globals -----

### //ADC Globals - Analog ALS, Temp, UV

int ADCpin_AnalogALS = A0;
int ADCpin_AnalogTemp = A1;
int ADCpin_AnalogUV = A2;
int sensorValue = 0;

float sensorConvert = 0;

### //Digital Input Globals - Hall Sensor

int Hall_Out0 = 0;
int Hall_Out1 = 0;

### //I2C globals (using wire library) - Digital ALS

int DigitalALS_DeviceAddress = 0x23;
unsigned char ALS_highByte = 0;
unsigned char ALS_lowByte = 0;
unsigned int ALSReturn = 0;

### //I2C globals (using SoftI2CMaster libary) - MEMs Kionix Sensor

int I2C_check = 0;
int DigitalMEMS_DeviceAddress = 0x1C; //this is the 8bit address,

### //Accel Portion

int MEMS_Accel_Xout_highByte = 0;
int MEMS_Accel_Xout_lowByte = 0; int MEMS_Accel_Yout_highByte = 0; int MEMS_Accel_Yout_lowByte = 0; int MEMS_Accel_Zout_highByte = 0; int MEMS_Accel_Zout_lowByte = 0; int MEMS_Accel_Xout = 0;
int MEMS_Accel_Yout = 0;
int MEMS_Accel_Zout = 0;
float MEMS_Accel_Conv_Xout = 0; float MEMS_Accel_Conv_Yout = 0; float MEMS_Accel_Conv_Zout = 0;

### //Mag Sensor Portion

int MEMS_Mag_Xout_highByte = 0; int MEMS_Mag_Xout_lowByte = 0; int MEMS_Mag_Yout_highByte = 0; int MEMS_Mag_Yout_lowByte = 0; int MEMS_Mag_Zout_highByte = 0; int MEMS_Mag_Zout_lowByte = 0; int MEMS_Mag_Xout = 0;

int MEMS_Mag_Yout = 0;
int MEMS_Mag_Zout = 0;
float MEMS_Mag_Conv_Xout = 0; float MEMS_Mag_Conv_Yout = 0; float MEMS_Mag_Conv_Zout = 0;

### void setup()

{
Wire.begin(); | // start I2C functionality

### Serial.begin(9600); // start serial port at 9600 bps while (!Serial) { ; // wait for serial port to connect. Needed for Leonardo only

}

### pinMode(13, OUTPUT); //Setup for the LED on Board

pinMode(7, INPUT_PULLUP);
pinMode(8, INPUT_PULLUP);

### //----- Start Initialization for BH1721 Digital ALS -----// 1. Send 1 Power On Byte (0x01u) // 2. Send 1 Continuous Auto-Resolution Mode Byte (0x10u or 0x20u) #ifdef DigitalALS

Wire.beginTransmission(DigitalALS_DeviceAddress); Wire.write(0x01u);
Wire.endTransmission();
delay(100);

Wire.beginTransmission(DigitalALS_DeviceAddress); Wire.write(0x10u);
Wire.endTransmission();
delay(100);

### endif //----- END Initialization for BH1721 Digital ALS -----

### //----- Start Initialization for KMX061 Digital Accel/Mag Sensor -#ifdef DigitalMEMs // 1. Standby Register (0x29), write 0x03 (Turn Off) // 2. Self Test Register (0x60), write 0x00

// 3. Control Register 1 (0x2A), write 0x13 // 4. Control Register 2 (0x2B), write 0x00 // 5. ODCNTL Register (0x2C), write 0x00 // 6. Temp EN Register (0x4C), write 0x01 // 7. Buffer CTRL Register 1 (0x78), write 0x00 // 8. Buffer CTRL Register 2 (0x79), write 0x00 // 9. Standby Register (0x29), write 0x0u

I2C_check = i2c_init();

### if(I2C_check == false){ while(1){ Serial.write("I2C Init Failed (SDA or SCL may not be pulled Serial.write(0x0A); //Print Line Feed Serial.write(0x0D); //Print Carrage Return

delay(500);
}
}

### i2c_start(DigitalMEMS_DeviceAddress); //This needs the 8 bit add

i2c_write(0x29);
i2c_write(0x03);
i2c_stop();

### i2c_start(DigitalMEMS_DeviceAddress); //This needs the 8 bit add

i2c_write(0x60);
i2c_write(0x00);
i2c_stop();

### i2c_start(DigitalMEMS_DeviceAddress); //This needs the 8 bit add

i2c_write(0x2A);
i2c_write(0x13);
i2c_stop();

### i2c_start(DigitalMEMS_DeviceAddress); //This needs the 8 bit add

i2c_write(0x2B);
i2c_write(0x00);
i2c_stop();

### i2c_start(DigitalMEMS_DeviceAddress); //This needs the 8 bit add

i2c_write(0x2C);
i2c_write(0x00);
i2c_stop();

### i2c_start(DigitalMEMS_DeviceAddress); //This needs the 8 bit add

i2c_write(0x4C);
i2c_write(0x01);
i2c_stop();

### i2c_start(DigitalMEMS_DeviceAddress); //This needs the 8 bit add

i2c_write(0x78);
i2c_write(0x00);
i2c_stop();

### i2c_start(DigitalMEMS_DeviceAddress); //This needs the 8 bit add

i2c_write(0x79);
i2c_write(0x00);
i2c_stop();

### i2c_start(DigitalMEMS_DeviceAddress); //This needs the 8 bit add

i2c_write(0x29);
i2c_write(0x00);
i2c_stop();

### endif //----- END Initialization for KMX061 Digital Accel/Mag Sensor ---

}

### void loop()

{

digitalWrite(13, HIGH); | // turn the LED on (HIGH is the voltage
delay(250); | // wait for a second
digitalWrite(13, LOW); | // turn the LED off by making the volta
delay(250); | // wait for a second

### //---------- Start Code for Reading BH1620FVC Analog Ambient Ligh

### #ifdef AnalogALS

### //----- Start ADC Read from Port A0 ----

### //Notes on Arduino ADC //Arduino uses an 5V ADC Reference Voltage; thus, we will need to //to 3.3V Levels to safely operate the sensors

//5V = 1024, 3.3V = 670
sensorValue = analogRead(ADCpin_AnalogALS);
Serial.write("ADC Raw Value Return = "); Serial.print(sensorValue);

### Serial.write(0x0A); //Print Line Feed Serial.write(0x0D); //Print Carrage Return

### //Calculations for Analog ALS - BH1620FVC // Note: Device's default configuration is in "High Gain Mode" // Note: Default R1 is 5.6kohm

// Math: ADC_Voltage = (sensorValue / 670) * 3.3V | //
// | ADC_Voltage = sensorValue * (3.3V/670)
// | ADC_Voltage = sensorValue * 0.004925
// | Ev = ADC_Voltage/((0.57x10^-6)*R1), R1 = 5600 | //
// | Ev = ADC_Voltage*(1/(0.57x10^-6*5600))
// | Ev = ADC_Voltage * 313.28
// | Ev = sensorValue * 0.004925 * 313.28
// | Ev = sensorValue * 1.543

sensorConvert = (float)sensorValue*1.543; Serial.write("Analog ALS Converted Return = "); Serial.print(sensorConvert);
Serial.write(" lx");

### Serial.write(0x0A); //Print Line Feed Serial.write(0x0D); //Print Carrage Return #endif //---------- End Code for Reading BH1620FVC Analog Ambient Light S

### //---------- Start Code for Reading BDE0600G Analog Temperature Se #ifdef AnalogTemp

### //----- Start ADC Read from Port A1 ----//Notes on Arduino ADC //Arduino uses an 5V ADC Reference Voltage; thus, we will need to //to 3.3V Levels to safely operate the sensors

//5V = 1024, 3.3V = 670
sensorValue = analogRead(ADCpin_AnalogTemp);
Serial.write("ADC Raw Value Return = "); Serial.print(sensorValue);

### Serial.write(0x0A); //Print Line Feed Serial.write(0x0D); //Print Carrage Return

### //Calculations for Analog Temp Sensor - BDE0600G // Temperature Sensitivity = -10.68mV/degC // Temperature Sensitivity = -0.01068V/degC // Temperature Sensitivity = -93.63degC/V // Temp Known Point = 1.753V @ 30DegC

// Math: ADC_Voltage = (sensorValue / 670) * 3.3V | //
// | ADC_Voltage = sensorValue * (3.3V/670)
// | ADC_Voltage = sensorValue * 0.004925
// | Temperature = (ADC_Voltage - 1.753)/(-0.01068) + 30

sensorConvert = (float)sensorValue * 0.004925; sensorConvert = (sensorConvert - 1.753)/(-0.01068)+30; Serial.write("Analog Temp Sensor Converted Return = "); Serial.print(sensorConvert);
Serial.write(" degC");

### Serial.write(0x0A); //Print Line Feed Serial.write(0x0D); //Print Carrage Return #endif //---------- End Code for Reading BDE0600G Analog Temperature Sens

### //---------- Start Code for Reading ML8511 Analog UV Sensor -----#ifdef AnalogUV

### //----- Start ADC Read from Port A2 ----//Notes on Arduino ADC //Arduino uses an 5V ADC Reference Voltage; thus, we will need to

### //to 3.3V Levels to safely operate the sensors

//5V = 1024, 3.3V = 670
sensorValue = analogRead(ADCpin_AnalogUV); Serial.write("ADC Raw Value Return = "); Serial.print(sensorValue);

### Serial.write(0x0A); //Print Line Feed Serial.write(0x0D); //Print Carrage Return

### //Calculations for UV Sensor - ML8511 //Known Point = 2.2V @ 10mW/cm2 //Rate = 0.129

// Math: ADC_Voltage = (sensorValue / 670) * 3.3V | //
// | ADC_Voltage = sensorValue * (3.3V/670)
// | ADC_Voltage = sensorValue * 0.004925
// | UV Intensity = (ADC_Voltage - 2.2)/(0.129) + 10 | //Conv

sensorConvert = (float)sensorValue * 0.004925;
sensorConvert = (sensorConvert - 2.2)/(0.129)+10; Serial.write("Analog UV Sensor Converted Return = "); Serial.print(sensorConvert);
Serial.write(" mW/cm2");

### Serial.write(0x0A); //Print Line Feed Serial.write(0x0D); //Print Carrage Return #endif //---------- End Code for Reading ML8511 Analog UV Sensor -------

### //---------- Start Code for Reading BU52011HFV Hall Sensor ------#ifdef HallSen //Hardware Connection //For the Hall Sensor, we only need to monitor digital inputs for //Connect Pin1 of Hall Sensor Header U111 to Arduino Pin7 //Connect Pin2 of Hall Sensor Header U111 to Arduino Pin8

Hall_Out0 = digitalRead(7);
Hall_Out1 = digitalRead(8);
Serial.write("HallOut0 = ");
Serial.print(Hall_Out0);

### Serial.write(0x0A); //Print Line Feed

### Serial.write(0x0D); //Print Carrage Return

Serial.write("HallOut1 = "); Serial.print(Hall_Out1);

### Serial.write(0x0A); //Print Line Feed Serial.write(0x0D); //Print Carrage Return #endif //---------- End Code for Reading BU52011HFV Hall Sensor --------

### //---------- Start Code for Reading BH1721 Digital Ambient Light #ifdef DigitalALS // -- Notes on Arduino I2C Connection --//I2C is built in using using the "wire" library

//Uno, Ethernet | A4 (SDA), A5 (SCL) [UNO - THIS is the platf
//Mega2560 | 20 (SDA), 21 (SCL)
//Leonardo | 2 (SDA), 3 (SCL)
//Due | 20 (SDA), 21 (SCL), SDA1, SCL1

// -- Notes on ROHM BH1721 Digital ALS --//Device Address = 0x23u //Intialization Routines (See Setup Function Above) // 1. Send 1 Power On Byte (0x01u) // 2. Send 1 Continuous Auto-Resolution Mode Byte (0x10u or 0x20u //Main Loop Routines // 1. Read 2 Bytes from Sensor, [0][1] // 2. Sensor Out = [0]<<8 | [1] // 3. Convert to Lux = Sensor Out / 1.2

Wire.requestFrom(DigitalALS_DeviceAddress, 2);

### ALS_highByte = Wire.read(); // First Byte Read back is the high ALS_lowByte = Wire.read(); // Second Byte Read back is the low

### ALSReturn = ALS_highByte<<8 | ALS_lowByte; //Store char values i

Serial.write("Digital ALS Raw = ");
Serial.print(ALSReturn);

### Serial.write(0x0A); //Print Line Feed Serial.write(0x0D); //Print Carrage Return

### ALSReturn = ALSReturn / 1.2; //Convert to Lx

Serial.write("Digital ALS Converted Value = ");

### Serial.print(ALSReturn); // print the character

Serial.write(" Lx");

### Serial.write(0x0A); //Print Line Feed Serial.write(0x0D); //Print Carrage Return #endif //---------- End Code for Reading BH1721 Digital Ambient Light S

### //---------- Start Code for Reading KMX61 Kionix Accelerometer+M #ifdef DigitalMEMs // -- Notes on Arduino I2C Connection --//I2C is built in using using the "wire" library

//Uno, Ethernet | A4 (SDA), A5 (SCL) [UNO - THIS is the platf
//Mega2560 | 20 (SDA), 21 (SCL)
//Leonardo | 2 (SDA), 3 (SCL)
//Due | 20 (SDA), 21 (SCL), SDA1, SCL1

### // -- Notes on ROHM KMX61 Accel/Mag Sensor --//Device Address = 0x0Eu //12 Bit Return Value

//Intialization Routines (See Setup function above) // 1. Standby Register (0x29), write 0x03 (Turn Off) // 2. Self Test Register (0x60), write 0x00 // 3. Control Register 1 (0x2A), write 0x13 // 4. Control Register 2 (0x2B), write 0x00 // 5. ODCNTL Register (0x2C), write 0x00 // 6. Temp EN Register (0x4C), write 0x01 // 7. Buffer CTRL Register 1 (0x78), write 0x00 // 8. Buffer CTRL Register 2 (0x79), write 0x00 // 9. Standby Register (0x29), write 0x0u

### //Main Loop Routines // 1. Read 6 Bytes starting from address 0x0A. These will be the // 2. Xout = ([1]<<6) | ([0]>>2) // 3. Yout = ([3]<<6) | ([2]>>2) // 4. Zout = ([5]<<6) | ([4]>>2) // 5. Read 6 Bytes starting from addres 0x12. These will be the

### // 6. Xout = ([1]<<6) | ([0]>>2) // 7. Yout = ([3]<<6) | ([2]>>2) // 8. Zout = ([5]<<6) | ([4]>>2)

### // Start Getting Data from Accel

i2c_start(DigitalMEMS_DeviceAddress);
i2c_write(0x0A);

### i2c_rep_start(DigitalMEMS_DeviceAddress | 1); // Or-ed with "1"

MEMS_Accel_Xout_lowByte = i2c_read(false); MEMS_Accel_Xout_highByte = i2c_read(false); MEMS_Accel_Yout_lowByte = i2c_read(false); MEMS_Accel_Yout_highByte = i2c_read(false); MEMS_Accel_Zout_lowByte = i2c_read(false); MEMS_Accel_Zout_highByte = i2c_read(true);
i2c_stop();

//Note: The highbyte and low byte return a 14bit value, dropping // However, because we need the signed value, we will adjust MEMS_Accel_Xout = (MEMS_Accel_Xout_highByte<<8) | (MEMS_Accel_Xout MEMS_Accel_Yout = (MEMS_Accel_Yout_highByte<<8) | (MEMS_Accel_Yout MEMS_Accel_Zout = (MEMS_Accel_Zout_highByte<<8) | (MEMS_Accel_Zout

### //Note: Conversion to G is as follows:

// | Axis_ValueInG = MEMS_Accel_axis / 1024
// | However, since we did not remove the LSB previously, we n
// | Thus, we will divide the output by 4095 (1024*4) to conve
MEMS_Accel_Conv_Xout = (float)MEMS_Accel_Xout/4096; MEMS_Accel_Conv_Yout = (float)MEMS_Accel_Yout/4096; MEMS_Accel_Conv_Zout = (float)MEMS_Accel_Zout/4096;

### /* //Uncomment if you want to see the Raw Sensor Output

Serial.write("Digital MEMS Raw Accel Xout = "); Serial.print(MEMS_Accel_Xout);

### Serial.write(0x0A); //Print Line Feed Serial.write(0x0D); //Print Carrage Return

Serial.write("Digital MEMS Raw Accel Yout = "); Serial.print(MEMS_Accel_Yout);

### Serial.write(0x0A); //Print Line Feed

### Serial.write(0x0D); //Print Carrage Return

Serial.write("Digital MEMS Raw Accel Zout = "); Serial.print(MEMS_Accel_Zout);

### Serial.write(0x0A); //Print Line Feed Serial.write(0x0D); //Print Carrage Return

*/

Serial.write("Digital MEMS Accel Xout = "); Serial.print(MEMS_Accel_Conv_Xout);

### Serial.write(0x0A); //Print Line Feed Serial.write(0x0D); //Print Carrage Return

Serial.write("Digital MEMS Accel Yout = "); Serial.print(MEMS_Accel_Conv_Yout);

### Serial.write(0x0A); //Print Line Feed Serial.write(0x0D); //Print Carrage Return

Serial.write("Digital MEMS Accel Zout = "); Serial.print(MEMS_Accel_Conv_Zout);

### Serial.write(0x0A); //Print Line Feed Serial.write(0x0D); //Print Carrage Return

### // Start Getting Data from Mag Sensor

i2c_start(DigitalMEMS_DeviceAddress);
i2c_write(0x12);

### i2c_rep_start(DigitalMEMS_DeviceAddress | 1); // Or-ed with "1"

MEMS_Mag_Xout_lowByte = i2c_read(false); MEMS_Mag_Xout_highByte = i2c_read(false); MEMS_Mag_Yout_lowByte = i2c_read(false); MEMS_Mag_Yout_highByte = i2c_read(false); MEMS_Mag_Zout_lowByte = i2c_read(false); MEMS_Mag_Zout_highByte = i2c_read(true);
i2c_stop();

//Note: The highbyte and low byte return a 14bit value, dropping // However, because we need the signed value, we will adjust MEMS_Mag_Xout = (MEMS_Mag_Xout_highByte<<8) | (MEMS_Mag_Xout_lowB MEMS_Mag_Yout = (MEMS_Mag_Yout_highByte<<8) | (MEMS_Mag_Yout_lowB MEMS_Mag_Zout = (MEMS_Mag_Zout_highByte<<8) | (MEMS_Mag_Zout_lowB

### //Note: Conversion to G is as follows:

// | Axis_ValueInG = MEMS_Accel_axis / 1024
// | However, since we did not remove the LSB previously, we n
// | Thus, we will divide the output by 4095 (1024*4) to conve
MEMS_Mag_Conv_Xout = (float)MEMS_Mag_Xout*0.146; MEMS_Mag_Conv_Yout = (float)MEMS_Mag_Yout*0.146; MEMS_Mag_Conv_Zout = (float)MEMS_Mag_Zout*0.146;

### /* //Uncomment if you want to see the Raw Sensor Output

Serial.write("Digital MEMS Raw Mag Xout = "); Serial.print(MEMS_Mag_Xout);

### Serial.write(0x0A); //Print Line Feed Serial.write(0x0D); //Print Carrage Return

Serial.write("Digital MEMS Raw Mag Yout = "); Serial.print(MEMS_Mag_Yout);

### Serial.write(0x0A); //Print Line Feed Serial.write(0x0D); //Print Carrage Return

Serial.write("Digital MEMS Raw Mag Zout = "); Serial.print(MEMS_Mag_Zout);

### Serial.write(0x0A); //Print Line Feed Serial.write(0x0D); //Print Carrage Return

*/

Serial.write("Digital MEMS Mag Xout = "); Serial.print(MEMS_Mag_Conv_Xout);

### Serial.write(0x0A); //Print Line Feed Serial.write(0x0D); //Print Carrage Return

Serial.write("Digital MEMS Mag Yout = "); Serial.print(MEMS_Mag_Conv_Yout);

### Serial.write(0x0A); //Print Line Feed Serial.write(0x0D); //Print Carrage Return

Serial.write("Digital MEMS Mag Zout = "); Serial.print(MEMS_Mag_Conv_Zout);

### Serial.write(0x0A); //Print Line Feed Serial.write(0x0D); //Print Carrage Return

### endif //---------- END Code for Reading KMX61 Kionix Accelerometer+M

### Serial.write(0x0A); //Print Line Feed Serial.write(0x0D); //Print Carrage Return

}

### void I2C_CheckACK()

{

### if(I2C_check == false){ while(1){

Serial.write("No ACK!");

### Serial.write(0x0A); //Print Line Feed Serial.write(0x0D); //Print Carrage Return

delay(500);
}
}
}

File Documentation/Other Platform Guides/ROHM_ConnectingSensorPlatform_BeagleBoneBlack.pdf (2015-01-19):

Connecting ROHM’s Sensor Platform Kit to the BeagleBone Black Platform ROHM-SENSEKIT1-EVK-101-ND
12 January, 2015 – Revision A

## Connecting the Sensor Platform Kit to the BeagleBone Black Platform

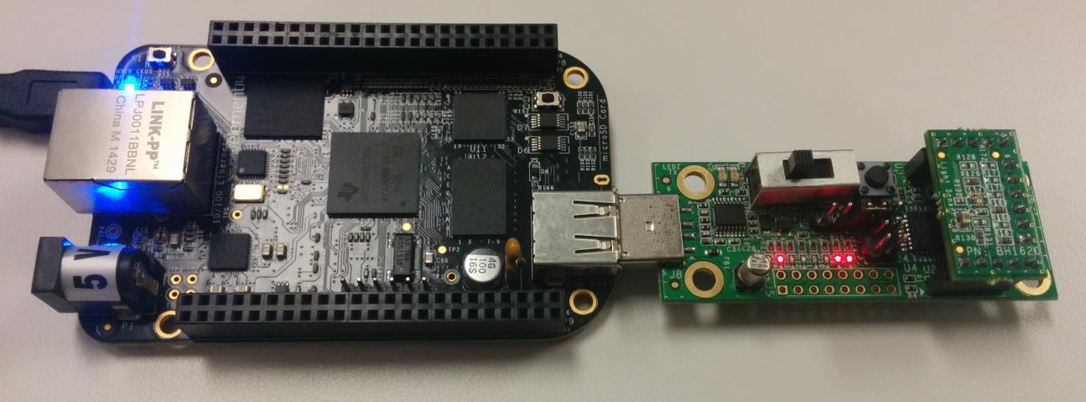
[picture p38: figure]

Above: ROHM Sensor Platform Base Board connected to the BeagleBone Black

12 January 2015, Revision A

ROHM-SENSEKIT1-EVK-101-ND
12 January, 2015 – Revision A

### Table of Contents

### Copyright and License

BeagleBone Black and all content associated to beagleboard.org are licensed under a Creative Commons Attribution-Share Alike 3.0 license. For additional information, please see http://beagleboard.org/terms for additional information

Please note that all references to ROHM’s Sensor Platform Kit are also shared under open source guidelines under the GNU General Public License, Version 3. Details can be found at the following link: https://github.com/ROHMUSDC/ROHMSensorPlatformEVK.

### Revision History

Date | Description | Revision ID
19 January 2015 | First Draft | A

ROHM-SENSEKIT1-EVK-101-ND
12 January, 2015 – Revision A

### Introduction

The following document was written to provide a brief connection guide and starting point for using ROHM’s Sensor Platform Kit with the BeagleBone Black platform of boards. This guide assumes that the user has basic functional knowledge of both the Sensor Platform Kit and the BeagleBone Black itself. If this is not correct, please see the following links for other guides and information on these products.

ROHM’s Sensor Platform Kit: https://github.com/ROHMUSDC/ROHMSensorPlatformEVK

BeagleBone Black Platform: http://beagleboard.org/getting-started

### Getting Started

1. Initial Setup
a. ROHM Sensor Platform Kit
i. The Sensor Platform Base Board can be connected to the BeagleBone Black Platform directly via USB; thus, there are no pre-requisites for this side of the system
ii. We would recommend a USB-A to USB-B extender to allow for movement of the sensor base board while connected to the BeagleBone Black.
b. The following are recommended for using the BeagleBone Black for this guide
i. Need to be able to access the linux console for the BeagleBone Black (this guide uses the console access provided in the cloud9 ide.

### Connecting the Sensor Platform UART Output to the BeagleBone Black (Using the Console)

1. The Sensor Platform Board uses FTDI’s FT230XS-R as the on board UART to USB Bridge for data transmission.
2. For this guide, we will explain how to connect the sensor platform kit to BeagleBone Black’s Linux OS using the VCP drivers built into the linux kernel. For additional support on D2XX driver, please see FTDI’s installation guide for Linux.
a. http://www.ftdichip.com/Support/Documents/AppNotes/AN_220_FTDI_Drivers_Installation_Guide_for_Linux%20.pdf (http://www.ftdichip.com/Support/Documents/AppNotes/AN_220_FTDI_Drivers_Installation_Guide_for_Linux%20.pdf)
3. Connect the sensor platform base kit and any sensor to the BeagleBone Black hardware using any USB slot connector.
4. Next, check to see if the VCP drivers are working correctly by entering the following into the command line:
a. In the Cloud9 console window, navigate to root (using “cd ..” command)
b. Once at the root, type in the following message to check if the VCP drivers are working correctly

ROHM-SENSEKIT1-EVK-101-ND
12 January, 2015 – Revision A
i. “dmesg | grep FTDI”
c. The message should return with the information in the picture below

i.

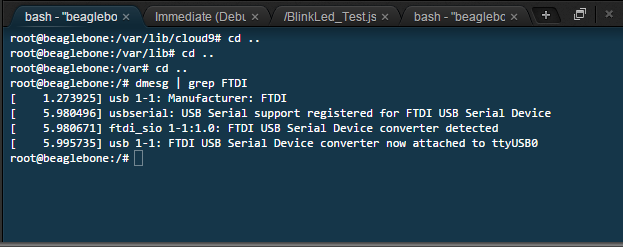
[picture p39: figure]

5. Since this FTDI chip is essentially a COM port, we can easily view the data stream through the console using “screen” application by typing the following command
a. “screen /dev/ttyUSB0”
i. *Note, please use whichever USB device returned from the above “dmesg | grep FTDI” command instead of ttyUSB0
b. If done correctly, a new console window will open showing the streaming data from the device. See below for a picture

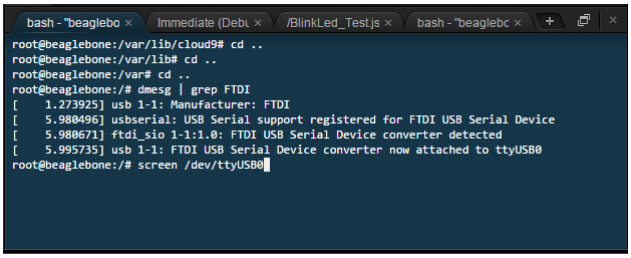
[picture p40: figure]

c.

ROHM-SENSEKIT1-EVK-101-ND
12 January, 2015 – Revision A

d.

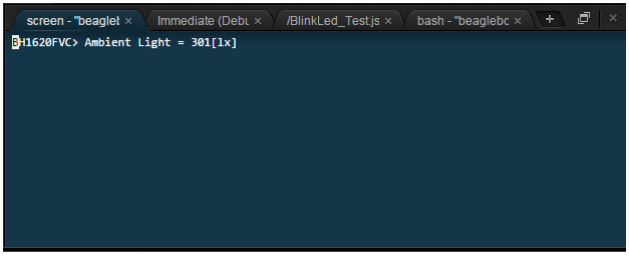
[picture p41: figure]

i. Note: you can return to the terminal by using the keyboard command “ctrl + A + D”. You can then return to this screen output via terminal by using the
command “screen –rd”

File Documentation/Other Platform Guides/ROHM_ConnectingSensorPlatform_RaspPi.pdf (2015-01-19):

Connecting ROHM’s Sensor Platform Kit to the Raspberry Pi Platform ROHM-SENSEKIT1-EVK-101-ND
12 January, 2015 – Revision A

## Connecting the Sensor Platform Kit to the Raspberry Pi Platform

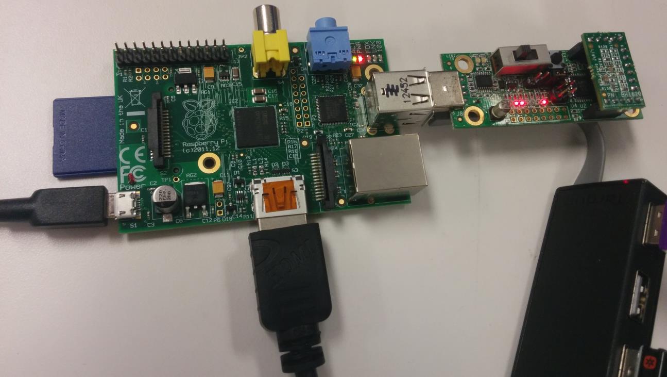
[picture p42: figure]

Above: ROHM Sensor Platform Base Board connected to the Raspberry Pi

12 January 2015, Revision A

ROHM-SENSEKIT1-EVK-101-ND
12 January, 2015 – Revision A

### Table of Contents

### Copyright and License

Raspberry Pi is a trademark of the Raspberry Pi Foundation. For additional information, please see http://www.raspberrypi.org/

Please note that all references to ROHM’s Sensor Platform Kit are also shared under open source guidelines under the GNU General Public License, Version 3. Details can be found at the following link: https://github.com/ROHMUSDC/ROHMSensorPlatformEVK.

### Revision History

Date | Description | Revision ID
12 January 2015 | First Draft | A

ROHM-SENSEKIT1-EVK-101-ND
12 January, 2015 – Revision A

### Introduction

The following document was written to provide a brief connection guide and starting point for using ROHM’s Sensor Platform Kit with the Raspberry Pi Platform of boards. This guide assumes that the user has basic functional knowledge of both the Sensor Platform Kit and the Raspberry Pi itself. If this is not correct, please see the following links for other guides and information on these products.

ROHM’s Sensor Platform Kit: https://github.com/ROHMUSDC/ROHMSensorPlatformEVK

Raspberry Pi Platform: http://www.raspberrypi.org/

### Getting Started

1. Initial Setup
a. ROHM Sensor Platform Kit
i. The Sensor Platform Base Board can be connected to the Raspberry Pi Platform directly via USB; thus, there are no pre-requisites for this side of the system
ii. We would recommend a USB-A to USB-B extender to allow for movement of the sensor base board while connected to the Raspberry Pi.
b. The following are recommended for using the Raspberry Pi for this guide
i. Raspian OS installed through NOOBS
1. http://www.raspberrypi.org/help/noobs-setup/ii. USB Cable (micro B) for Power
iii. HDMI Cable and Monitor for Display
iv. USB Mouse and Keyboard for User Input
v. WiFi Dongle for Internet Connectivity

### Connecting the Sensor Platform UART Output to the Raspberry Pi (Using the Console)

1. The Sensor Platform Board uses FTDI’s FT230XS-R as the on board UART to USB Bridge for data transmission.
2. For this guide, we will explain how to connect the sensor platform kit to Raspberry Pi’s Raspian OS using the VCP drivers built into the linux kernel. For additional support on D2XX driver, please see FTDI’s installation guide for Linux.
a. http://www.ftdichip.com/Support/Documents/AppNotes/AN_220_FTDI_Drivers_Installation_Guide_for_Linux%20.pdf (http://www.ftdichip.com/Support/Documents/AppNotes/AN_220_FTDI_Drivers_Installation_Guide_for_Linux%20.pdf)
3. Connect the sensor platform base kit and any sensor to the Raspberry Pi hardware using any USB slot connector.
4. Next, check to see if the VCP drivers are working correctly by entering the following into the command line:

ROHM-SENSEKIT1-EVK-101-ND
12 January, 2015 – Revision A
a. “dmesg | grep FTDI”
b. The message should return with the information in the picture below

c.

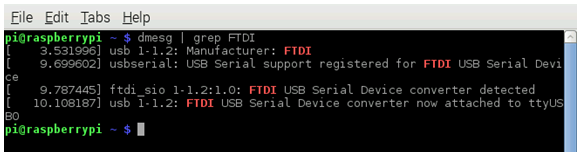
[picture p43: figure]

5. Since this FTDI chip is essentially a COM port, we can easily view the data stream through the console using “screen” application
a. In the console, type the following to install “screen”
i. “sudo apt-get install screen”
6. We can now access the COM port by using the screen application using the following command
a. “screen /dev/ttyUSB0”
i. *Note, please use whichever USB device returned from the above “dmesg | grep FTDI” command instead of ttyUSB0
b. If done correctly, a new console window will open showing the streaming data from the device. See below for a picture

ROHM-SENSEKIT1-EVK-101-ND
12 January, 2015 – Revision A

c.


i. Note: you can return to the terminal by using the keyboard command “ctrl + A + D”. You can then return to this screen output via terminal by using the
command “screen –rd”

### Connecting the Sensor Platform UART Output to the Raspberry Pi (Using Graphical Interfaces)

7. The Sensor Platform Board uses FTDI’s FT230XS-R as the on board UART to USB Bridge for data transmission.
8. For this guide, we will explain how to connect the sensor platform kit to Raspberry Pi’s Raspian OS using the VCP drivers built into the linux kernel. For additional support on D2XX driver, please see FTDI’s installation guide for Linux.
a. http://www.ftdichip.com/Support/Documents/AppNotes/AN_220_FTDI_Drivers_Installation_Guide_for_Linux%20.pdf (http://www.ftdichip.com/Support/Documents/AppNotes/AN_220_FTDI_Drivers_Installation_Guide_for_Linux%20.pdf)
9. After you’ve booted up your raspian distribution and with a stable internet connection, install Putty by entering the following text into the command line:
a. “sudo apt-get install putty -y”
10. After this installation has completed, connect the sensor platform base kit and any sensor to the Raspberry Pi hardware using any USB slot connector.

ROHM-SENSEKIT1-EVK-101-ND
12 January, 2015 – Revision A
11. Next, check to see if the VCP drivers are working correctly by entering the following into the command line:
a. “dmesg | grep FTDI”
b. The message should return with the information in the picture below

c.


d. *Please keep a note of the port that this device in connected to. In the above picture, the Port is “ttyUSB0”
12. Next, open the newly installed Putty
13. In the far left side under “categories”, scroll all the way down to serial. This will show options for using putty to connect to a serial port. Edit the fields to match the below settings (Adjust the “serial line to connect to” field to match the port as shown in the console above).

a.


14. In Putty, scroll back up to the “Session” category and change the connection type to “Serial”. Then click the “Open” Button


ROHM-SENSEKIT1-EVK-101-ND
12 January, 2015 – Revision A

a.
15. Upon opening this connection, you should see the sensor data stream into the putty console.

a.
b. Resetting the base board will show the firmware revision indication as well as the connected sensor data

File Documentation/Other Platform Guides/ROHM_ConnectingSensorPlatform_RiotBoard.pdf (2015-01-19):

Connecting ROHM’s Sensor Platform Kit to the RIoTboard Platform ROHM-SENSEKIT1-EVK-101-ND
12 January, 2015 – Revision A

## Connecting the Sensor Platform Kit to the RIoTboard


Above: ROHM Sensor Platform Base Board connected to the RIoTboard

12 January 2015, Revision A

ROHM-SENSEKIT1-EVK-101-ND
12 January, 2015 – Revision A

### Table of Contents

### Copyright and License

RIoTboard Open Source Development Platrform by RIoTboard.org is licensed under a Creative Commons Attribution-ShareAlike 4.0 International License. All references to the “RIoTboard” are based on a work at RIoTboard.org.

Please note that all references to ROHM’s Sensor Platform Kit are also shared under open source guidelines under the GNU General Public License, Version 3. Details can be found at the following link: https://github.com/ROHMUSDC/ROHMSensorPlatformEVK.

### Revision History

Date | Description | Revision ID
12 January 2015 | First Draft | A

ROHM-SENSEKIT1-EVK-101-ND
12 January, 2015 – Revision A

### Introduction

The following document was written to provide a brief connection guide and starting point for using ROHM’s Sensor Platform Kit with the RIoTboard. This guide assumes that the user has basic functional knowledge of both the Sensor Platform Kit and the Riot Board itself. If this is not correct, please see the following links for other guides and information on these products.

ROHM’s Sensor Platform Kit: https://github.com/ROHMUSDC/ROHMSensorPlatformEVK

RIoTboard: http://riotboard.org/

### Getting Started

1. Initial Setup
a. ROHM Sensor Platform Kit
i. The Sensor Platform Base Board can be connected to the RIoTboard directly via USB; thus, there are no pre-requisites for this side of the system
ii. We would recommend a USB-A to USB-B extender to allow for movement of the sensor base board while connected to the RIoTboard.
b. The following are recommended for using the RIoTboard for this guide
i. Barrel Connector for Power
ii. HDMI Cable and Monitor for Display (Or LVDS)
iii. USB Mouse and Keyboard for User Input
iv. WiFi Dongle for Internet Connectivity

### Connecting the Sensor Platform UART Output to the RIoTboard

1. The Sensor Platform Board uses FTDI’s FT230XS-R as the on board UART to USB Bridge for data transmission
2. FTDI has also built drivers and sample android applications that help to interface onto Android based operating systems.
a. Download and install FTDI’s “UART Terminal Application” APK from the following website (http://www.ftdichip.com/Android.htm)
i. Source Code:
1. http://www.ftdichip.com/Support/SoftwareExamples/Android/J2xxHyp erTerm.7z (http://www.ftdichip.com/Support/SoftwareExamples/Android/J2xxHyperTerm.7z)
ii. Direct Link to APK:
1. http://www.ftdichip.com/Support/SoftwareExamples/Android/J2xxHyp erTerm.zip (http://www.ftdichip.com/Support/SoftwareExamples/Android/J2xxHyperTerm.zip)
iii. Link to Play Store:
1. https://play.google.com/store/apps/details?id=com.ftdi.j2xx.hyperterm&hl=en (https://play.google.com/store/apps/details?id=com.ftdi.j2xx.hyperterm&hl=en)

ROHM-SENSEKIT1-EVK-101-ND
12 January, 2015 – Revision A

b.

c.


3. After completing the installation of this application, connect the Sensor platform Base board to the RIoTboard using one of the available USB Ports.
4. Open the “FTDI UART Terminal Application”. Upon correct connection, you will see two messages flash on the screen:
a. “1 port device attached”


ROHM-SENSEKIT1-EVK-101-ND
12 January, 2015 – Revision A

i.
b. “Port 0; UART Setting – Baudrate:9600 StopBit:1 DataBit:8 Parity:None FlowControl:CTS/RTS”

i.
5. Edit the control settings by clicking the “settings button” (three dots on the upper right side of the application) and click “settings”. Below the writing portion of the console, you will see additional UART settings
a. Adjust these settings to the below options:

ROHM-SENSEKIT1-EVK-101-ND
12 January, 2015 – Revision A

i.


ii. Note: the only major change is the “flow control” set to “None”
b. Upon the Sensor Reset (pressing the PB on the board), firmware information along with additional sensor platform sensor information should be returned by the sensor platform itself.

### Other Notes and Considerations

1. Please note that the FTDI UART application is not optimized for some of the special function commands sent via UART (such as the clear line, etc..); thus, you will see the sensor data return in a streaming format.
2. From this guide you can now generate your own applications using these sensor solutions by using and understanding the below three topics
a. Building an Android App on the RIoTboard
i. http://www.element14.com/community/community/designcenter/singleboard-computers/riotboard//blog/2014/01/24/publishing-my-first-android-appon-riotboard (http://www.element14.com/community/community/designcenter/single-board-computers/riotboard/blog/2014/01/24/publishing-my-first-android-app-on-riotboard)
b. Source Code for FTDI Console:
i. http://www.ftdichip.com/Support/SoftwareExamples/Android/J2xxHyperTerm. 7z (http://www.ftdichip.com/Support/SoftwareExamples/Android/J2xxHyperTerm.7z)
c. Source Code for ROHM’s Sensor Platform Kit:
i. https://github.com/ROHMUSDC/ROHMSensorPlatformEVK

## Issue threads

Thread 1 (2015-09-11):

BH1680 Sensor Support with this Kit?

kbahar, 2015-09-11:
How do I evaluate the BH1680 Analog ALS sensor using this Sensor Platform Kit?

kbahar, 2015-09-11:
* The existing sensor kit has the BH1620 analog Ambient Light sensor.
* BH1680 Analog ALS is very similar to the BH1620 in terms of specification and packaging.
* The only major difference I noticed was that the illuminance detection for the BH1620 is higher at the lowest gain setting (100k lx range on BH1620 vs. 50k lux range on BH1680)
  * I would understand the need for BH1680 only if the user has a very specific range of illuminance (AKA, one gain setting) to measure as each gain mode requires different external components (calculations shown below).  The BH1620 simplifies this and would be better if they have to detect a higher illuminance range and need to switch gain settings on the fly as all settings use the same output resistance.
* Thus, it seems like the BH1620 would be a better part to use since it has the higher illuminance detection and same settings for different gain modes...
  * Can the customer use the BH1620?
  * If not, can they use the BH1620 to evaluate initially before finalizing their design with the BH1680?
  * Or is there a reason for needing the BH1680 sensor specifically that I may have missed?

If they absolutely need to connect the BH1680 to our board we can do this with a little rework:
* On the existing BH1620 board, we would want to change the following
  * Replace the BH1620 with the BH1680 IC.  Footprint and pinout is the same, so no need to spin a new board
  * Change the gain setting resistor depending on the customer’s application
    * H-Gain: R132 = 3.3V / ( (6.1*10^-6) * 100 ) = 5.409 kohm
    * M-Gain: R132 = 3.3/ ( (0.61*10^-6) * 1000)  = 5.409 kohm
    * L-Gain: R132 = 3.3/ ( (0.061*10^-6) * 50000)  = 1.081 kohm
    * See page 4 of the BH1680 datasheet for additional information on these calculations
      * http://rohmfs.rohm.com/en/products/databook/datasheet/ic/sensor/light/bh1680fvc-e.pdf

Closed 2015-09-11.

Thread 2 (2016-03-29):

Question: How to I save logs from this sensor kit?

kbahar, 2016-03-29:
For this example, we will run this for the KMX61 connected to the sensor platform base board.

1.	Connect the KMX61 to the sensor platform base board.  Connect the base board to the PC.
2.	Upon connecting, the PC should recognize the USB to COM port connection.  If it does not, you can download the drivers from the following link:
    1.	http://www.ftdichip.com/Drivers/VCP.htm
3.	Next, I’m going to use TeraTerm to connect and log the output.  You can download teraterm below:
    1.	https://ttssh2.osdn.jp/index.html.en
4.	When the environment is setup, open tera term.  Select “File -> New Connection”.  Then check the “serial” box and connect to the USB serial port of the connect sensor platform kit.  Click OK to start the connection:
    1.
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

5.	Then, In TeraTerm, go to “File -> Log”.  Choose a place and name for the log file.
6.	Next, take all the measurement you want my moving the board as required (move the board around as required to make accel/mag values change)
7.	When done logging, go to “File -> Show Log dialog…”.  Then click “close”.
8.	Next, view the log file in Excel:
    1.	Note: since it is  in a *.log format, you will need to open this directly from excel or use the “right click -> open with” option in windows
    2.	In this walkthrough, I’m going to open it in excel.  When doing so, move to the directory where this file is located and be sure to adjust the viewable files to “all files”
        1.
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

    3.	Next, the “text import wizard” will be started.  On the first screen, change the data type to “Delimited”.  Then click Next
        1.
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

    4.	Next, we can select the delimiters for our data set.  I would recommend using “comma”, “space”,  “Other: [”, and “Treat consecutive delimiters as one”.  Then click next
        1.
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

    5.	On the last step, you can set the data type of each of the columns.  However, I typically leave these as is and click “Finish”
    6.	Now, All your data is within Excel!
        1.
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

            1.	Feel free to adjust the data as needed.  I noticed that the first and last rows had incomplete rows, so I deleted them.
            2.	Then I deleted the text columns of titles and moved it to the top row to re-adjust.
        2.	Final Result looks as follows:
            1.
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

            1.	Of course, from here, you can do what you need with the data (save it in Excel, apply algorithms, save as CSV, etc…)

Closed 2016-03-29.

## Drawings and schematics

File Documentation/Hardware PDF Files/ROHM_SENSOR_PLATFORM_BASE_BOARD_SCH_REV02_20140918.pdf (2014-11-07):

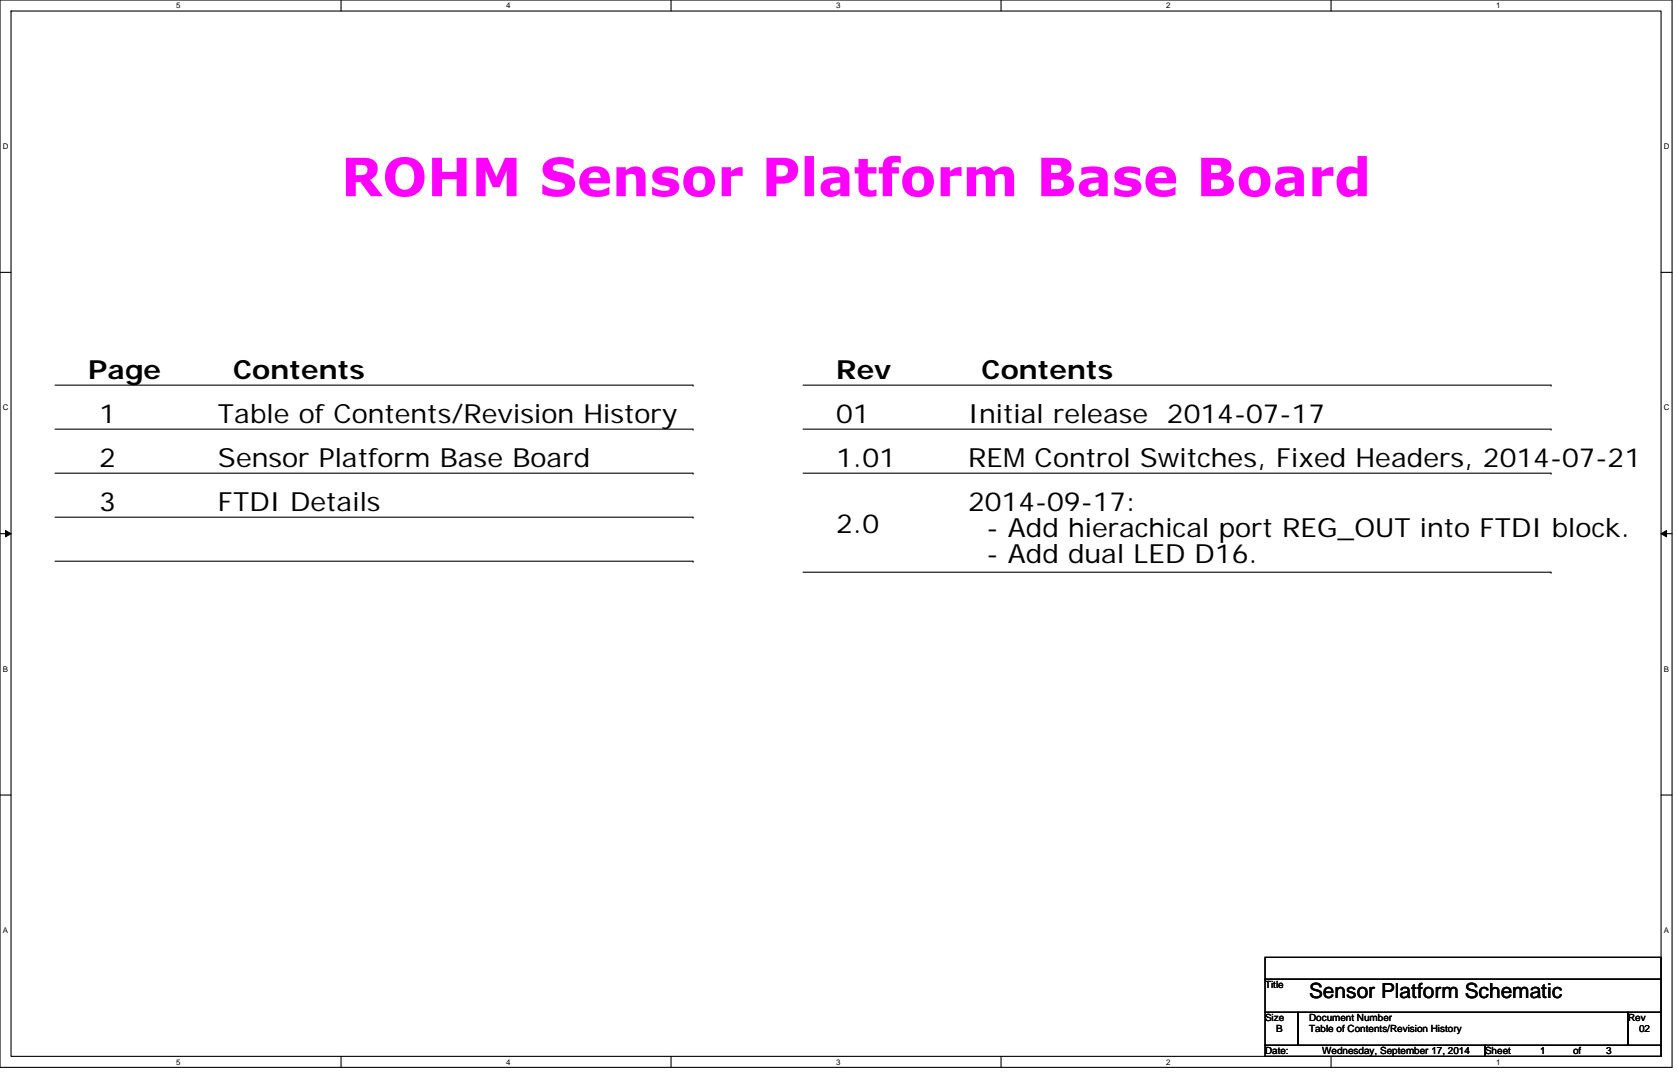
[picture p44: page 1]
REM Control Switches, Fixed Headers, 2014-07-21; Page; Contents; Table of Contents/Revision History; Sensor Platform Base Board; FTDI Details; Rev; Initial release 2014-07-17

- Add hierachical port REG_OUT into FTDI block.
- Add dual LED D16.

Title
Sensor Platform Schematic

Size Size Size B | Document Number Document Number Document Number Table of Contents/Revision History Table of Contents/Revision History Table of Contents/Revision History | Rev Rev Rev 02 02 02

Date: Wednesday, September 17, 2014 Wednesday, September 17, 2014 Wednesday, September 17, 2014 | Sheet 1 1 1 of 3 3 3

# INPUT POWER

# RESET MCUs

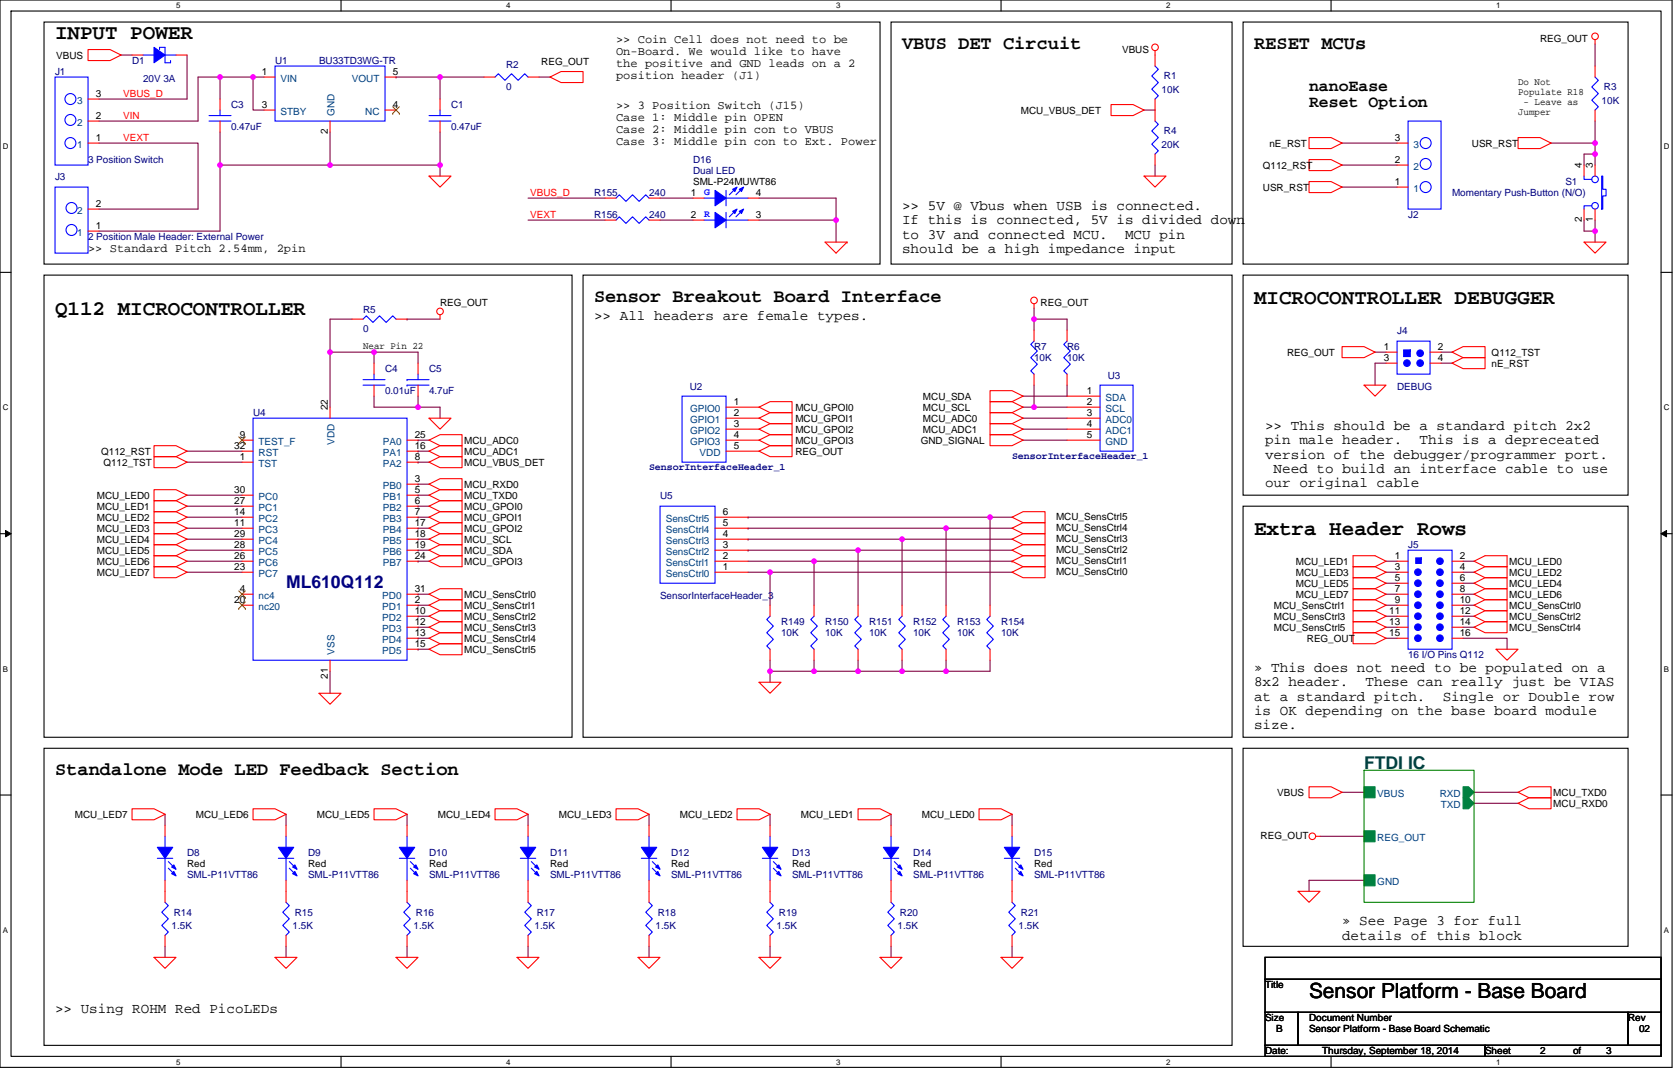
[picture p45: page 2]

>> Coin Cell does not need to be
On-Board. We would like to have
the positive and GND leads on a 2
position header (J1)

>> 3 Position Switch (J15)
Case 1: Middle pin OPEN
Case 2: Middle pin con to VBUS
Case 3: Middle pin con to Ext. Power

>> 5V @ Vbus when USB is connected.
If this is connected, 5V is divided down
to 3V and connected MCU. MCU pin

Sensor Breakout Board Interface
>> All headers are female types.

>> This should be a standard pitch 2x2
pin male header. This is a depreceated
version of the debugger/programmer port.
Need to build an interface cable to use
our original cable
Extra Header Rows

» This does not need to be populated on a
8x2 header. These can really just be VIAS
at a standard pitch. Single or Double row
is OK depending on the base board module
size.

Standalone Mode LED Feedback Section

» See Page 3 for full
details of this block

Title
Sensor Platform - Base Board

>> Using ROHM Red PicoLEDs

Size Size Size | Document Number Document Number Document Number Sensor Platform - Base Board Schematic Sensor Platform - Base Board Schematic Sensor Platform - Base Board Schematic | Rev Rev Rev 02 02 02

Thursday, September 18, 2014 Thursday, September 18, 2014 Thursday, September 18, 2014 | 2 2 2 3 3 3

# USB to serial UART interface

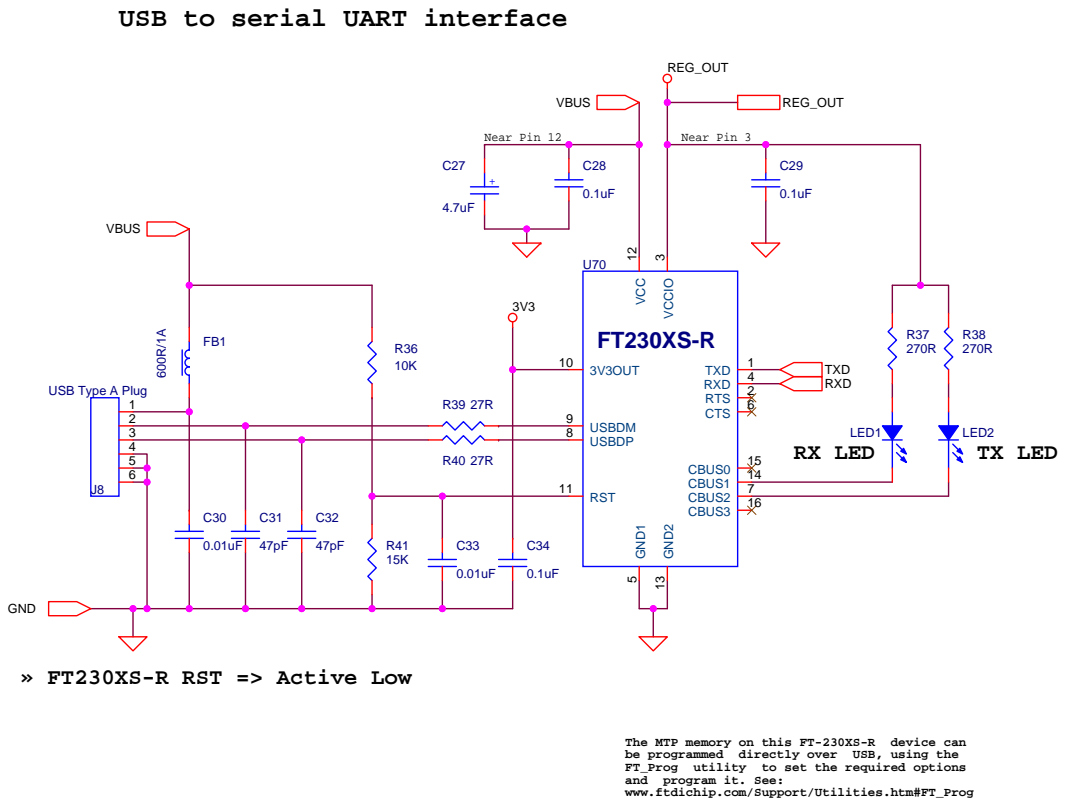
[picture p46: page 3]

3 | USBDP 8
4 | | RST 11

The MTP memory on this FT-230XS-R device can
be programmed directly over USB, using the
FT_Prog utility to set the required options
and program it. See:
www.ftdichip.com/Support/Utilities.htm#FT_Prog

Title
Sensor Platform - Base Board FTDI IC

Size Size Size | Document Number Document Number Document Number FTDI Portion of Circuit FTDI Portion of Circuit FTDI Portion of Circuit | Rev Rev Rev 02 02 02

Thursday, September 18, 2014 Thursday, September 18, 2014 Thursday, September 18, 2014 | 3 3 3

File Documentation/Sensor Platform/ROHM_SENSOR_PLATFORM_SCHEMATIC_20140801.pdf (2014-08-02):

D | D

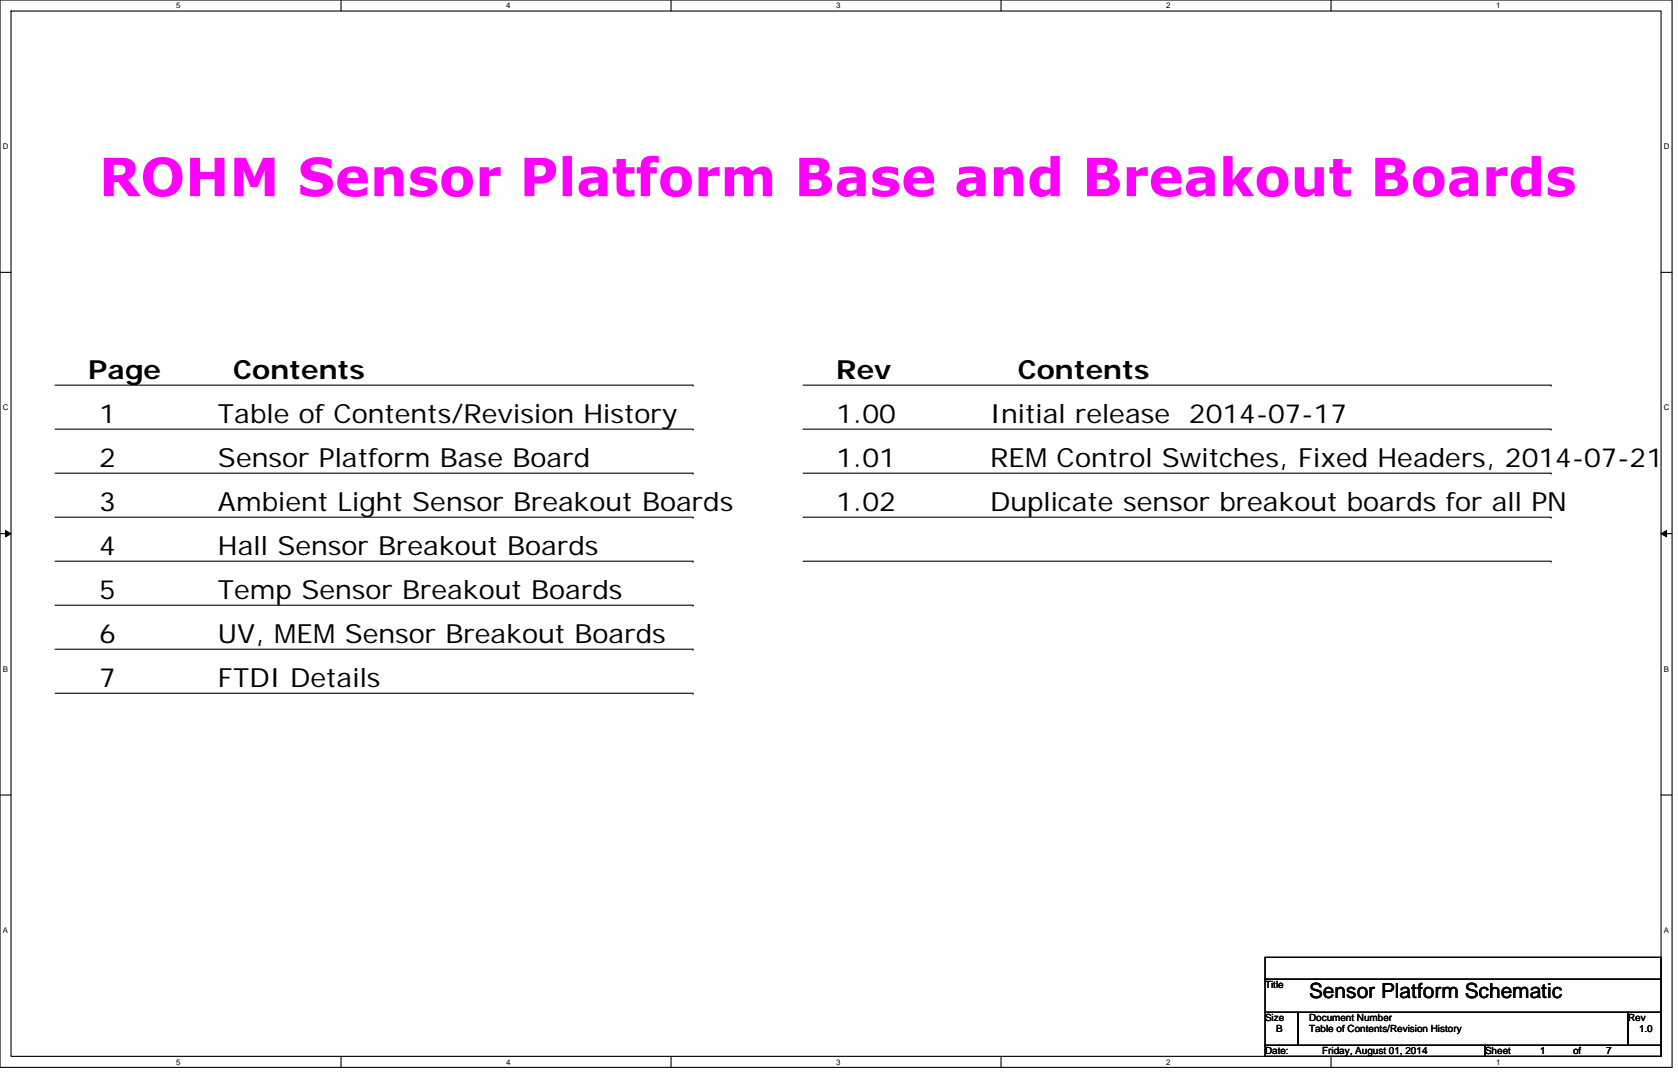
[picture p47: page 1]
REM Control Switches, Fixed Headers, 2014-07-21; Hall Sensor Breakout Boards; Page; Contents; Table of Contents/Revision History; Sensor Platform Base Board; FTDI Details; Rev; Initial release 2014-07-17; Ambient Light Sensor Breakout Boards; Temp Sensor Breakout Boards; UV, MEM Sensor Breakout Boards; Duplicate sensor breakout boards for all PN

Title
Sensor Platform Schematic

Size Size Size B | Document Number Document Number Document Number Table of Contents/Revision History Table of Contents/Revision History Table of Contents/Revision History | Rev Rev Rev 1.0 1.0 1.0

Date: Friday, August 01, 2014 Friday, August 01, 2014 Friday, August 01, 2014 | Sheet 1 1 1 of 7 7 7

D | D

# INPUT POWER

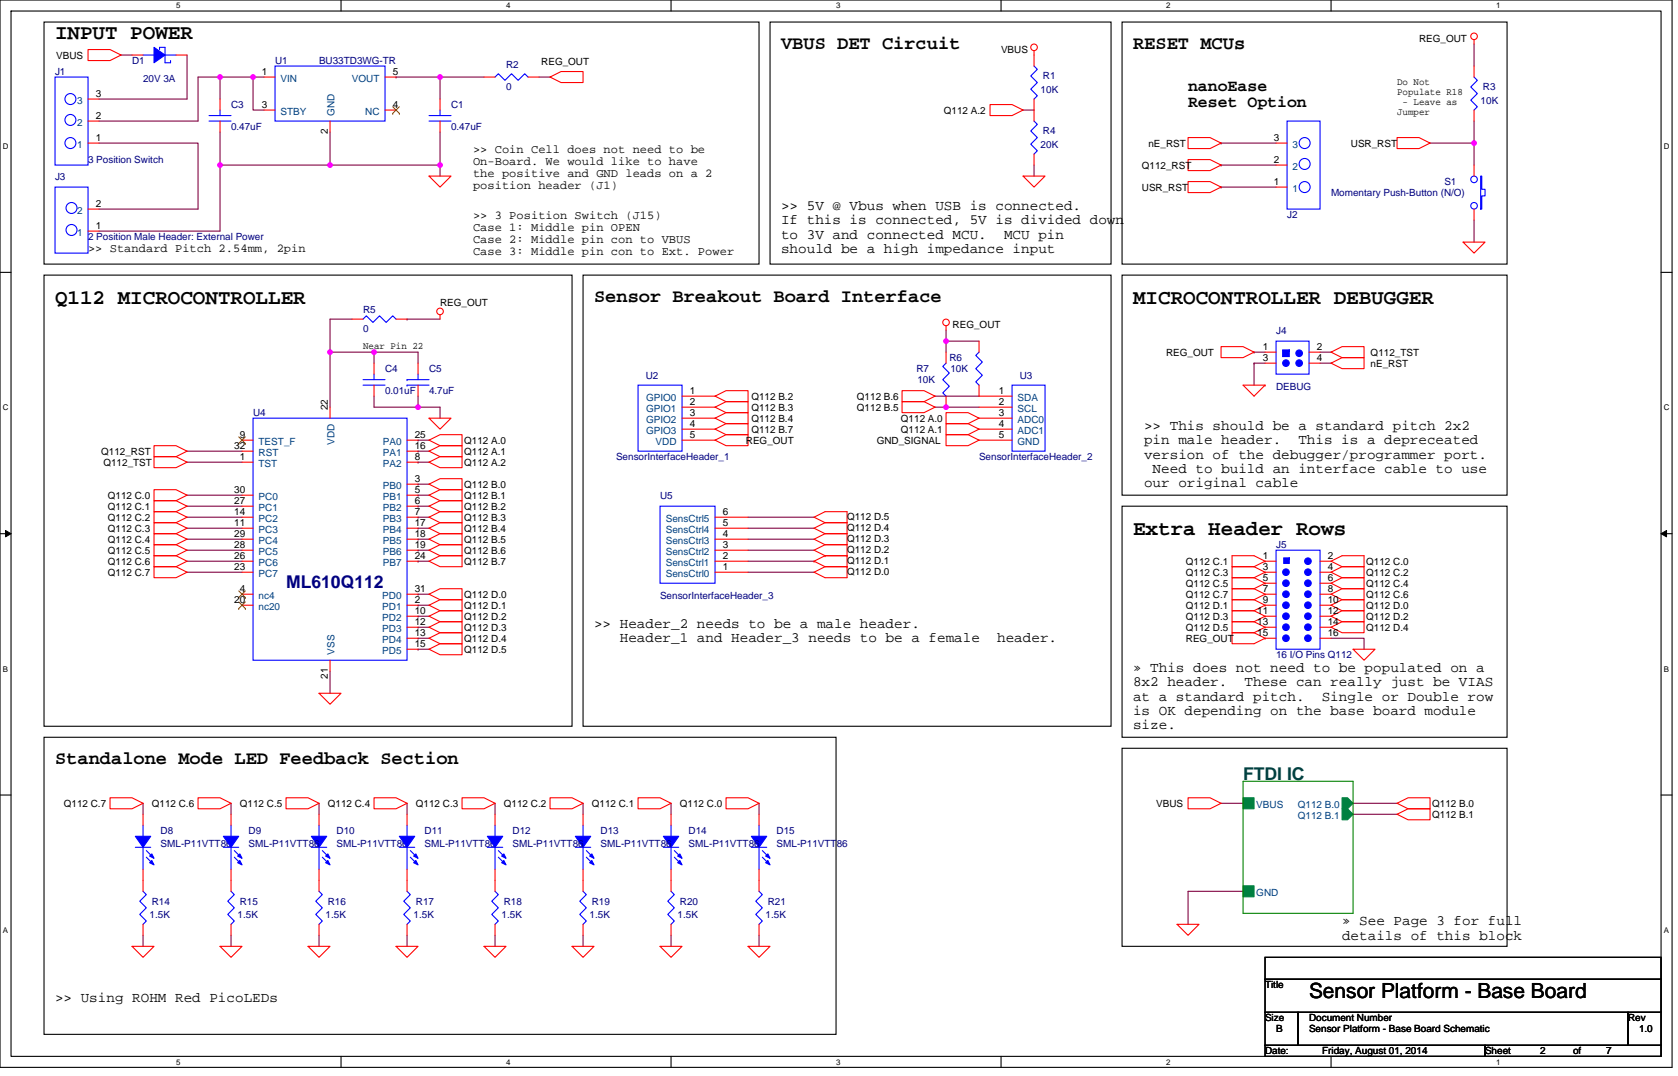
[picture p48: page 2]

>> Coin Cell does not need to be
On-Board. We would like to have
the positive and GND leads on a 2
position header (J1)

>> 5V @ Vbus when USB is connected.
If this is connected, 5V is divided down
to 3V and connected MCU. MCU pin

>> 3 Position Switch (J15)
Case 1: Middle pin OPEN
Case 2: Middle pin con to VBUS
Case 3: Middle pin con to Ext. Power

Sensor Breakout Board Interface

>> This should be a standard pitch 2x2
pin male header. This is a depreceated
version of the debugger/programmer port.
Need to build an interface cable to use
our original cable
Extra Header Rows

>> Header_2 needs to be a male header.
Header_1 and Header_3 needs to be a female header.

» This does not need to be populated on a
8x2 header. These can really just be VIAS
at a standard pitch. Single or Double row
is OK depending on the base board module
size.

Standalone Mode LED Feedback Section

» See Page 3 for full
details of this block

Title
Sensor Platform - Base Board

>> Using ROHM Red PicoLEDs

Size Size Size | Document Number Document Number Document Number Sensor Platform - Base Board Schematic Sensor Platform - Base Board Schematic Sensor Platform - Base Board Schematic | Rev Rev Rev 1.0 1.0 1.0

Friday, August 01, 2014 Friday, August 01, 2014 Friday, August 01, 2014 | 2 2 2 7 7 7

# Ambient Light Sensors

### Sensor Control = 5 = 0b000101

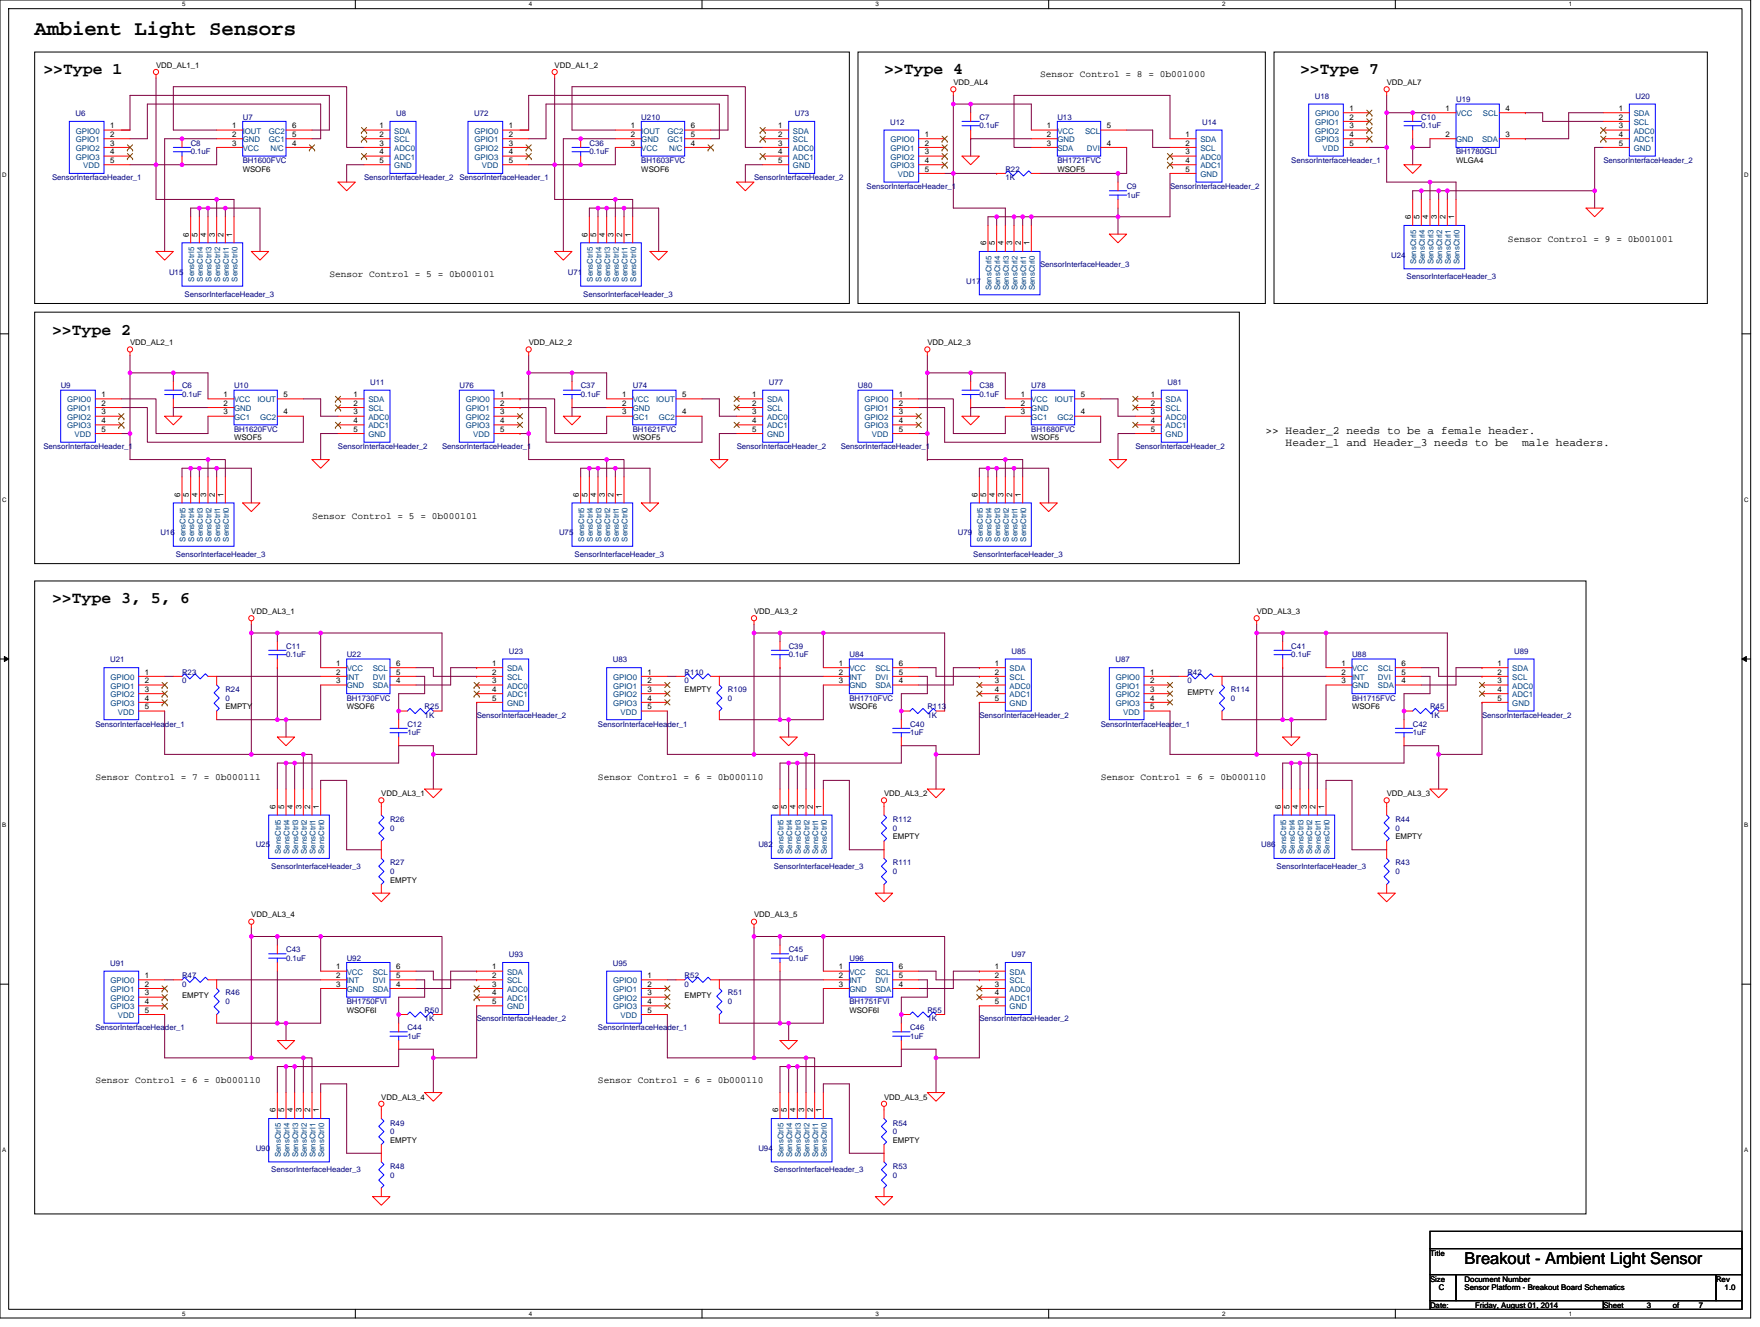
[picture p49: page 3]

>> Header_2 needs to be a female header.
Header_1 and Header_3 needs to be male headers.

Title
Breakout - Ambient Light Sensor

Size C | Document Number Sensor Platform - Breakout Board Schematics | Rev 1.0

Friday, August 01, 2014 Friday, August 01, 2014 Friday, August 01, 2014 | 3 3 3 7 7 7

# Hall Sensors

Sensor Control = 1 = 0b000001 | Sensor Control = 0 = 0b000000

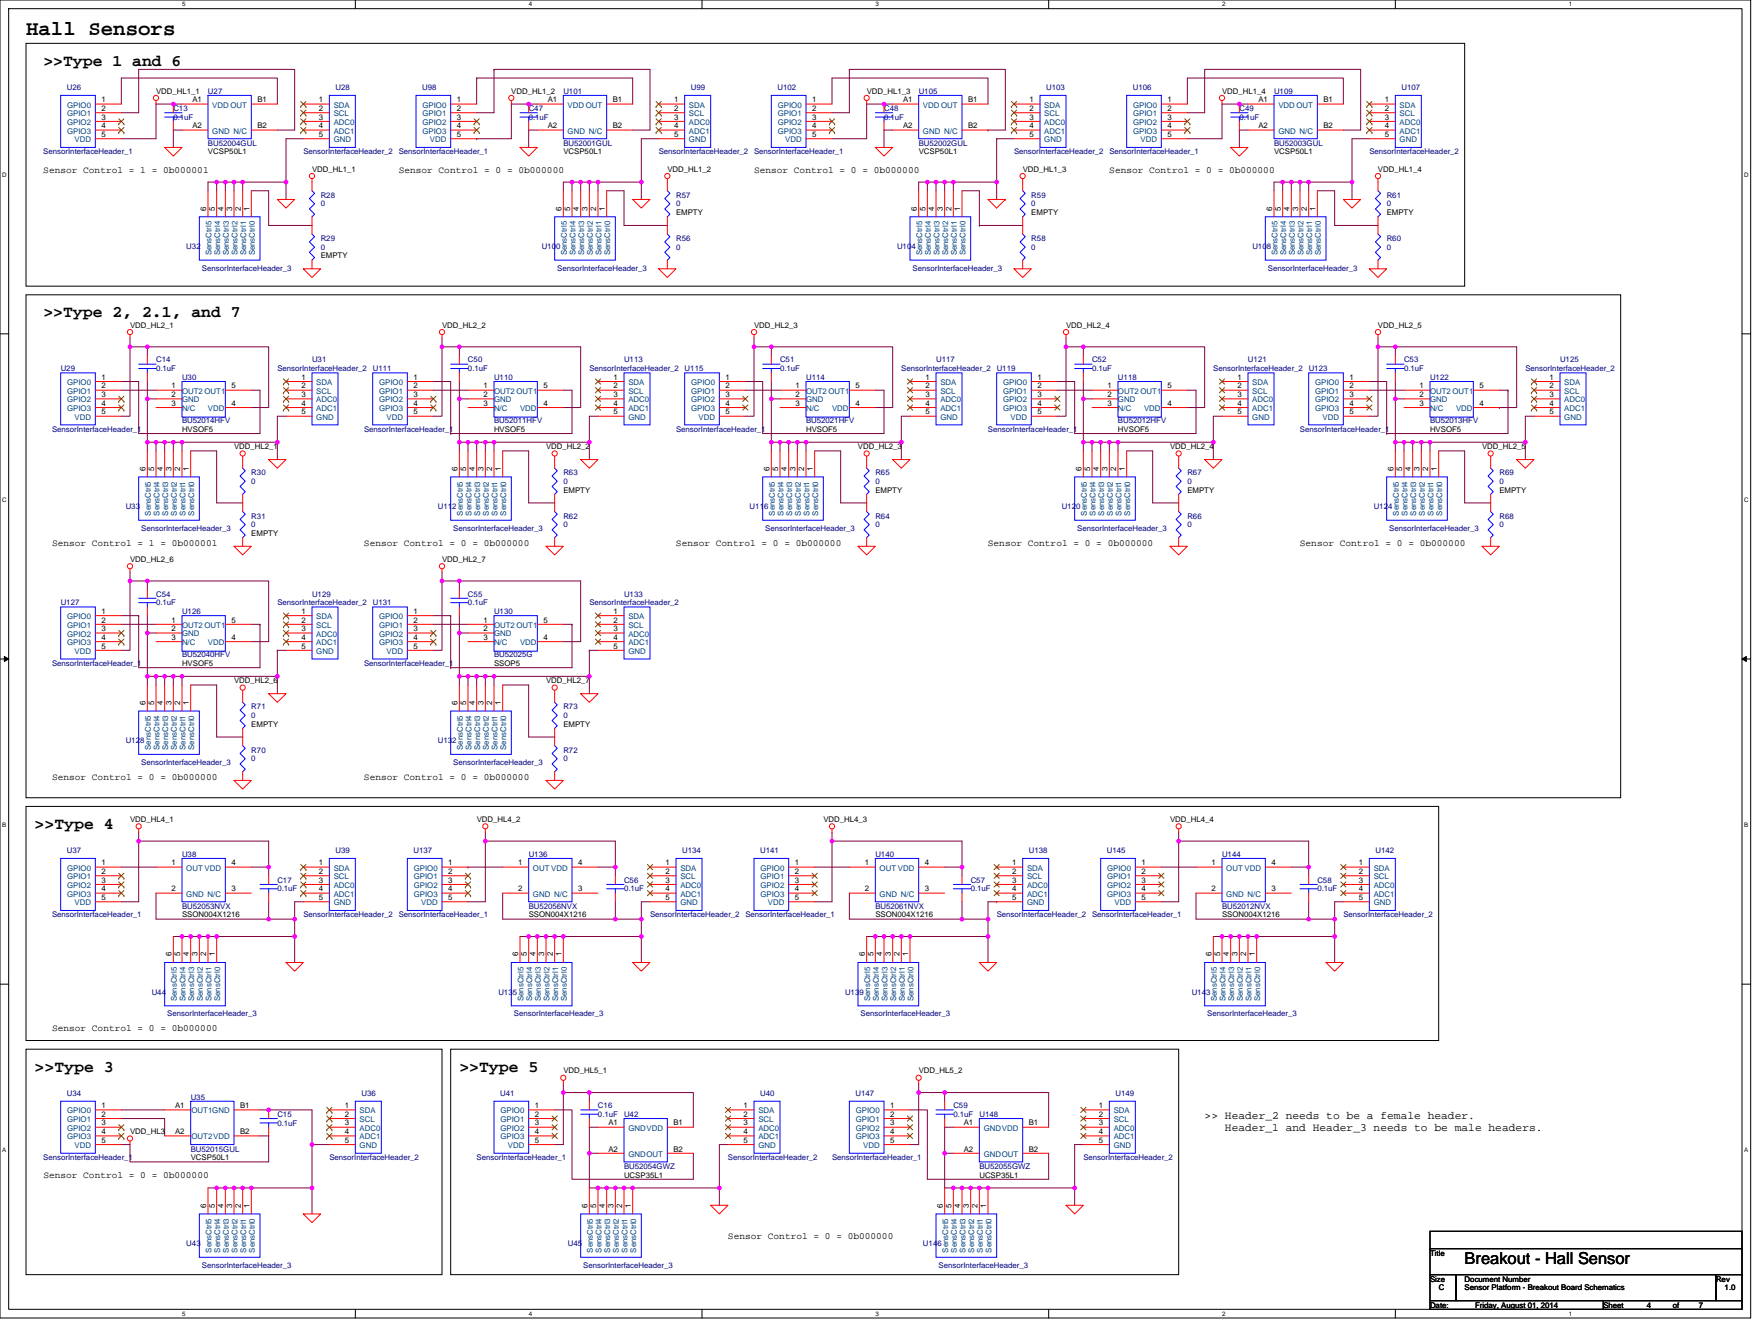
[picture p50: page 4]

>> Header_2 needs to be a female header.
Header_1 and Header_3 needs to be male headers.

# >>Type 3

### Sensor Control = 21 = 0b010101

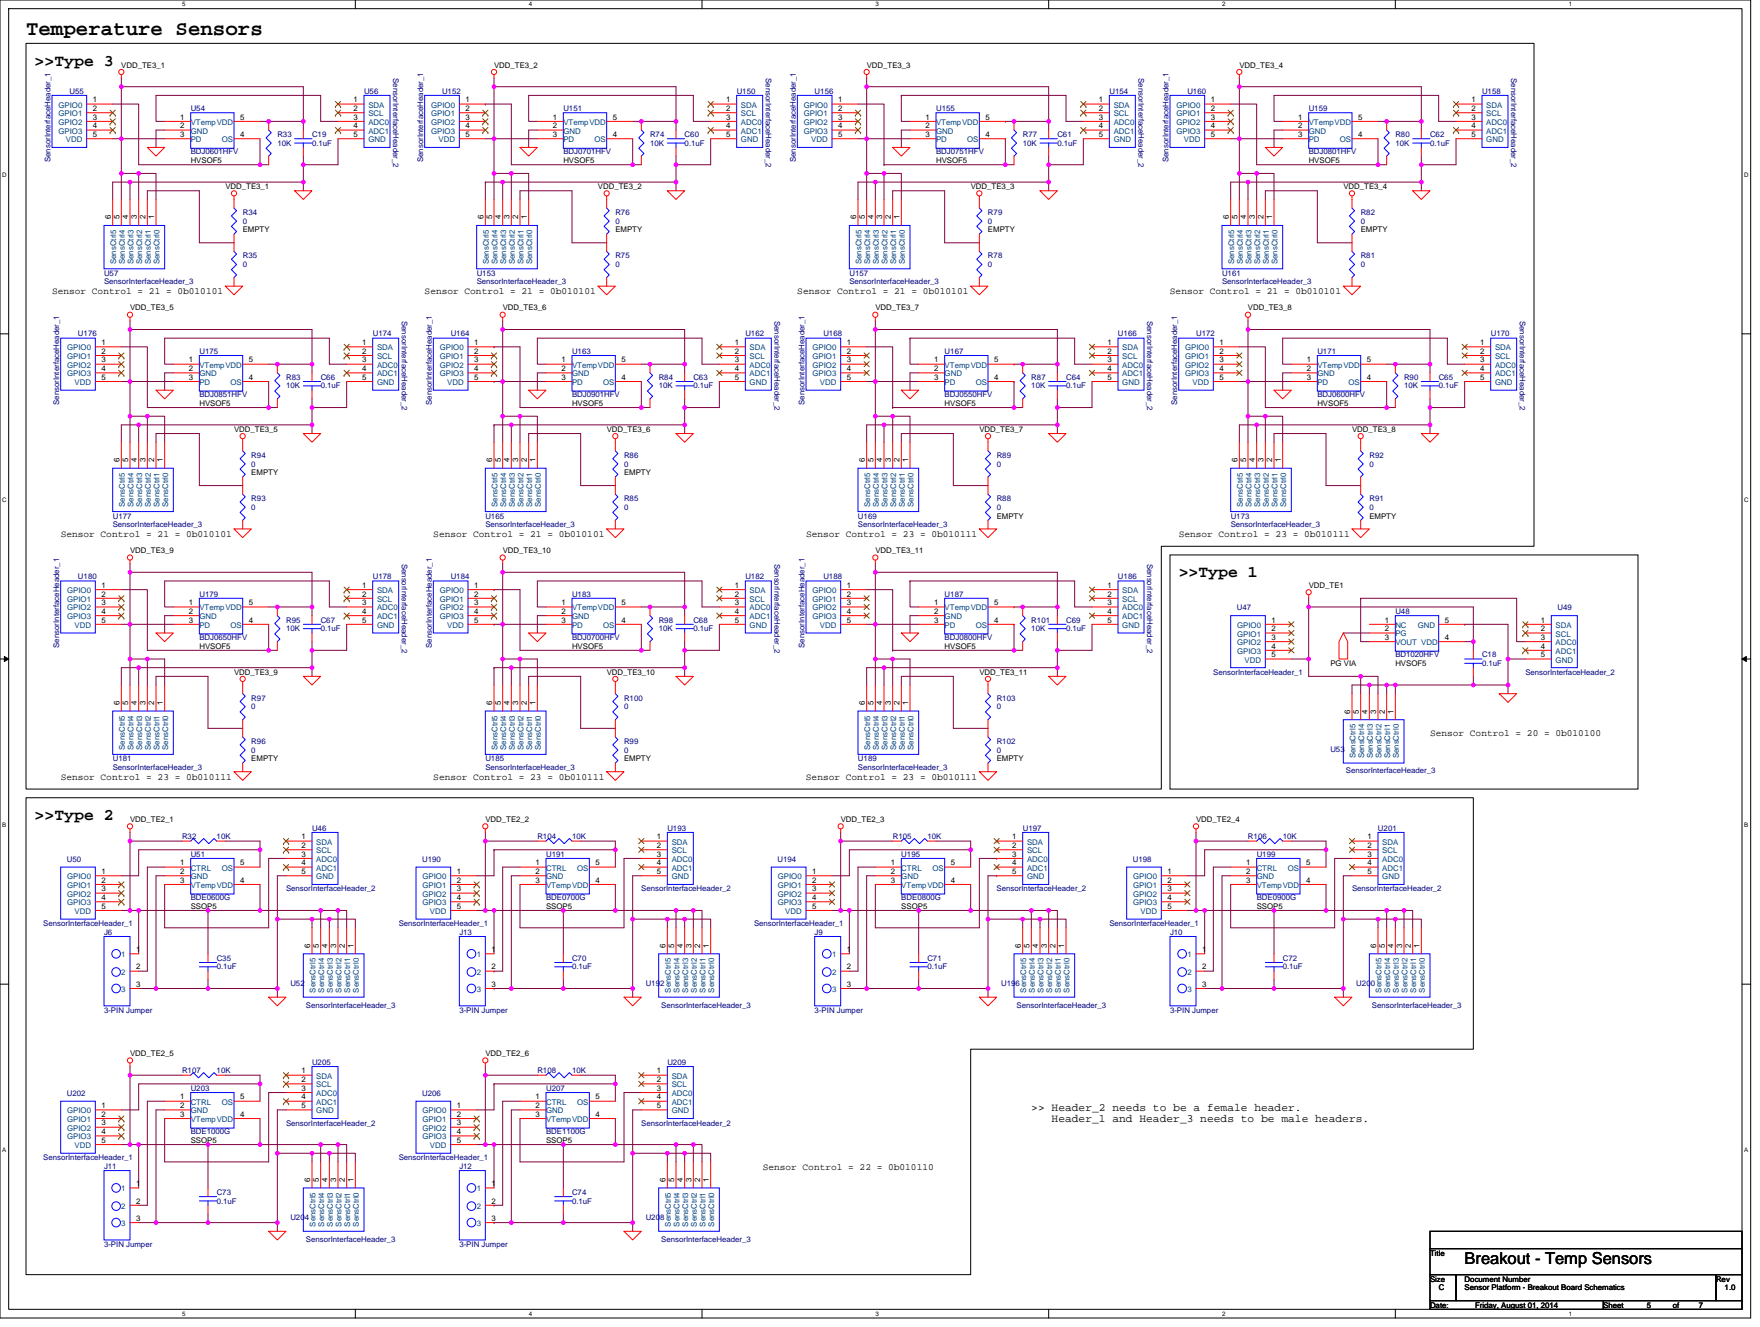
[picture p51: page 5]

>> Header_2 needs to be a female header.
Header_1 and Header_3 needs to be male headers.

D | D

# UV Sensor

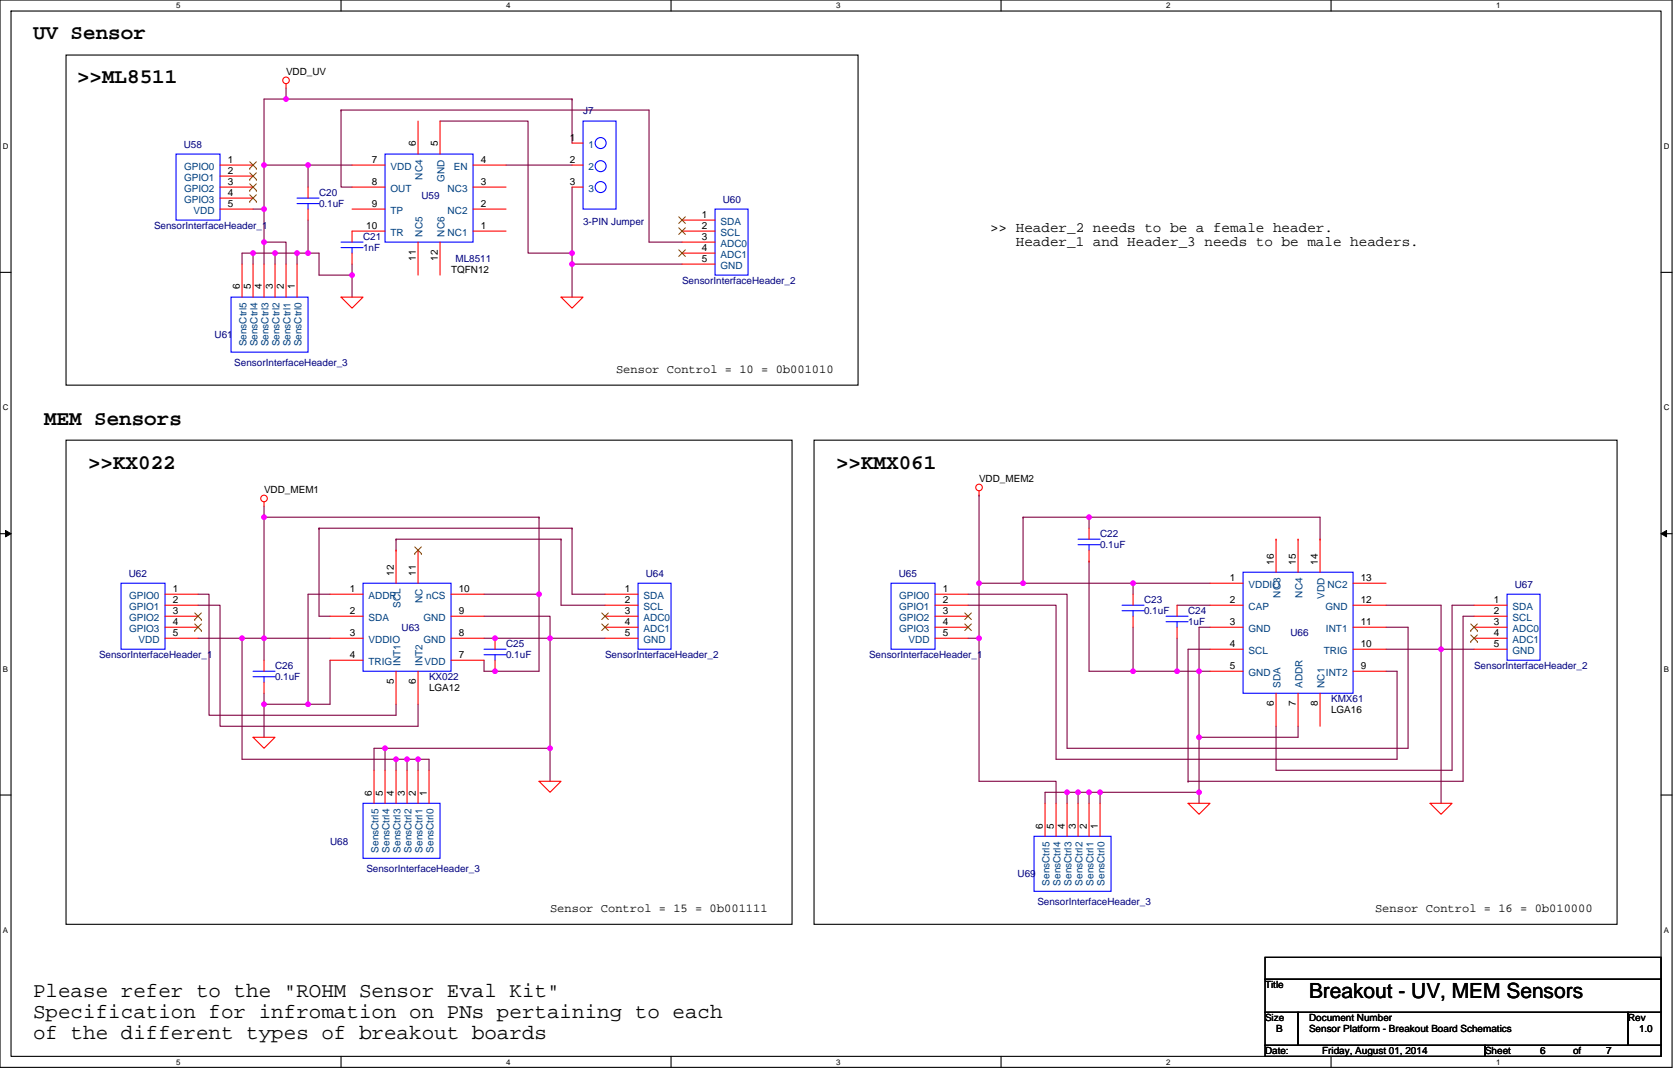
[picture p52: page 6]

>> Header_2 needs to be a female header.
Header_1 and Header_3 needs to be male headers.

Please refer to the "ROHM Sensor Eval Kit"
Specification for infromation on PNs pertaining to each
of the different types of breakout boards

Title
Breakout - UV, MEM Sensors

Size Size Size | Document Number Document Number Document Number | Rev Rev Rev

Friday, August 01, 2014 Friday, August 01, 2014 Friday, August 01, 2014 | 6 6 6 7 7 7

D | D
Near Pin 12 | Near Pin 3

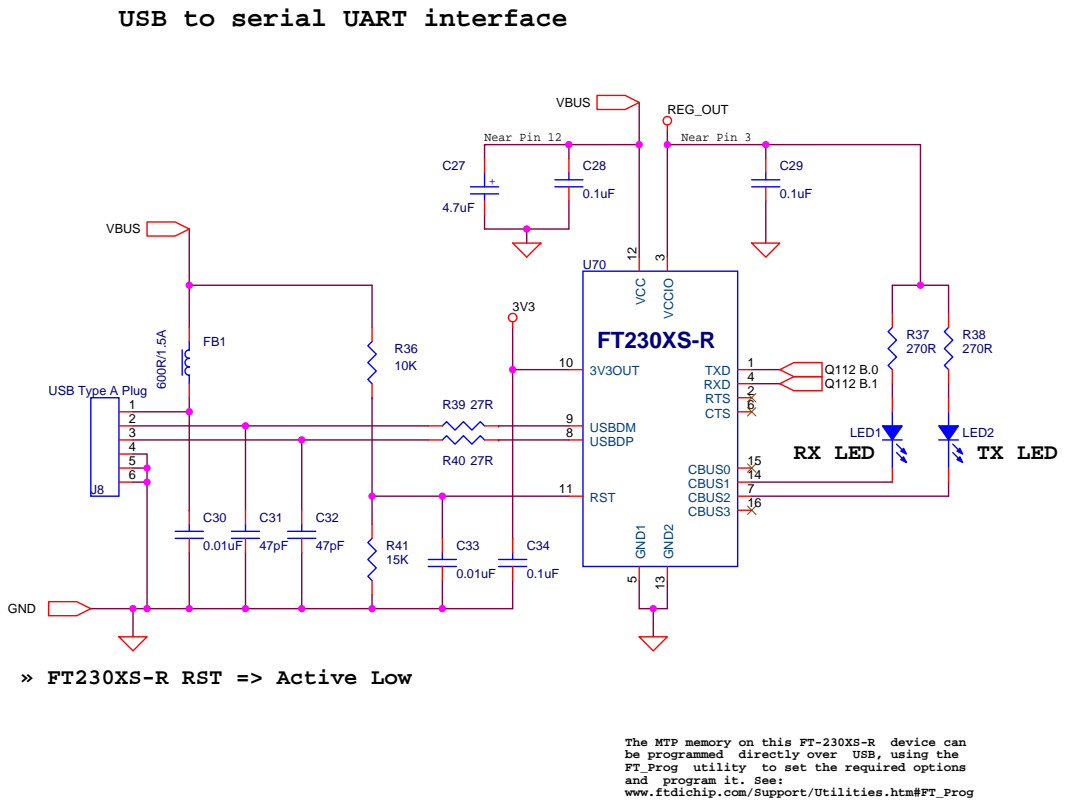
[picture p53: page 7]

USB to serial UART interface

3 | USBDP 8
4 | | RST 11

The MTP memory on this FT-230XS-R device can
be programmed directly over USB, using the
FT_Prog utility to set the required options
and program it. See:
www.ftdichip.com/Support/Utilities.htm#FT_Prog

Title
Sensor Platform - Base Board FTDI IC

Size Size Size | Document Number Document Number Document Number FTDI Portion of Circuit FTDI Portion of Circuit FTDI Portion of Circuit | Rev Rev Rev 1.9 1.9 1.9

Thursday, July 31, 2014 Thursday, July 31, 2014 Thursday, July 31, 2014 | 7 7 7

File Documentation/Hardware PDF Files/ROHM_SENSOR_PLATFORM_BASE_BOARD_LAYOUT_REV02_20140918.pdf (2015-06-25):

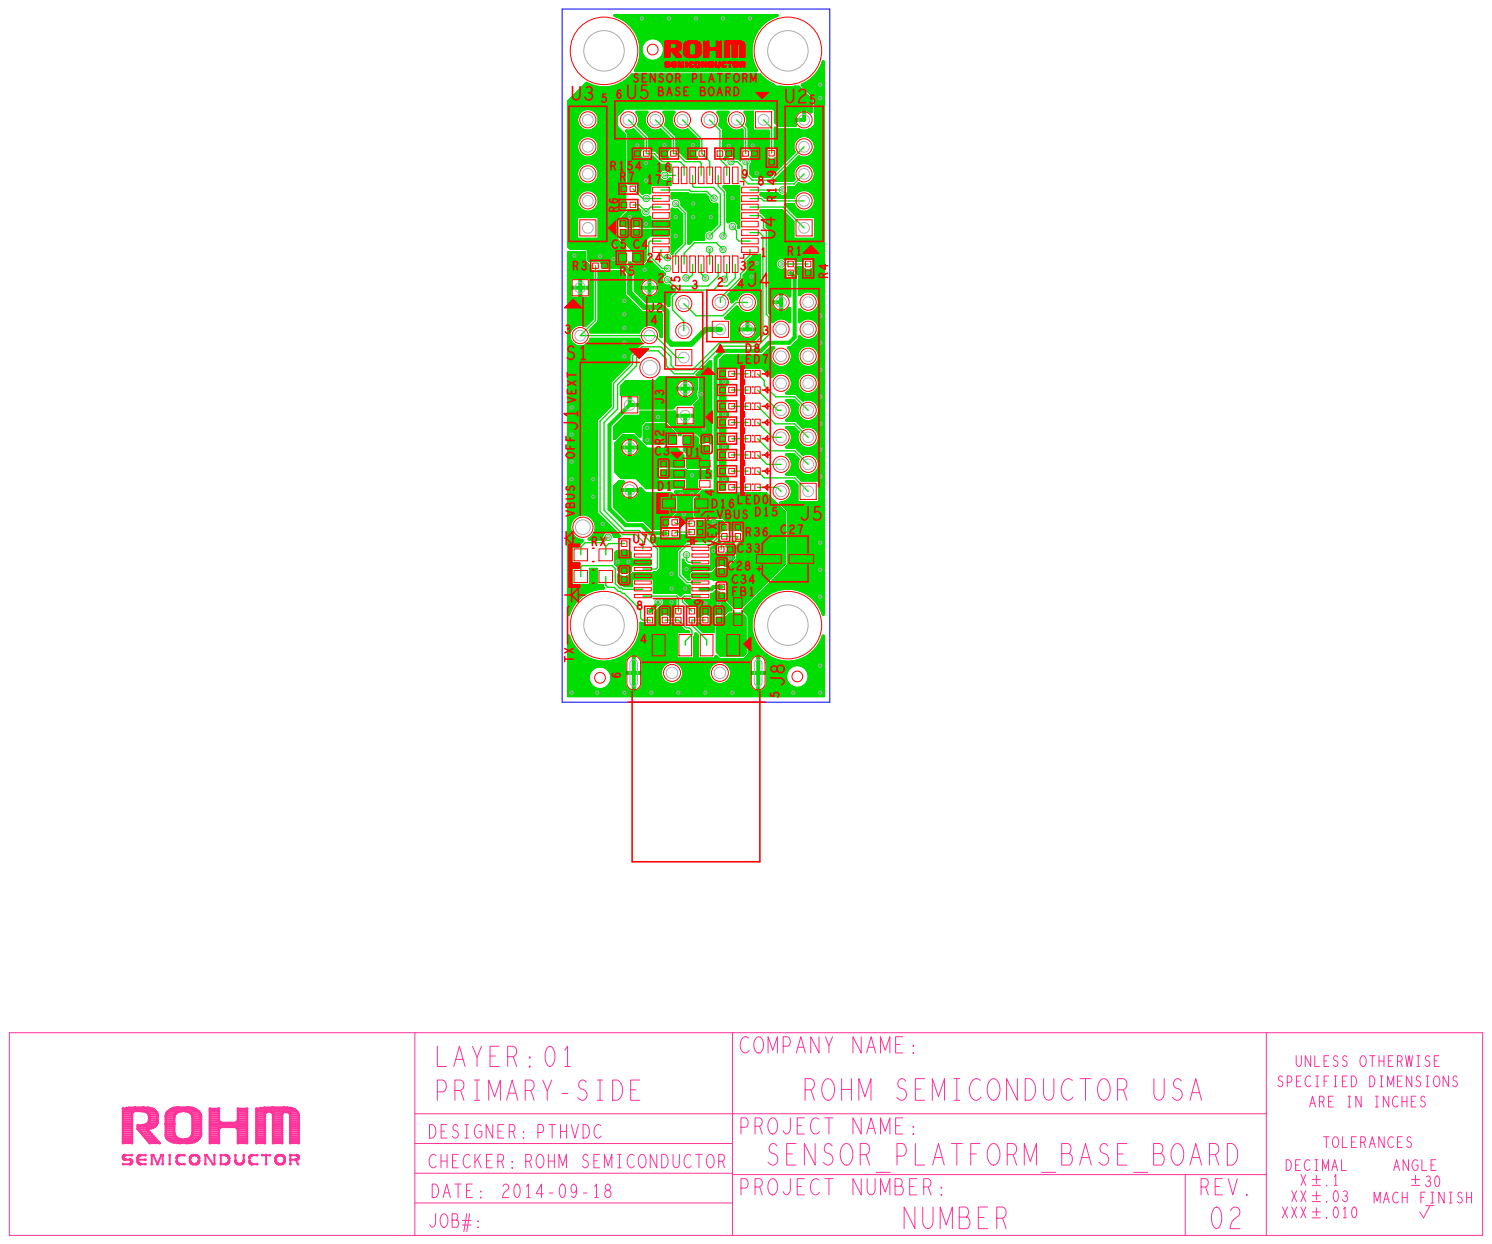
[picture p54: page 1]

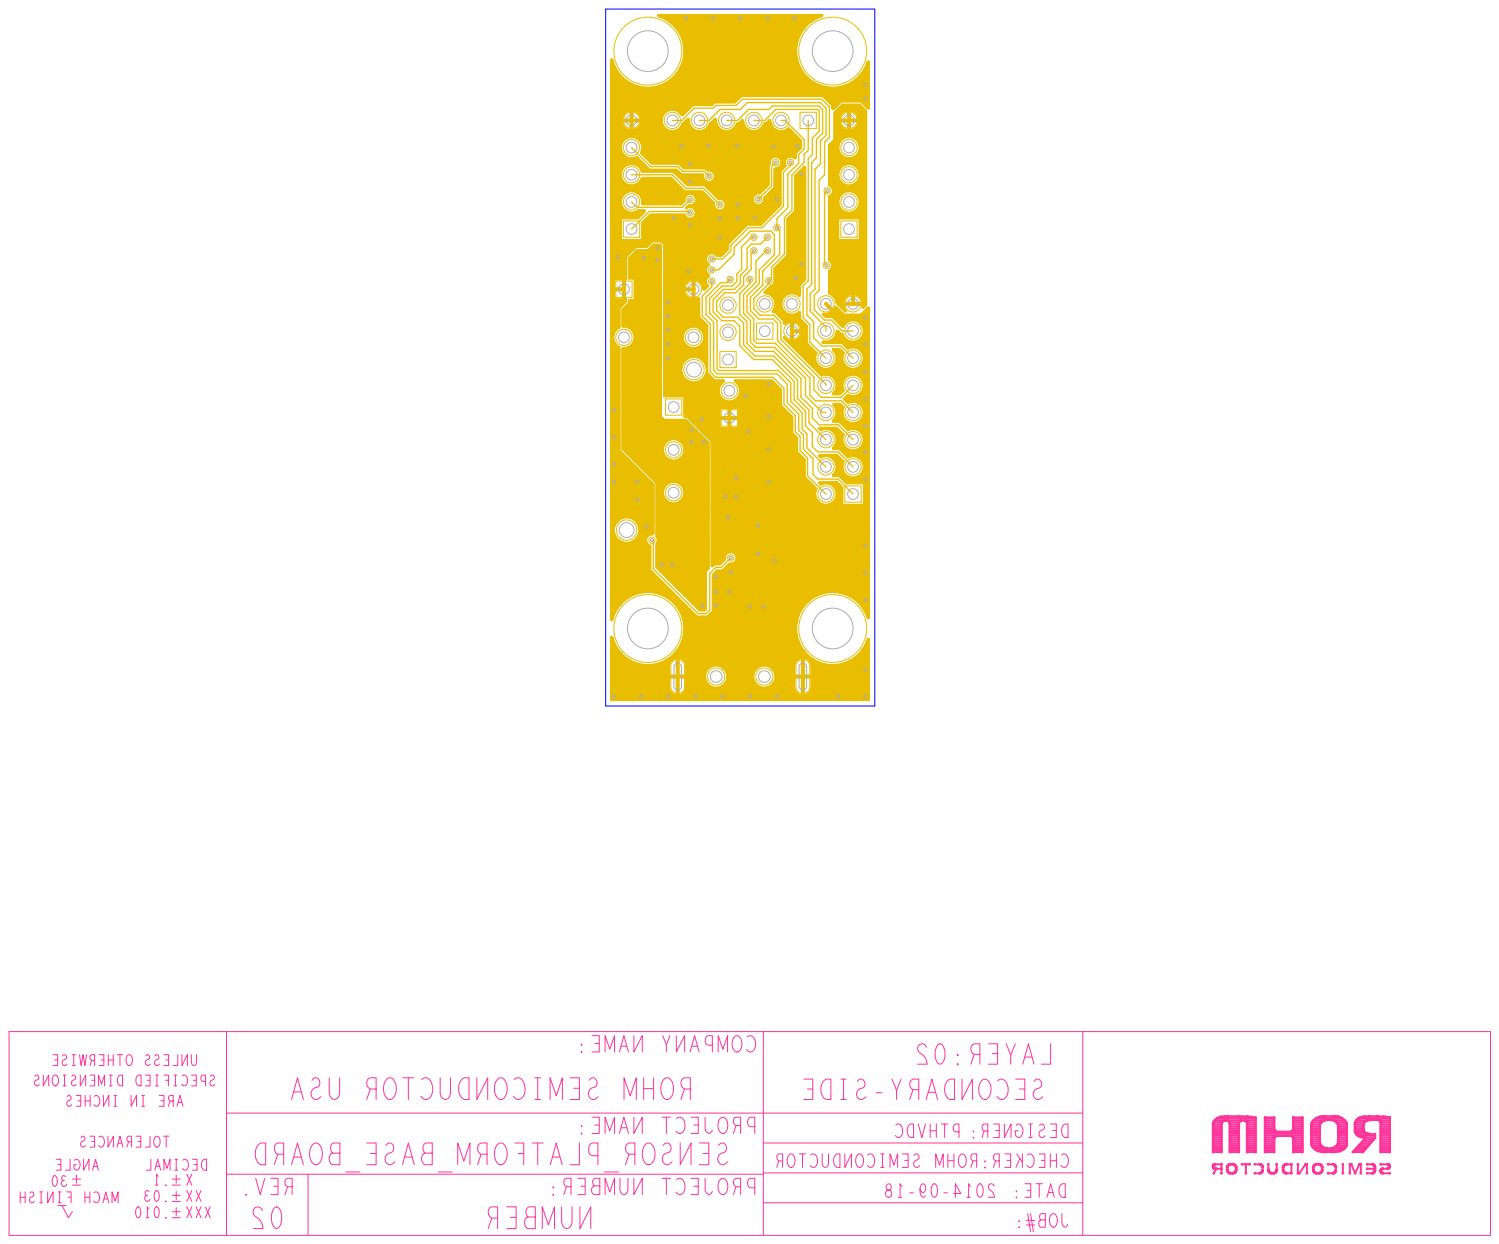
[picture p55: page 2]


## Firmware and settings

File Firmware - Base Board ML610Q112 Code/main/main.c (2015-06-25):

//*****************************************************************************
// Program:	 ROHM Sensor Platform Firmware for Q112 Lapis Microcontroller
//		 ROHM Semiconductor USA, LLC
//		 US Design Center
// Started:  July 8th, 2014
// Purpose:	 Firmware for Q112 for Sensor Platform Board 
// Updated:	 July 8th, 2014
/*
	Copyright (C) 2015 ROHM USDC Applications Engineering Team

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
    You should have received a copy of the GNU General Public License
    along with this program.  If not, see <http://www.gnu.org/licenses/>.
*/
//*****************************************************************************
//#define DebugSensor	16

// ============================= Sensor Platform Board Specs ============================== 
//	UART to USB/PC:
//		UART to FTDI => B0, B1
//		VBus Det => A2
//	Sensor Interface:
//		I2C => B5, B6
//		ADC => A0, A1
//		GPIO => B2, B3, B4, B7
//	LED Feedback Section:
//		LEDs = C0 to C7
//	Sensor Control Section:
//		DIP Switch = D0 to D3

//***** PREPROCESSOR DIRECTIVES ***********************************************
// INCLUDED FILES...
// Include Path: common;main;irq;timer;clock;tbc;pwm;uart;

	#include	<ML610112.H>	// Lapis Micro ML610Q112 on LaPi Development Board
	#include	<stdlib.h>		// General-purpose utilities
	#include 	<uart.h>		// UART Function Prototypes
	#include 	<common.h>		// Common Definitions
	#include 	<irq.h>			// IRQ Definitions
	#include 	<mcu.h>			// MCU Definition
	#include	<i2c.h>			// I2C Definition
	//#include 	<clock.h>		// Set System Clock API
	#include 	<tbc.h>			// Set TBC (Timer Based Clock) API
	#include 	<timer.h>		// Timer Macros & APIs
	//#include 	<main.h>		// Clear WDT API
	//#include	<ctype.h>		// Character classification and conversion 
	//#include	<errno.h>		// Error identifiers Library
	//#include	<float.h>		// Numerical limits for floating-point numbers
	//#include	<limits.h>		// Numerical limits for integers
	//#include	<math.h>		// Mathematical functions
	//#include	<muldivu8.h>	// Multiplication and Division accelerator
	//#include	<setjmp.h>		// Global jump (longjmp)
	//#include	<signal.h>		// Signal handling functions
	//#include	<stdarg.h>		// Variable numbers of arguments
	//#include	<stddef.h>		// Standard types and macros 
	#include	<stdio.h>		// I/O-related processing
	//#include	<string.h>		// Character string manipulation routines
	//#include	<yfuns.h>		// 
	//#include	<yvals.h>		// Called for by most Header Files

//===========================================================================
//   MACROS: 
//===========================================================================
#define WelcomeString	("\033[2J\033[1;1H"\
	"*********************************************\n\r"\
	"** Q112 Firmware - Sensor Platform EVK\n\r"\
	"** Revision    : REV00\n\r"\
	"** Release date: " __DATE__ " " __TIME__ "\n\r"\
	"** By          : ROHM Semiconductor USA, LLC\n\r"\
	"*********************************************\n\r"\
)

#define PRINTF(msg)		write(0, msg, sizeof(msg))

// ===== Peripheral setting.=====
#define HSCLK_KHZ	( 8000u )	// 8MHz = 8000kHz (will be multiplied by 1024 to give 8,192,000Hz)
#define FLG_SET		( 0x01u )

// SET DESIRED UART SETTINGS HERE! (Options in UART.h)
//#define UART_BAUDRATE		( UART_BR_115200BPS) 	// Data Bits Per Second - Tested at rates from 2400bps to 512000bps!
#define UART_BAUDRATE		( UART_BR_9600BPS) 	// Data Bits Per Second - Tested at rates from 2400bps to 512000bps!
#define UART_DATA_LENGTH	( UART_LG_8BIT )		// x-Bit Data
#define UART_PARITY_BIT		( UART_PT_NON )		// Parity
#define UART_STOP_BIT		( UART_STP_1BIT )		// x Stop-Bits
#define UART_LOGIC			( UART_NEG_POS )		// Desired Logic
#define UART_DIRECTION		( UART_DIR_LSB )		// LSB or MSB First
//#define _TBC_H_

/**
 * Sensor Interface Header 1
 */
#define SENINTF_HDR1_GPIO0(reg)		PB2##reg
#define SENINTF_HDR1_GPIO1(reg)		PB3##reg
#define SENINTF_HDR1_GPIO2(reg)		PB4##reg
#define SENINTF_HDR1_GPIO3(reg)		PB7##reg

/**
 * LED[7-0]
 */
#define LEDOUT(x)	PCD=x

//===========================================================================
//   STRUCTURES:    
//===========================================================================
static const tUartSetParam  _uartSetParam = {		// UART Parameters
	UART_BAUDRATE,								// Members of Structure...
	UART_DATA_LENGTH,							// Members of Structure...
	UART_PARITY_BIT,							// Members of Structure...
	UART_STOP_BIT,								// Members of Structure...
	UART_LOGIC,									// Members of Structure...
	UART_DIRECTION								// Members of Structure...
};

//===========================================================================
//   FUNCTION PROTOTYPES: 
//	Establishes the name and return type of a function and may specify the 
// 	types, formal parameter names and number of arguments to the function                                 
//===========================================================================
void main_clrWDT( void );			// no return value and no arguments
void Initialization( void );		// no return value and no arguments
void SetOSC( void );				// no return value and no arguments
void PortA_Low( void );				// no return value and no arguments
void PortB_Low( void );				// no return value and no arguments
void PortC_Low( void );				// no return value and no arguments
void PortD_Low( void );				// no return value and no arguments

//RTLU8: Low-level function
int write(int handle, unsigned char *buffer, unsigned int len);
int ADC_Read(unsigned char idx);
void I2C_Read(unsigned char slave_address, unsigned char *reg_address, unsigned char reg_address_size, unsigned char *buffer, unsigned char size);
void I2C_Write(unsigned char slave_address, unsigned char *reg_address, unsigned char reg_address_size, unsigned char *buffer, unsigned char size);

//UART and I2C Functions
void _funcUartFin( unsigned int size, unsigned char errStat );
void _funcI2CFin( unsigned int size, unsigned char errStat );
void main_reqNotHalt( void );
void _intUart( void );
void _intI2c( void );
void _intADC( void );
void NOPms( unsigned int ms );

unsigned char ReverseBits(unsigned char data);
unsigned char FlashLEDs(void);

void DeviceSelection(void); // Initializes port D for registering Sensor Control States
void SensorInitialization(void); 
  
void MainOp_Hall_Effect_Sensors_2();
void MainOp_Hall_Effect_Sensors_1();
void MainOp_Ambient_Light_Sensor_5();
void MainOp_Ambient_Light_Sensor_6();
void MainOp_Ambient_Light_Sensor_7();
void MainOp_Ambient_Light_Sensor_8();
void MainOp_Ambient_Light_Sensor_9();
void MainOp_UV_Sensor_10();
void MainOp_KX022();
void MainOp_KMX61();
void MainOp_Temperature_Sensor_20();
void MainOp_Temperature_Sensor_21();
void MainOp_Temperature_Sensor_22();
void MainOp_Temperature_Sensor_23();

void Init_Hall_Effect_Sensors_2();
void Init_Hall_Effect_Sensors_1();
void Init_Ambient_Light_Sensor_5();
void Init_Ambient_Light_Sensor_6();
void Init_Ambient_Light_Sensor_7();
void Init_Ambient_Light_Sensor_8();
void Init_Ambient_Light_Sensor_9();
void Init_UV_Sensor_10();
void Init_KX022();
void Init_KMX61();
void Init_Temperature_Sensor_20();
void Init_Temperature_Sensor_21();
void Init_Temperature_Sensor_22();
void Init_Temperature_Sensor_23();

//*****************************************************************************
// GLOBALS...
// ADC, UART and I2C Variables
unsigned char	_flgUartFin;
unsigned char 	_flgI2CFin;
unsigned char	_flgADCFin;
unsigned char	_reqNotHalt;

union {
	unsigned char	_uchar;
	unsigned char	_ucharArr[6];
	unsigned int	_uint;
	unsigned int	_uintArr[3];
	int				_intArr[3];
	float			_float;
} uniRawSensorOut;

float flSensorOut[3];

/**
 * ANSI Escape Code
 */
#define ESC_SOL			"\r"
#define ESC_NEWLINE		"\n\r"
#define ESC_PREVLINE	"\033[F"
#define ESC_ERASE2END	"\033[J"
/**
 * Ambient Light Sensors
 */ 
// I2C device address of: BH1710FVC, BH1721FVC
const unsigned char BH17xxFVC_ADDR_1			= 0x23u;
// I2C device address of: BH1730FVC, BH1780GLI
const unsigned char BH17xxFVC_ADDR_2			= 0x29u;

const unsigned char BH17xxFVC_PWR_DOWN			= 0x00u;
const unsigned char BH17xxFVC_PWR_ON			= 0x01u;
/**
 * BH1710FVC
 */		
// Register addresses of BH1710FVC
const unsigned char BH1710FVC_RESET				= 0x07u;
const unsigned char BH1710FVC_CONT_H_RES_MOD	= 0x10u;
const unsigned char BH1710FVC_CONT_M_RES_MOD	= 0x13u;
const unsigned char BH1710FVC_CONT_L_RES_MOD	= 0x16u;
const unsigned char BH1710FVC_ONET_H_RES_MOD	= 0x20u;
const unsigned char BH1710FVC_ONET_M_RES_MOD	= 0x23u;
const unsigned char BH1710FVC_ONET_L_RES_MOD	= 0x26u;
/**
 * BH1721FVC
 */
// Register addresses of BH1721FVC
const unsigned char BH1721FVC_CONT_A_RES_MOD	= 0x10u;	// or 0x20u
const unsigned char BH1721FVC_CONT_H_RES_MOD	= 0x12u;	// or 0x22u
const unsigned char BH1721FVC_CONT_L_RES_MOD	= 0x13u;	// or 0x16u or 0x23u or 0x26u
/**
 * BH1730FVC
 */
// Register addresses of BH1730FVC
const unsigned char BH1730FVC_REG_CONTROL		= 0x80u;
const unsigned char BH1730FVC_REG_TIMING		= 0x81u;
const unsigned char BH1730FVC_REG_INTERRUPT		= 0x82u;
const unsigned char BH1730FVC_REG_THLLOW		= 0x83u;
const unsigned char BH1730FVC_REG_THLHIGH		= 0x84u;
const unsigned char BH1730FVC_REG_THHLOW		= 0x85u;
const unsigned char BH1730FVC_REG_THHHIGH		= 0x86u;
const unsigned char BH1730FVC_REG_GAIN			= 0x87u;
const unsigned char BH1730FVC_REG_ID			= 0x92u;
const unsigned char BH1730FVC_REG_DATA0LOW		= 0x94u;
const unsigned char BH1730FVC_REG_DATA0HIGH		= 0x95u;
const unsigned char BH1730FVC_REG_DATA1LOW		= 0x96u;
const unsigned char BH1730FVC_REG_DATA1HIGH		= 0x97u;
const unsigned char BH1730FVC_CMD_RESET_INT_OUT	= 0xe1u;
const unsigned char BH1730FVC_CMD_STOP_MIM		= 0xe2u;	// Stop manual integration mode.
const unsigned char BH1730FVC_CMD_START_MIM		= 0xe3u;	// Start manual integration mode.
const unsigned char BH1730FVC_CMD_SW_RESET		= 0xe4u;
/**
 * BH1780GLI
 */
// Register addresses of BH1780GLI
const unsigned char BH1780GLI_REG_CONTROL		= 0x80u;
const unsigned char BH1780GLI_REG_PART_ID		= 0x8au;
const unsigned char BH1780GLI_REG_MFG_ID		= 0x8bu;
const unsigned char BH1780GLI_REG_DATALOW		= 0x8cu;
const unsigned char BH1780GLI_REG_DATAHIGH		= 0x8du;

/**
 * ML8511 (UV Sensor)
 *		Vout 		: 2.2[V] @ 10[mW/cm2]
 *		Sensitivity	: 0.129[Vcm2/mW]
 */
#define	Voltage2UVIntensity(v)	(v-2.2f)/0.129f+10

/**
 * Temperature Sensors
 *		Vout		: v0[V] @ t0[°C]
 *		Sensitivity	: s[V/°C]
 */
#define Voltage2Temperature(v, v0, t0, s)	(v-(v0))/(s)+(t0)

/**
 * KX022 (± 2g/4g/8g Tri-axis Digital Accelerometer)
 */
// I2C device address of KX022
const unsigned char KX022_I2C_ADDR		= 0x1eu;
// Register addresses of KX022
const unsigned char KX022_XHPL			= 0x00u;
const unsigned char KX022_XHPH			= 0x01u;
const unsigned char KX022_YHPL			= 0x02u;
const unsigned char KX022_YHPH			= 0x03u;
const unsigned char KX022_ZHPL			= 0x04u;
const unsigned char KX022_ZHPH			= 0x05u;
const unsigned char KX022_XOUTL			= 0x06u;
const unsigned char KX022_XOUTH			= 0x07u;
const unsigned char KX022_YOUTL			= 0x08u;
const unsigned char KX022_YOUTH			= 0x09u;
const unsigned char KX022_ZOUTL			= 0x0au;
const unsigned char KX022_ZOUTH			= 0x0bu;
const unsigned char KX022_COTR			= 0x0cu;
const unsigned char KX022_WHO_AM_I		= 0x0fu;
const unsigned char KX022_TSCP			= 0x10u;
const unsigned char KX022_TSPP			= 0x11u;
const unsigned char KX022_INS1			= 0x12u;
const unsigned char KX022_INS2			= 0x13u;
const unsigned char KX022_INS3			= 0x14u;
const unsigned char KX022_STAT			= 0x15u;
const unsigned char KX022_INT_REL		= 0x17u;
const unsigned char KX022_CNTL1			= 0x18u;
const unsigned char KX022_CNTL2			= 0x19u;
const unsigned char KX022_CNTL3			= 0x1au;
const unsigned char KX022_ODCNTL		= 0x1bu;
const unsigned char KX022_INC1			= 0x1cu;
const unsigned char KX022_INC2			= 0x1du;
const unsigned char KX022_INC3			= 0x1eu;
const unsigned char KX022_INC4			= 0x1fu;
const unsigned char KX022_INC5			= 0x20u;
const unsigned char KX022_INC6			= 0x21u;
const unsigned char KX022_TILT_TIMER	= 0x22u;
const unsigned char KX022_WUFC			= 0x23u;
const unsigned char KX022_TDTRC			= 0x24u;
const unsigned char KX022_TDTC			= 0x25u;
const unsigned char KX022_TTH			= 0x26u;
const unsigned char KX022_TTL			= 0x27u;
const unsigned char KX022_FTD			= 0x28u;
const unsigned char KX022_STD			= 0x29u;
const unsigned char KX022_TLT			= 0x2au;
const unsigned char KX022_TWS			= 0x2bu;
const unsigned char KX022_ATH			= 0x30u;
const unsigned char KX022_TILT_ANGLE_LL	= 0x32u;
const unsigned char KX022_TILT_ANGLE_HL	= 0x33u;
const unsigned char KX022_HYST_SET		= 0x34u;
const unsigned char KX022_LP_CNTL		= 0x35u;
const unsigned char KX022_BUF_CNTL1		= 0x3au;
const unsigned char KX022_BUF_CNTL2		= 0x3bu;
const unsigned char KX022_BUF_STATUS_1	= 0x3cu;
const unsigned char KX022_BUF_STATUS_2	= 0x3du;
const unsigned char KX022_BUF_CLEAR		= 0x3eu;
const unsigned char KX022_BUF_READ		= 0x3fu;
const unsigned char KX022_SELF_TEST		= 0x60u;
// Configuration data
// Set accelerometer to stand-by mode(PC1=0), +/-2g - 16bits and enable tilt position function
const unsigned char KX022_CNTL1_CFGDAT		= 0x41u;
// Set Output Data Rate(ODR) to 50Hz
const unsigned char KX022_ODCNTL_CFGDAT		= 0x02u;
// Set Tilt Output Data Rate to 50Hz
const unsigned char KX022_CNTL3_CFGDAT		= 0xd8u;
// Set Tilt Timer to 20ms
const unsigned char KX022_TILT_TIMER_CFGDAT	= 0x01u;
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
int main(void) 
{ 	
	Initialization(); //Ports, UART, Timers, Oscillator, Comparators, etc.

	PRINTF(WelcomeString);

#ifdef DebugSensor // Debug Initialization For devices
	SensorIntializationFlag = 1;
	SensorPlatformSelection = DebugSensor;
#endif
	
MainLoop:
	main_clrWDT();
	
#ifndef DebugSensor	//Debug Main Loop For Devices
	DeviceSelection(); 	// SensorPlatformSelection holds 8-bits of sensor type
#endif

	if(SensorIntializationFlag==1){	//Holds the SW Statement for Initializing Sensors
		SensorInitialization();
		SensorIntializationFlag = 0;
	}
	
	switch(SensorPlatformSelection){
		case 1:
			MainOp_Hall_Effect_Sensors_1(); // Refer to function description for list of sensors
			break;
		case 2:
			MainOp_Hall_Effect_Sensors_2(); // Refer to function description for list of sensors 
			break;
		case 5: 
			MainOp_Ambient_Light_Sensor_5(); // Refer to function description for list of sensors
			break;
		case 6:
			MainOp_Ambient_Light_Sensor_6(); // Refer to function description for list of sensors 
			break;
		case 7:
			MainOp_Ambient_Light_Sensor_7(); // Refer to function description for list of sensors 
			break;
		case 8:
			MainOp_Ambient_Light_Sensor_8(); // Refer to function description for list of sensors 
			break;
		case 9:
			MainOp_Ambient_Light_Sensor_9(); // Refer to function description for list of sensors 
			break;
		case 10:
			MainOp_UV_Sensor_10(); // Refer to function description for list of sensors 
			break;
		case 15:
			MainOp_KX022(); // Refer to function description for list of sensors 
			break;
		case 16:
			MainOp_KMX61(); // Refer to function description for list of sensors 
			break;
		case 20:
			MainOp_Temperature_Sensor_20(); // Refer to function description for list of sensors 
			break;
		case 21:
			MainOp_Temperature_Sensor_21(); // Refer to function description for list of sensors
			break;
		case 22:
			MainOp_Temperature_Sensor_22(); // Refer to function description for list of sensors 
			break;
		case 23:
			MainOp_Temperature_Sensor_23(); // Refer to function description for list of sensors
			break; 
		default:
			PRINTF(ESC_ERASE2END "No device connected." ESC_SOL);
			FlashLEDs();
			break;
	}
	
	HLT = 1;	//Wait time here depends on the WDT timing
	__asm("nop\n"); 
	__asm("nop\n");
	
	goto MainLoop;
}
//===========================================================================
//  	End of MAIN FUNCTION
//===========================================================================


//===========================================================================
//  	Start of Other Functions...
//===========================================================================
//==========================================================================
//	Initialize Micro to Desired State...
//===========================================================================
static void Initialization(void){

	//Initialize Peripherals	
	//BLKCON2 Control Bits...Manually Set 4/12/2013
	DSIO0 = 1; // 0=> Enables Synchronous Serial Port 0 (initial value).
	DUA0  = 0; // 0=> Enables the operation of UART0 (initial value).
	DUA1  = 1; // 0=> Enables Uart1 (initial value). 
	DI2C1 = 1; // 0=> Enables I2C bus Interface (Slave) (initial value).
	DI2C0 = 0; // 0=> Enables I2C bus Interface (Master) (initial value).	
	
	BLKCON4 = 0x00; // 0=> Enables SA-ADC
	BLKCON6 = 0x00; // (1=disables; 0=enables) the operation of Timers 8, 9, A, E, F.
	BLKCON7 = 0x0F; // (1=disables; 0=enables) the operation of PWM (PWMC, PWMD, PWME, PWMF

	// Port Initialize
	PortA_Low();	//Initialize all 3 Ports of Port A to GPIO-Low
	PortB_Low();	//Initialize all 8 Ports of Port B to GPIO-Low
	PortC_Low();	//Initialize all 8 Ports of Port C to GPIO-Low
	PortD_Low();	//Initialize all 6 Ports of Port D to input GPIO
	
	// Set Oscillator Rate
    SetOSC();
	
	// Settings for the ADC input (A0, A1)
	PA0DIR = 1;
	PA1DIR = 1;		//GPIO Input
	SACH0 = 1;		//This enables the ADC Channel 0 from A0 Pin
	SACH1 = 1;		//This enables the ADC Channel 1 from A1 Pin
	SALP = 0;		//Single Read or Continuous Read... Single = 0, Consecutive = 1
	
	// IIIIIIIIIIIIIIIIIIIIIIIIIIIIIIIIIIIIIIIIIIIIIIIIIIIIIIIII
	// INTERRUPT SETUP...
	irq_di();	// Disable Interrupts
	irq_init();	// Initialize Interrupts (All Off and NO Requests)

	// INTERRUPT ENABLE REGISTERS...
	IE0 = IE1 = IE2 = IE3 = IE4 = IE5 = IE6 = IE7 = 0;
	// INTERRUPT REQUEST REGISTERS...
	IRQ0 = IRQ1 = IRQ2 = IRQ3 = IRQ4 = IRQ5 = IRQ6 = IRQ7 = 0;

	E2H = 0;	// E2H is the Enable flag for 2Hz TBC Interrupt (1=ENABLED)
				
	irq_setHdr((unsigned char)IRQ_NO_UA0INT, _intUart);
	EUA0 = 1; 	// EUA0 is the enable flag for the UART0 interrupt (1=ENABLED)
	
	irq_setHdr((unsigned char)IRQ_NO_I2CMINT, _intI2c);
	EI2CM = 1;
	QI2CM = 0;
	
	//Enable ADC Interrupts Handler
	irq_setHdr((unsigned char)IRQ_NO_SADINT, _intADC);
	ESAD = 1;
	QSAD = 0;
	
	/*
	//Set up xHz TBC Interrupt (Options: 128Hz, 32Hz, 16Hz, 2Hz)
	//(void)irq_setHdr( (unsigned char)IRQ_NO_T2HINT, TBC_ISR );  //Clear interrupt request flag
	
	// TBC...Set Ratio: : 1:1 => 1_1
	(void)tb_setHtbdiv( (unsigned char)TB_HTD_1_1 ); //Set the ratio of dividing frequency of the time base counter
		E2H = 0;	  // Enable x Hz TBC Interrupt (1=ENABLED)
		Q2H = 0;	  // Request flag for the time base counter x Hz interrupt	
	*/
	
	irq_ei(); // Enable Interrupts
	// IIIIIIIIIIIIIIIIIIIIIIIIIIIIIIIIIIIIIIIIIIIIIIIIIIIIIIIII

	// WDT... This will be the triggering condition to return from halt mode
	// We will need to calibrate based on the timing of our loop
	// 0x00 = 125ms
	// 0x01 = 500ms
	// 0x02 = 2sec
	// 0x03 = 8sec
	// 0x04 = 23.4ms
	// 0x05 = 31.25ms
	// 0x06	= 62.5ms
	WDTMOD = 0x01; 	
	main_clrWDT(); 	// Clear WDT
	
	//I2C Initialization...
	//P20C0 = 1;	/* CMOS output */
	//P20C1 = 1;	
	//P20D = 1;		/* write protect enable */
	i2c_init(I2C_MOD_FST, (unsigned short)HSCLK_KHZ, I2C_SYN_OFF);
	
	//UART Initialization...
	uart_init((unsigned char)UART_CS_HSCLK,		/* Generator       */
			  (unsigned short)HSCLK_KHZ,		/* HSCLK frequency */
			   &_uartSetParam );				/* Param... 	 */
	uart_PortSet();
	
	//Write "Program Start" UART Control
	
}//End Initialization
//===========================================================================

/*******************************************************************************
	Routine Name	: write
	Form			: int write(int handle, unsigned char *buffer, unsigned int len)
	Parameters		: int handle
					  unsigned char *buffer
					  unsigned int len
	Return value	: int
	Initialization	: None.
	Description		: The write function writes len bytes of data from the area specified by buffer to UART0.
******************************************************************************/
int write(int handle, unsigned char *buffer, unsigned int len)
{
	_flgUartFin = 0; 
	uart_stop();
	uart_startSend(buffer, len, _funcUartFin); 
	while(_flgUartFin != 1)
	{
		main_clrWDT();
	}
	return len;
}

/*******************************************************************************
	Routine Name	: ADC_Read
	Form			: int ADC_Read()
	Parameters		: unsigned char idx
	Return value	: int
	Initialization	: None.
	Description		: Read ADC(idx) value
******************************************************************************/
int ADC_Read(unsigned char idx)
{
	_flgADCFin = 0;
	SADMOD0 = (unsigned char)(1<<idx);
	SARUN = 1;
	while(_flgADCFin == 0)
	{
		main_clrWDT();
	}
	switch(idx)
	{
		case 0:		return (SADR0H<<2|SADR0L>>6);
		case 1:		return (SADR1H<<2|SADR1L>>6);
		case 2:		return (SADR2H<<2|SADR2L>>6);
		case 3:		return (SADR3H<<2|SADR3L>>6);
		case 4:		return (SADR4H<<2|SADR4L>>6);
		case 5:		return (SADR5H<<2|SADR5L>>6);
		case 6:		return (SADR6H<<2|SADR6L>>6);
		case 7:		return (SADR7H<<2|SADR7L>>6);
		default:	return 0;
	}
}

/*******************************************************************************
	Routine Name	: I2C_Read
	Form			: void I2C_Read(unsigned char slave_address, unsigned char *address, unsigned char address_size, unsigned char *buffer, unsigned char size)
	Parameters		: unsigned char slave_address
					  unsigned char *address
					  unsigned char address_size
					  unsigned char *buffer
					  unsigned char size
	Return value	: void
	Initialization	: None.
	Description		: 
******************************************************************************/
void I2C_Read(unsigned char slave_address, unsigned char *reg_address, unsigned char reg_address_size, unsigned char *buffer, unsigned char size)
{
	_flgI2CFin = 0;
	i2c_stop();	
	i2c_startReceive(slave_address, reg_address, reg_address_size, buffer, size, (cbfI2c)_funcI2CFin);
	while(_flgI2CFin != 1)
	{
		main_clrWDT();
	}
}
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

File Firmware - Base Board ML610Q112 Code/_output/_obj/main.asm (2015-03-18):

;; Compile Options : /TML610112 /MS /near /Icommon /Imain /Iirq /Itimer /Iclock /Itbc /Iuart /Ii2c /SS 256 /SD /Oa /Ot /W 3 /Wc /Fa_output\_obj\ 
;; Version Number  : Ver.3.41.8
;; File Name       : main.c

	type (ML610112) 
	model small, near
	$$NVARmain segment data 2h #0h
	$$NINITVAR segment data 2h #0h
	$$NINITTAB segment table 2h any
	$$NTABmain segment table 2h #0h
	$$ADC_Read$main segment code 2h #0h
	$$DeviceSelection$main segment code 2h #0h
	$$FlashLEDs$main segment code 2h #0h
	$$I2C_Read$main segment code 2h #0h
	$$I2C_Write$main segment code 2h #0h
	$$Init_Ambient_Light_Sensor_5$main segment code 2h #0h
	$$Init_Ambient_Light_Sensor_6$main segment code 2h #0h
	$$Init_Ambient_Light_Sensor_7$main segment code 2h #0h
	$$Init_Ambient_Light_Sensor_8$main segment code 2h #0h
	$$Init_Ambient_Light_Sensor_9$main segment code 2h #0h
	$$Init_Hall_Effect_Sensors_1$main segment code 2h #0h
	$$Init_Hall_Effect_Sensors_2$main segment code 2h #0h
	$$Init_KMX61$main segment code 2h #0h
	$$Init_KX022$main segment code 2h #0h
	$$Init_Temperature_Sensor_20$main segment code 2h #0h
	$$Init_Temperature_Sensor_21$main segment code 2h #0h
	$$Init_Temperature_Sensor_22$main segment code 2h #0h
	$$Init_Temperature_Sensor_23$main segment code 2h #0h
	$$Init_UV_Sensor_10$main segment code 2h #0h
	$$Initialization$main segment code 2h #0h
	$$MainOp_Ambient_Light_Sensor_5$main segment code 2h #0h
	$$MainOp_Ambient_Light_Sensor_6$main segment code 2h #0h
	$$MainOp_Ambient_Light_Sensor_7$main segment code 2h #0h
	$$MainOp_Ambient_Light_Sensor_8$main segment code 2h #0h
	$$MainOp_Ambient_Light_Sensor_9$main segment code 2h #0h
	$$MainOp_Hall_Effect_Sensors_1$main segment code 2h #0h
	$$MainOp_Hall_Effect_Sensors_2$main segment code 2h #0h
	$$MainOp_KMX61$main segment code 2h #0h
	$$MainOp_KX022$main segment code 2h #0h
	$$MainOp_Temperature_Sensor_20$main segment code 2h #0h
	$$MainOp_Temperature_Sensor_21$main segment code 2h #0h
	$$MainOp_Temperature_Sensor_22$main segment code 2h #0h
	$$MainOp_Temperature_Sensor_23$main segment code 2h #0h
	$$MainOp_UV_Sensor_10$main segment code 2h #0h
	$$NOPms$main segment code 2h #0h
	$$PortA_Low$main segment code 2h #0h
	$$PortB_Low$main segment code 2h #0h
	$$PortC_Low$main segment code 2h #0h
	$$PortD_Low$main segment code 2h #0h
	$$ReverseBits$main segment code 2h #0h
	$$SensorInitialization$main segment code 2h #0h
	$$SetOSC$main segment code 2h #0h
	$$TAB$$S123$main segment table 2h #0h
	$$TAB$$S132$main segment table 2h #0h
	$$TAB$$S141$main segment table 2h #0h
	$$TAB$$S143$main segment table 2h #0h
	$$TAB$$S147$main segment table 2h #0h
	$$TAB$$S149$main segment table 2h #0h
	$$TAB$$S160$main segment table 2h #0h
	$$TAB$$S162$main segment table 2h #0h
	$$TAB$$S176$main segment table 2h #0h
	$$TAB$$S178$main segment table 2h #0h
	$$TAB$$S180$main segment table 2h #0h
	$$TAB$$S182$main segment table 2h #0h
	$$TAB$$S184$main segment table 2h #0h
	$$TAB$$S197$main segment table 2h #0h
	$$TAB$$S247$main segment table 2h #0h
	$$TAB$$S249$main segment table 2h #0h
	$$TAB$$S251$main segment table 2h #0h
	$$TAB$$S254$main segment table 2h #0h
	$$TAB$$S256$main segment table 2h #0h
	$$TAB$$S258$main segment table 2h #0h
	$$TAB$$S261$main segment table 2h #0h
	$$TAB$$S263$main segment table 2h #0h
	$$TAB$$S265$main segment table 2h #0h
	$$TAB$$S268$main segment table 2h #0h
	$$TAB$$S270$main segment table 2h #0h
	$$TAB$$S30$main segment table 2h #0h
	$$TAB$$S53$main segment table 2h #0h
	$$TABBH1710FVC_CONT_H_RES_MOD$main segment table 2h #0h
	$$TABBH1710FVC_CONT_L_RES_MOD$main segment table 2h #0h
	$$TABBH1710FVC_CONT_M_RES_MOD$main segment table 2h #0h
	$$TABBH1710FVC_ONET_H_RES_MOD$main segment table 2h #0h
	$$TABBH1710FVC_ONET_L_RES_MOD$main segment table 2h #0h
	$$TABBH1710FVC_ONET_M_RES_MOD$main segment table 2h #0h
	$$TABBH1710FVC_RESET$main segment table 2h #0h
	$$TABBH1721FVC_CONT_A_RES_MOD$main segment table 2h #0h
	$$TABBH1721FVC_CONT_H_RES_MOD$main segment table 2h #0h
	$$TABBH1721FVC_CONT_L_RES_MOD$main segment table 2h #0h
	$$TABBH1730FVC_CMD_RESET_INT_OUT$main segment table 2h #0h
	$$TABBH1730FVC_CMD_START_MIM$main segment table 2h #0h
	$$TABBH1730FVC_CMD_STOP_MIM$main segment table 2h #0h
	$$TABBH1730FVC_CMD_SW_RESET$main segment table 2h #0h
	$$TABBH1730FVC_REG_CONTROL$main segment table 2h #0h
	$$TABBH1730FVC_REG_DATA0HIGH$main segment table 2h #0h
	$$TABBH1730FVC_REG_DATA0LOW$main segment table 2h #0h
	$$TABBH1730FVC_REG_DATA1HIGH$main segment table 2h #0h
	$$TABBH1730FVC_REG_DATA1LOW$main segment table 2h #0h
	$$TABBH1730FVC_REG_GAIN$main segment table 2h #0h
	$$TABBH1730FVC_REG_ID$main segment table 2h #0h
	$$TABBH1730FVC_REG_INTERRUPT$main segment table 2h #0h
	$$TABBH1730FVC_REG_THHHIGH$main segment table 2h #0h
	$$TABBH1730FVC_REG_THHLOW$main segment table 2h #0h
	$$TABBH1730FVC_REG_THLHIGH$main segment table 2h #0h
	$$TABBH1730FVC_REG_THLLOW$main segment table 2h #0h
	$$TABBH1730FVC_REG_TIMING$main segment table 2h #0h
	$$TABBH1780GLI_REG_CONTROL$main segment table 2h #0h
	$$TABBH1780GLI_REG_DATAHIGH$main segment table 2h #0h
	$$TABBH1780GLI_REG_DATALOW$main segment table 2h #0h
	$$TABBH1780GLI_REG_MFG_ID$main segment table 2h #0h
	$$TABBH1780GLI_REG_PART_ID$main segment table 2h #0h
	$$TABBH17xxFVC_ADDR_1$main segment table 2h #0h
	$$TABBH17xxFVC_ADDR_2$main segment table 2h #0h
	$$TABBH17xxFVC_PWR_DOWN$main segment table 2h #0h
	$$TABBH17xxFVC_PWR_ON$main segment table 2h #0h
	$$TABKMX61_ACCEL_XOUT_H$main segment table 2h #0h
	$$TABKMX61_ACCEL_XOUT_L$main segment table 2h #0h
	$$TABKMX61_ACCEL_YOUT_H$main segment table 2h #0h
	$$TABKMX61_ACCEL_YOUT_L$main segment table 2h #0h
	$$TABKMX61_ACCEL_ZOUT_H$main segment table 2h #0h
	$$TABKMX61_ACCEL_ZOUT_L$main segment table 2h #0h
	$$TABKMX61_BTH$main segment table 2h #0h
	$$TABKMX61_BTSC$main segment table 2h #0h
	$$TABKMX61_BUF_CLEAR$main segment table 2h #0h
	$$TABKMX61_BUF_CTRL1$main segment table 2h #0h
	$$TABKMX61_BUF_CTRL1_CFGDAT$main segment table 2h #0h
	$$TABKMX61_BUF_CTRL2$main segment table 2h #0h
	$$TABKMX61_BUF_CTRL2_CFGDAT$main segment table 2h #0h
	$$TABKMX61_BUF_READ$main segment table 2h #0h
	$$TABKMX61_BUF_STATUS_H$main segment table 2h #0h
	$$TABKMX61_BUF_STATUS_L$main segment table 2h #0h
	$$TABKMX61_BUF_STATUS_REG$main segment table 2h #0h
	$$TABKMX61_BUF_THRESH_H$main segment table 2h #0h
	$$TABKMX61_BUF_THRESH_L$main segment table 2h #0h
	$$TABKMX61_CNTL1$main segment table 2h #0h
	$$TABKMX61_CNTL1_CFGDAT$main segment table 2h #0h
	$$TABKMX61_CNTL2$main segment table 2h #0h
	$$TABKMX61_CNTL2_CFGDAT$main segment table 2h #0h
	$$TABKMX61_COTR$main segment table 2h #0h
	$$TABKMX61_I2C_ADDR$main segment table 2h #0h
	$$TABKMX61_INC1$main segment table 2h #0h
	$$TABKMX61_INC2$main segment table 2h #0h
	$$TABKMX61_INC3$main segment table 2h #0h
	$$TABKMX61_INL$main segment table 2h #0h
	$$TABKMX61_INS1$main segment table 2h #0h
	$$TABKMX61_INS2$main segment table 2h #0h
	$$TABKMX61_MAG_XOUT_H$main segment table 2h #0h
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

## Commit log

2014-07-08 First Commit
    Getting the Structure of the Folder into place. Please note, that no
    changes have been made to the software yet... this is based on the UV
    Sensor Demo Board
2014-08-01 Skeleton Code Commit
    Selection routine with KMX61.
    Still needs to configure all other devices.
2014-08-02 Quality of Life Changes
    Fixed Readme. Also Added Specification and Schematics to the
    "Documentation" folder
2014-08-06 Added code for UV Sensor (ADC Control)
    Added ADC usage to this code (initialization and UV sensor loops)
2014-08-18 Added code for Hall Sensors
    Added code for Hall Sensors:
    - Sensor Control 1 (for BU52004GUL)
    - Sensor Control 2 (for BU52011HFV)
2014-08-21 Added code for Ambient Light Sensors
    Added code for Ambient Light Sensors:
    - Sensor Control 5 (for BH1620FVC)
    - Sensor Control 6 (for BH1710FVC)
    - Sensor Control 7 (for BH1730FVC)
    - Sensor Control 8 (for BH1721FVC)
    - Sensor Control 9 (for BH1780GLI)
2014-08-21 Added code for UV Sensor
    Added code for UV Sensor:
    - Sensor Control 10 (for ML8511)
2014-08-22 Added code for Temperature Sensors
    Added code for Temperature Sensors:
    - Sensor Control 20 (for BD1020HFV)
    - Sensor Control 21 (for BDJ0601HFV)
    - Sensor Control 22 (for BDE0600G)
    - Sensor Control 23 (for BDJ0550HFV)
2014-09-03 Added code for MEM Sensors
    Added code for MEM Sensors:
    - Sensor Control 15 (for KX022)
    - Sensor Control 16 (for KMX61)
2014-09-10 Added "_output" folder to project file
    This folder is required to compile successfully. If these files are
    removed, then the compiler will return an error if these folders are not
    already setup.
    [main.asm]
2014-09-15 Fixed bug: MEM sensors do not work
    Fixed bug: MEM sensors do not work
    [main.c]
2014-09-16 Updated code for MEM sensor KMX61
    Updated code for MEM sensor KMX61.
2014-09-17 Change LED binary output bits order
    Change LED binary output bits order.
2014-10-06 Baud Rate and No Sensor Connect Changes
    Change 1. UART output Baud Rate decreased to 9600 (for standard
    usage... so user doesn't need to look up the baud rate of this board).
    Change 2. Default LED output for "No device connected" is now "All ON"
    because we don't have a power indicator LED. This will show that the
    board is powered when there is no device. If device is connected, then
    the UART output will be working, thus no need for additional change.
    [main.asm, main.c]
2014-10-06 Version 1.0: Merged Temp Branch into Master Branch
    Code has been tested and works well for the Sensor Platform. As of now,
    this is the code we plan to use to load onto the sensor platform base
    boards.
2014-10-06 Version 1.0: Added PC Evaluation Tools Folder
    Moved Putty to Evaluation Tools Folder. Also added the COM port driver
    for FTDI chip on this board.
2014-10-06 Version 1.01: Added LED Flash for No Connect
    No connect condition now flashes the LEDs, instead of just leaving them
    on. Completed this for low power operation
2014-11-07 Included Hardware Files and GPLv3 Information
    [ROHM_SENSOR_PLATFORM_BASE_BOARD_BOM_REV02_20140918.xlsx, ROHM_SENSOR_PLATFORM_BASE_BOARD_SCH_REV02_20140918.DSN, SENSOR_PLATFORM_BREAKOUT_BOARD_REV01_2014-08-1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]
2014-11-10 Minor Changes to README, Added General Presentation
    [ROHM_SENSOR_PLATFORM_BASE_BOARD_BOM_REV02_20140918.xlsx, ROHM_SENSOR_PLATFORM_BASE_BOARD_SCH_REV02_20140918.DSN, SENSOR_PLATFORM_BREAKOUT_BOARD_REV01_2014-08-1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]
2014-12-08 Updated Hardware Design Files
    Updated Hardware Design files primarily for the breakout boards. Have
    updated it to the latest revision (6 boards included in the kit)
    [ROHM_SENSOR_PLATFORM_BASE_BOARD_BOM_REV02_20140918.xlsx, ROHM_SENSOR_PLATFORM_BASE_BOARD_SCH_REV02_20140918.DSN, ROHM_SENSOR_PLATFORM_BREAKOUT_BOARD_BOM__6Boar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]
2015-01-19 Adding Other Platform Guides
    Guides that help connect the sensor platform to some of the more
    commonly used platforms for development (Raspberry Pi, Riot Board,
    Arduino, BeagleBone)
2015-06-25 Added CE Testing Documents
    [ROHM_SENSOR_PLATFORM_BASE_BOARD_BOM_REV02_20140918.xlsx, ROHM_SENSOR_PLATFORM_BREAKOUT_BOARD_BOM__6BoardsOnly_REV02_20140827.xlsx]
2015-06-29 Added new folder "BOM RoHS Compliance Information"
    Added Tamara's work to the Github Repo
    [Rohm Sensor Kit BOM - 20150610 (6010428) (1).xls, Rohm Sensor Kit BOM - 20150610 (6010428).xls]
2015-10-05 Added Base Board Flashing Documentation
    Added documentation on how to program these boards using the LAPIS
    Semiconductor tool chain
2015-10-05 Added FAQ to ReadMe
    FAQ added to readme... Explains how to flash the base board
2016-07-07 Added Full CE Declaration of Conformity Documents to Repo
    see folder ...\Documentation\CE Declaration of Conformity
    [Rohm Sensor Kit BOM - 20150610 (6010428) (1).xls, Rohm Sensor Kit BOM - 20150610 (6010428).xls]
2017-03-14 Updated ReadMe
    Obsolete UV Sensor
